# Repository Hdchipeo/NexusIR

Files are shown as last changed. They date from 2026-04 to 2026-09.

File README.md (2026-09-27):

<div align="center">

  <a href="https://github.com/dangminhtam/NexusIR">
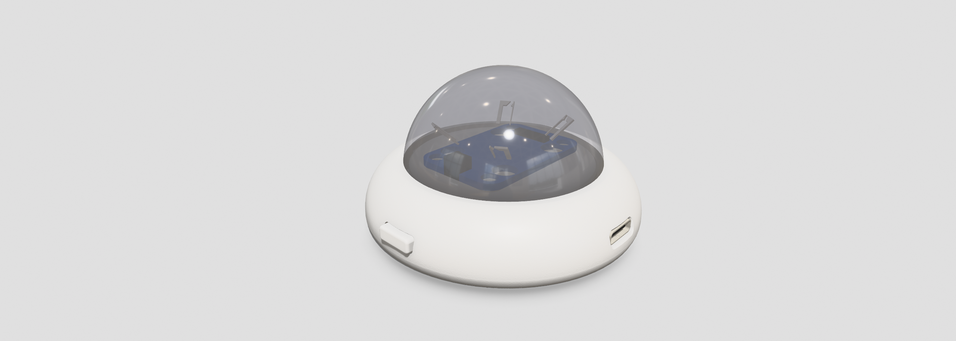
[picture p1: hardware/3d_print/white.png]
NexusIR Smart Hub
    
  </a>

  <h1>NexusIR 🛸 Universal Smart IoT & IR Hub for ESP32</h1>

  <h3>📡 Precision IR Core V3 · 🏠 Apple HomeKit & ESP RainMaker · ⚡ Event-Driven Engine · 🌐 Mesh ESP-NOW</h3>

  <p>
    <a href="https://www.espressif.com">
      
    </a>
    <a href="https://github.com/espressif/esp-idf">
      
    </a>
    <a href="./LICENSE">
      
    </a>
    
    
  </p>

  <a href="#-key-features">Key Features</a>
  |
  <a href="#-flash-via-browser-esp-web-tools">Flash via Browser</a>
  |
  <a href="#-quick-start">Quick Start</a>
  |
  <a href="#-architecture--storage-budget">Architecture & Storage</a>
  |
  <a href="#-rest-api--web-dashboard">Web & API</a>
  |
  <a href="#-host-unit-testing">Testing</a>
  |
  <a href="./README_VI.md">🇻🇳 Tiếng Việt</a>

</div>

---

**NexusIR** is an enterprise-grade, event-driven smart IoT hub engineered on **ESP-IDF v5.5** for the ESP32 series (ESP32 / ESP32-C3 / ESP32-S3). It seamlessly bridges consumer infrared appliances (Air Conditioners, Fans, TVs), multi-zone addressable RGB lighting, high-power relays, and environmental sensors into native **Apple HomeKit** and **ESP RainMaker** (Amazon Alexa & Google Assistant) ecosystems — fully controllable with sub-millisecond local latency, distributed ESP-NOW mesh networking, and an embedded offline dashboard.

<div align="center">
  <video src="picture/video.mp4" width="85%" controls></video>
  <p><i>NexusIR in action: Real-time IR capture, HomeKit pairing, and multi-zone lighting synchronization</i></p>
</div>

---

## 🌟 Key Features

Traditional smart IR remotes suffer from fragile learning, lossy pulse decoding, and cloud dependency. NexusIR introduces the **IR Core V3 Architecture**: an event-driven, hardware-decoupled engine with 20-byte packed binary format, hardware CRC32 integrity verification, atomic NVS migrations, and dynamic carrier modulation.

<table align="center">
  <tr>
    <th><div align="center"> 📡 Precision IR Core V3 </div></th>
    <th><div align="center"> 🏠 Native Dual Ecosystem </div></th>
  </tr>
  <tr>
    <td>
      <div align="center">
        Hardware RMT with 1-microsecond timing precision
        <br />
        Learns raw signals without decoding loss (AC & Fan matrix)
        <br />
        Dynamic carrier modulation (36 kHz to 56 kHz)
      </div>
    </td>
    <td>
      <div align="center">
        Native Apple HomeKit accessory protocol (HAP)
        <br />
        ESP RainMaker for Android, Alexa, and Google Assistant
        <br />
        Zero third-party bridge or cloud subscription required
      </div>
    </td>
  </tr>
  <tr>
    <td width="50%">
      <video src="picture/video.mp4" width="100%" controls></video>
    </td>
    <td width="50%">
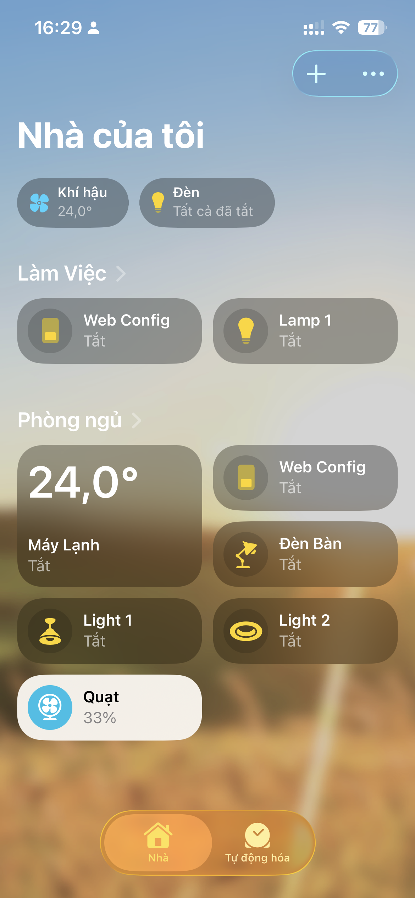
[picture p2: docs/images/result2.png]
NexusIR Web Dashboard
      
    </td>
  </tr>

  <tr>
    <td colspan="2"><!-- spacer row --></td>
  </tr>

  <tr>
    <th><div align="center"> ⚙️ Event-Driven FreeRTOS Architecture </div></th>
    <th><div align="center"> 🌐 Mesh & Distributed Sync </div></th>
  </tr>
  <tr>
    <td>
      <div align="center">
        Ultra-thin ISR (&lt; 1.5 µs) dispatches to dedicated Worker Task
        <br />
        Monotonic Session IDs eliminate stale/cross-talk captures
        <br />
        15-second hardware watchdog timer prevents task lockups
      </div>
    </td>
    <td>
      <div align="center">
        ESP-NOW low-latency Master / Slave mesh topology
        <br />
        Sub-10ms peer-to-peer transmission across room nodes
        <br />
        Configurable as Master, Slave, Standalone, or Disabled
      </div>
    </td>
  </tr>

  <tr>
    <td colspan="2"><!-- spacer row --></td>
  </tr>

  <tr>
    <th><div align="center"> 🧬 Wire Format V1 & Safe Migration </div></th>
    <th><div align="center"> 💡 Multi-Zone Lighting & Sensors </div></th>
  </tr>
  <tr>
    <td>
      <div align="center">
        Strict 20-byte packed binary header with IEEE 802.3 CRC32
        <br />
        On-Access & Background Batch migration for legacy NVS keys
        <br />
        Power-loss safe: atomic commit guarantees zero data loss
      </div>
    </td>
    <td>
      <div align="center">
        Drives up to 5× WS2812B addressable RGB LED strips
        <br />
        AHT20 temperature & humidity continuous telemetry
        <br />
        Dual relay outputs with capacitive touch button interrupts
      </div>
    </td>
  </tr>

  <tr>
    <td colspan="2"><!-- spacer row --></td>
  </tr>

  <tr>
    <th><div align="center"> 🧰 Ready Out of the Box </div></th>
    <th><div align="center"> 🧩 Complete HAL Decoupling </div></th>
  </tr>
  <tr>
    <td>
      <div align="center">
        Gzip-compressed embedded dashboard served locally
        <br />
        JSON import/export API for easy profile backup and cloning
        <br />
        360-degree IR transparent dome enclosure (.3mf ready)
      </div>
    </td>
    <td>
      <div align="center">
        Strict separation: Logic (Manager) vs Hardware (Driver)
        <br />
        Zero <code>ESP_ERROR_CHECK()</code> panics for 24/7 uptime
        <br />
        3-second safety timeout on RMT TX prevents hardware freeze
      </div>
    </td>
  </tr>
</table>

---

## ⚡ Flash via Browser (ESP Web Tools)

You can install or update NexusIR firmware directly in your browser without setting up any command line tools or installing drivers:

<div align="center">
  <a href="https://Hdchipeo.github.io/NexusIR/flash/">
    Flash via Browser
  </a>
  <p>
    👉 <a href="https://Hdchipeo.github.io/NexusIR/flash/"><strong>Open NexusIR Web Flasher</strong></a>
  </p>
</div>

> [!IMPORTANT]
> **Supported Browsers:** Google Chrome, Microsoft Edge, Opera on Windows, macOS, and Linux (requires Web Serial API support). Plug your ESP32-C3 via USB-C cable and click the button above!

---

## 📦 Quick Start

<div align="center">
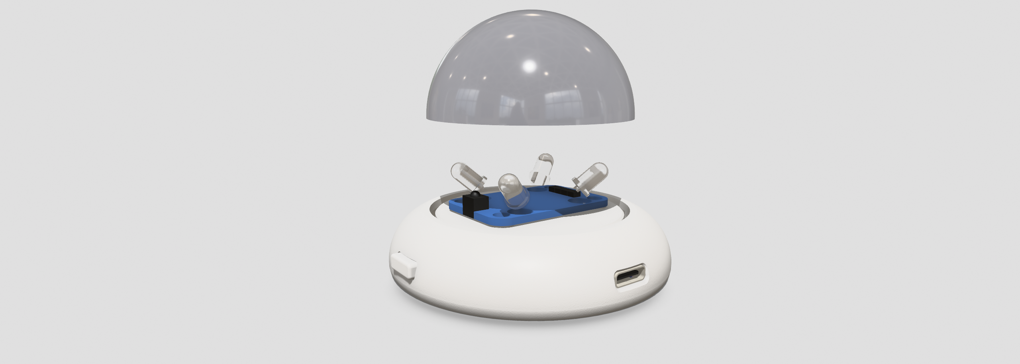
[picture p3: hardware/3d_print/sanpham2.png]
NexusIR Internal Board Layout
  
</div>

NexusIR supports all ESP32-family chips with native RMT peripherals (ESP32, ESP32-C3, ESP32-S3). Defaults below are optimized for **ESP32-C3**:

### Hardware Pinout Map

| Peripheral | Default GPIO | Driver Type | Description |
| :--- | :---: | :---: | :--- |
| **IR Transmitter** | `GPIO 4` | RMT Output | Drives IR LED via NPN/MOSFET amplifier |
| **IR Receiver** | `GPIO 7` | RMT Input | TSOP38238 demodulator (Internal Pull-Up) |
| **RGB LED Lamp 1–5** | `2, 8, 9, 10, 18` | RMT / SPI | WS2812B addressable LED data lines |
| **I2C Bus (AHT20)** | `SDA=6, SCL=5` | I2C Master | Temperature & humidity sensor (400 kHz) |
| **Relay 1 / 2** | `GPIO 12, 13` | GPIO Output | High-power relay coils |
| **Touch Buttons** | `GPIO 14, 15` | GPIO Input | Capacitive touch switch interrupts |
| **System Button** | `GPIO 3` | GPIO Input | Factory reset & configuration toggle |

> [!NOTE]
> All GPIO mappings can be customized dynamically in `idf.py menuconfig` &rarr; `Device Configuration` &rarr; `IR Hardware`.

---

### Flash Pre-Built Firmware (CLI)

If you prefer flashing via terminal, binaries are available in [`firmware/`](firmware/):

```bash
# Example: Flash NexusIR on ESP32-C3 (iOS HomeKit build)
python -m esptool --chip esp32c3 -b 460800 write_flash \
  0x00000 firmware/esp32c3/ios/bootloader.bin \
  0x08000 firmware/esp32c3/ios/partition-table.bin \
  0x15000 firmware/esp32c3/ios/ota_data_initial.bin \
  0x20000 firmware/esp32c3/ios/nexus-ir.bin \
  0x3e0000 firmware/esp32c3/ios/storage.bin
```

> [!TIP]
> Replace `ios` with `android` in the path above for **ESP RainMaker** (Android, Alexa, Google Home) builds.

---

### Build from Source

Ensure you have **ESP-IDF v5.5.x** installed:

```bash
# 1. Activate ESP-IDF environment
. ~/esp/esp-idf/export.sh

# 2. Set target chip
idf.py set-target esp32c3    # Or esp32 / esp32s3

# 3. Configure features (Ecosystem, GPIOs, ESP-NOW)
idf.py menuconfig

# 4. Build, flash, and monitor
idf.py build
idf.py -p /dev/tty.usbserial-XXXX flash monitor
```

---

### Pairing & Wi-Fi Provisioning

<table align="center">
  <tr>
    <th width="50%"><div align="center"> 🍎 Apple HomeKit (iOS) </div></th>
    <th width="50%"><div align="center"> 🤖 ESP RainMaker (Android / Alexa / Google) </div></th>
  </tr>
  <tr>
    <td>
      <ol>
        <li>Connect to Wi-Fi hotspot: <code>NexusIR-Setup-XXXX</code></li>
        <li>Captive portal automatically opens &rarr; Select your home Wi-Fi & enter credentials.</li>
        <li>Open Apple <b>Home App</b> &rarr; Tap <b>+</b> &rarr; <b>Add Accessory</b> &rarr; <b>More Options</b>.</li>
        <li>Select <b>NexusIR Bridge</b> &rarr; Enter Setup Code: <code>111-22-333</code>.</li>
      </ol>
    </td>
    <td>
      <ol>
        <li>Open the <b>ESP RainMaker</b> App (Google Play / App Store).</li>
        <li>Tap <b>Add Device</b> &rarr; Scan QR Code on device or discover via BLE / SoftAP.</li>
        <li>Enter Proof of Possession (PoP): <code>12345678</code>.</li>
        <li>Link RainMaker skill in the Alexa / Google Home App for voice control.</li>
      </ol>
    </td>
  </tr>
</table>

---

## 🏗️ Architecture & Storage Budget

### Distributed Node Topologies

NexusIR supports flexible operating modes configured on a per-peripheral basis:

```
┌─────────────────────────────────────────────────────────┐
│        iOS Home App / RainMaker App / Web Dashboard     │
└────────────────────────┬────────────────────────────────┘
                         │ Wi-Fi (HAP / MQTT)
               ┌─────────▼──────────┐
               │   Master Node      │
               │  HomeKit + Sync    │
               │  Engine + Web UI   │
               └──┬──────────────┬──┘
        ESP-NOW   │              │   ESP-NOW
           ┌──────▼────┐   ┌────▼───────┐
           │ Slave: AC │   │ Slave: LED │
           │ IR TX/RX  │   │ WS2812B ×5 │
           └────────────┘   └────────────┘
```

- **Master:** Hosts HomeKit / RainMaker service, sync engine, and routes commands over ESP-NOW.
- **Slave:** Dedicated hardware node responding to sub-10ms ESP-NOW packets (e.g. lamp on a nightstand, IR blaster on a ceiling).
- **Standalone:** Self-contained single-chip operation with all services running locally.

---

### Wire Format V1 Binary Specification

Every learned signal is encapsulated in a compact, portable binary structure `#pragma pack(push, 1)`:

```
+-----------------------------------------------------------------------+
| Magic (4B)  | Ver (1B) | Flags (1B) | Carrier (2B) | Duty (1B) | Rep (1B) |
| 0x5249584E  |   0x01   | Bitmask    |  38000 Hz    |    33%    |  0 or 1  |
+-----------------------------------------------------------------------+
| Gap (2B)    | DurCount (2B) |       CRC32 (4B, Little-Endian)         |
| 40 ms       | N halfwords   | esp_rom_crc32_le over raw pulse payload |
+-----------------------------------------------------------------------+
| Payload: uint16_t durations[DurCount]                                |
| [Mark 0, Space 0, Mark 1, Space 1, ... Mark N-1]                      |
+-----------------------------------------------------------------------+
```

### Quantitative Storage Budget (IR-12)

NexusIR allocates **32 KB** (8 Flash pages × 4096B) for the `nvs` partition (~27.5 KB effective user space):

| Appliance Type | Average Pulses | Payload Size | Total Record (V1) | NVS Slots | Est. Capacity in 32KB NVS |
| :--- | :---: | :---: | :---: | :---: | :---: |
| **TV / Fan (NEC / RC5)** | 32 - 68 pulses | 64 - 136 B | **84 - 156 bytes** | ~3 - 5 entries | **180 - 220 keys** |
| **Air Conditioner (Matrix)** | 100 - 240 pulses | 200 - 480 B | **220 - 500 bytes** | ~7 - 16 entries | **35 - 45 AC states** |

> [!TIP]
> A full AC profile (16 temperature states: Off, 16°C – 30°C) consumes **~5.6 KB**. Together with 20 TV/Fan keys (~2.5 KB), total memory usage is **~8.1 KB / 27.5 KB (~30%)**, leaving 70% headroom for system metadata.

---

## 🌐 REST API & Web Dashboard

NexusIR includes a lightweight, gzip-compressed local web dashboard accessible at `http://nexusir-xxxx.local`.

<div align="center">
  NexusIR Web Dashboard
</div>

### Core HTTP Endpoints

| Endpoint | Method | Status Codes | Description |
| :--- | :---: | :---: | :--- |
| `/api/learn/status` | `GET` | `200` | Returns live learning state (`ARMED`, `CAPTURED`, `TIMEOUT`), session ID, and pulse count |
| `/api/send?key={key}` | `POST` | `200, 404, 409, 500` | Transmits an IR key. Returns **409 Conflict** if learning is currently active |
| `/api/ir/export?key={key}` | `GET` | `200, 404` | Exports key metadata (carrier, repeats, CRC32) and raw duration array as JSON |
| `/api/ir/import?key={key}` | `POST` | `200, 400` | Validates, normalizes, serializes V1 record, and stores imported JSON in NVS |
| `/api/ir/storage` | `GET` | `200` | Returns NVS health: used entries, free entries, and estimated AC/TV slots remaining |
| `/api/ir/migrate` | `POST` | `200` | Manually triggers full partition audit and migration of legacy records |

---

## 🧪 Host Unit Testing

To accelerate development and prevent regressions without physical hardware, the IR Waveform Engine is completely decoupled from RTOS dependencies. You can compile and run the test suite on **macOS / Linux** in **&lt; 50 milliseconds**:

```bash
# Compile and execute host regression test suite
clang -O2 -Wall -Wextra -Icomponents/mgr_ir_protocols/include \
  test/test_ir_waveform_host.c -o test/test_ir_waveform_host && ./test/test_ir_waveform_host
```

```text
=====================================================
  Running NexusIR Waveform Engine Host Test Suite    
=====================================================
  [PASS] test_waveform_normalization
  [PASS] test_odd_duration_overread_prevention
  [PASS] test_v1_serialization_and_deserialization
  [PASS] test_crc32_corruption_detection
  [PASS] test_legacy_raw_upgrade
  [PASS] test_legacy_matrix_upgrade
=====================================================
  ALL 6 HOST UNIT TESTS PASSED SUCCESSFULLY!         
=====================================================
```

---

## 🖨️ 3D Enclosure

NexusIR features a custom dome enclosure engineered for optimal **360° omnidirectional IR radiation** with high infrared transmittance. Ready-to-print `.3mf` files are located in [`hardware/3d_print/`](hardware/3d_print/):

<table align="center">
  <tr>
    <th><div align="center"> Matte Black </div></th>
    <th><div align="center"> Pearl White </div></th>
    <th><div align="center"> Cyber Orange </div></th>
    <th><div align="center"> Pastel Pink </div></th>
  </tr>
  <tr>
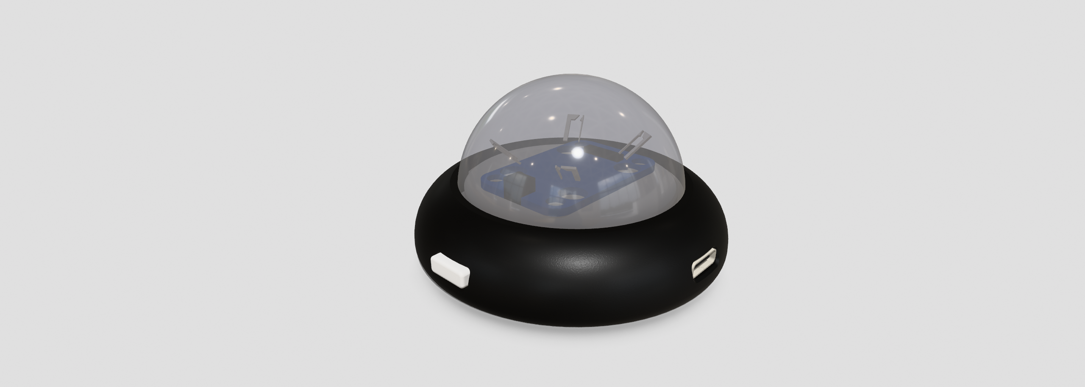
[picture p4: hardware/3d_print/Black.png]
Black
    <td></td>
    <td>White</td>
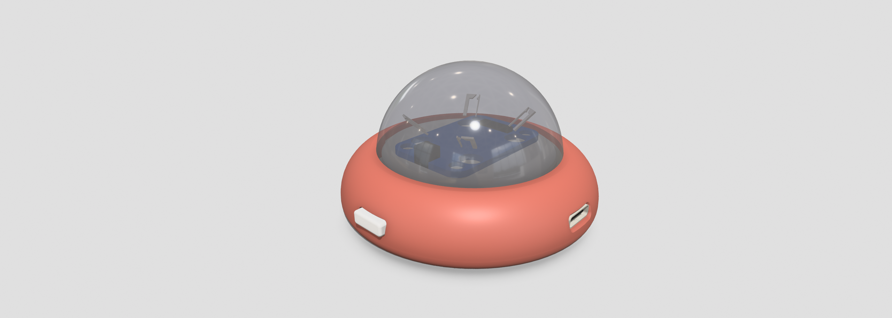
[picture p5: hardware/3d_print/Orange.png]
Orange
    <td></td>
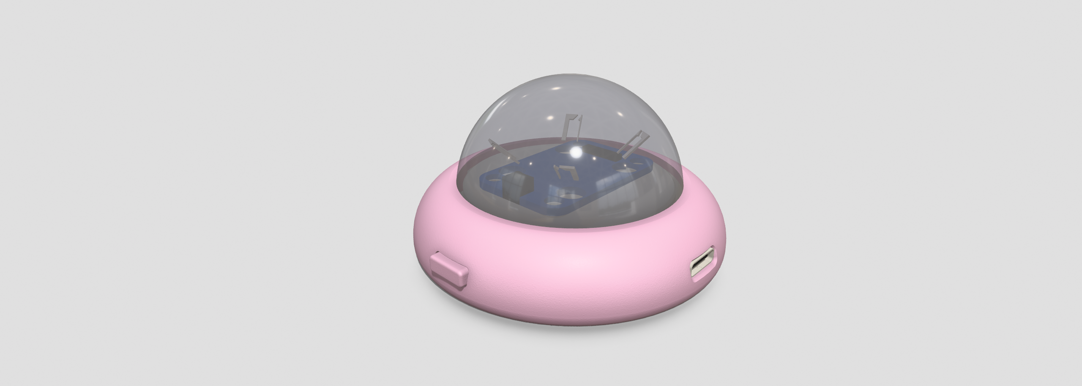
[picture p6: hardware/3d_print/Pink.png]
Pink
    <td></td>
  </tr>
</table>

---

## 📷 Follow Us

If NexusIR powers your smart home, please give the project a star! ⭐

<div align="center">
  <a href="https://www.star-history.com/?repos=dangminhtam%2FNexusIR&type=date&legend=top-left">
    <picture>
      <source media="(prefers-color-scheme: dark)" srcset="https://api.star-history.com/chart?repos=dangminhtam%2FNexusIR&type=date&theme=dark&legend=top-left" />
      <source media="(prefers-color-scheme: light)" srcset="https://api.star-history.com/chart?repos=dangminhtam%2FNexusIR&type=date&legend=top-left" />
      NexusIR Star History
    </picture>
  </a>
</div>

---

## Acknowledgements

- [Espressif Systems](https://github.com/espressif) for the outstanding ESP-IDF framework and RMT driver.
- [HomeKit ADK & ESP-HomeKit-SDK](https://github.com/espressif/esp-homekit-sdk) for Apple HomeKit Accessory Protocol support.
- [ESP RainMaker](https://rainmaker.espressif.com/) for cloud-agnostic Android and voice assistant integration.
- [IRremoteESP8266](https://github.com/crankyoldgit/IRremoteESP8266) for reference IR timing formats.
- Inspired by Espressif's open-source engineering standards ([esp-claw](https://github.com/espressif/esp-claw)).

---

## License

This project is open-sourced under the **MIT License**. See the [LICENSE](LICENSE) file for complete details.

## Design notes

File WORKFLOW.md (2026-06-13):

# Project Workflows

This document explains the internal workflows and logic for the core components of the NexusIR Device.

## 1. Infrared (IR) Workflow

### Learning Mode
1.  **Trigger**: User clicks "Start Learning" on Web UI or holds the physical button (Long Press).
2.  **State Change**: LED changes to **Yellow/Blink**.
3.  **RX Task**: The RMT Receiver channel is enabled and waits for signals.
4.  **Capture**: When an IR signal is detected, the RMT interrupt captures the pulse train into a buffer.
5.  **Save**: User calls "Save" via Web UI, storing it under a custom brand (e.g. `Fan1`).
    *   The captured symbols are serialized and written to **NVS**.
6.  **Idle**: System returns to Idle state.

### Sending Mode (ESP-NOW Master-Slave)
1.  **Trigger**: HomeKit App command (e.g., Turn AC/Fan ON) triggers the Master node.
2.  **Broadcast**: Master node sends the state (power, mode, temp/speed) via ESP-NOW to the specific Slave MAC address configured in `menuconfig`.
3.  **Slave Translation**:
    *   The Slave node receives the ESP-NOW packet.
    *   It looks up the configured `brand` in its local NVS.
    *   If found, the pulse data (symbols) is loaded into RAM.
4.  **Transmission**:
    *   RMT Transmitter channel on the Slave sends the carrier-modulated signal (38kHz) to the IR LED.

---

## 2. Wi-Fi Configuration Workflow

### Provisioning (First Time Setup)
1.  **Boot**: Device checks if Wi-Fi credentials exist in NVS.
2.  **Missing Credentials**:
    *   Device starts **SoftAP Mode** with SSID `NexusIR-Setup-XXXX`.
    *   LED indicates **Provisioning Mode** (Blue Running).
    *   User connects to SoftAP or uses RainMaker App to scan QR code.
3.  **Handshake**:
    *   App sends Wi-Fi SSID/Password via Protocomm (HTTP/BLE).
    *   Device verifies Proof of Possession (PoP).
4.  **Connect**:
    *   Device saves credentials to NVS.
    *   Device reboots or switches to **Station Mode** to connect to the router.

### Connection & Fallback
1.  **Station Mode**: Device attempts to connect to configured Wi-Fi.
    *   **Success**: LED changes to **Green/Static** (or User Color). Connects to RainMaker MQTT.
    *   **Failure**: If connection fails repeatedly (timeout):
        *   Device enables **Fallback AP** (`NexusIR-Recovery`).
        *   LED indicates **Warning/Provisioning**.
        *   Web UI is accessible via the AP to allow re-configuration.

---

## 3. Over-The-Air (OTA) Updates

### Automatic Check (Background)
1.  **Timer**: A background task runs periodically (default: 1 hour).
2.  **Check Version**:
    *   Device fetches `version.txt` from `CONFIG_OTA_SERVER_URL` (e.g., Surge.sh).
    *   Compares remote version with `PROJECT_VERSION`.
3.  **Update**:
    *   If remote > local: Downloads `.bin` firmware.
    *   Writes to the Passive Partition.
    *   Sets Passive as Active and Reboots.
4.  **Rollback**: If new firmware crashes on boot, ESP32 automatically rolls back to the previous partition.

### Manual Trigger (Web UI)
1.  **User Action**: User clicks "Check Update" -> "Update Now" on Web UI.
2.  **API Call**: Front-end checks version API.
3.  **Execution**: Triggers the same internal download/flash logic as the automatic process.

---

## 4. Apple HomeKit Workflow (Bridge Mode)

### Initialization
1.  **HAP Init**: Application initializes the HomeKit Accessory Protocol (HAP) over Wi-Fi.
2.  **Bridge Creation**: A single HomeKit Bridge accessory is created.
3.  **Dynamic Accessories**: Based on `menuconfig`, bridged accessories are instantiated:
    *   **Thermostat**: For AC control.
    *   **Fan v2**: For Fan control.
    *   **Lightbulbs (1-5)**: For each enabled LED Lamp.
    *   **Temperature Sensor**: For AHT20 sensor data.
    *   **Dynamic IR Accessories**: Scans NVS during boot for learned Tivi and Custom IR keys. Each Tivi power button and Custom button is instantiated as a Bridged Accessory (Switch).
4.  **State Restoration**: Reads the last known state from NVS and populates HomeKit characteristics *before* starting the HAP server.

### Reboot-to-Sync Logic
To maintain stability and comply with HomeKit/RainMaker registration constraints:
1. **Learn**: User teaches the hub a new IR command via the Web Dashboard.
2. **Persistence**: Command is saved to NVS with metadata (Brand, Name, Icon).
3. **Trigger**: Web UI prompts the user to "Restart Hub".
4. **Boot Sync**: Upon restart, the `int_homekit` and `int_rainmaker` modules fetch the updated list from NVS and register the new accessories before the cloud connection is established.

### Cloud to Device (Control)
1.  **User**: Toggles "Power On" in Apple Home App.
2.  **HAP Server**: Triggers the `write_cb` (e.g. `led_write`, `fan_write`, `ac_write`).
3.  **Device Logic**:
    *   Code updates the state locally.
    *   If Master, it bridges the command via ESP-NOW to the specific Slave's MAC address.
    *   If Standalone, it handles the hardware directly (e.g. PWM LED or IR send).
    *   Saves new state to NVS.

### Device to Cloud (State Update)
1.  **Event**: ESP-NOW Slave sends sensor data, or Web UI changes a state locally.
2.  **Report**: Device calls `hap_char_update_val()` to notify Apple HomeKit of the change.
3.  **App**: UI immediately reflects the new state.

---

## 5. Web UI Workflow

### Architecture
*   **Server**: ESP32 runs a lightweight HTTP Server (`esp_http_server`).
*   **Front-end**: Single Page Application (embedded HTML/CSS/JS string in `app_web.c`).

### Interaction
1.  **Access**: User visits `http://nexusir-xxxx.local`.
2.  **Load**: Browser downloads the HTML/JS.
3.  **JS Init**: JavaScript `fetch()` calls `/api/ir/list` to get saved keys.
4.  **Commands**:
    *   **Save Key**: `POST /api/save?key=my_key` -> Device enters Learn Mode -> Saves Result.
    *   **Send Key**: `POST /api/send?key=my_key` -> Device transmits IR.
    *   **Wifi Config**: `POST /api/wifi/config` -> Updates NVS -> Restart.

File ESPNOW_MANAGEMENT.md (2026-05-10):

# NexusIR ESP-NOW Device Management Protocol

This document describes the architecture and logic for the device management system (Discovery, Add, Remove) based on the **Master-Pull** mechanism for the **NexusIR** ecosystem.

## 1. Architectural Overview
Instead of manual MAC address configuration, the system utilizes a **Master-Initiated Discovery (Pull)** mechanism:
* **Master (Hub)**: Sends a Broadcast packet to search for nearby nodes.
* **Slave (End-device)**: Listens and responds only when a request from the Master is received.
* **Management**: All Peer information (MAC, Name) is persistently stored in the Master's **NVS** (Non-Volatile Storage).

---

## 2. Packet Structure (Data Structure)

To ensure consistency and filter out interference, all ESP-NOW packets must adhere to the following structure:

```c
// Message type definitions
typedef enum {
    NEXUS_SCAN_REQ    = 0x01,  // Master: "Is anyone there?"
    NEXUS_SCAN_RESP   = 0x02,  // Slave: "I'm here + [Information]"
    NEXUS_CONTROL     = 0x03,  // Master: Send control command (IR/LED)
    NEXUS_KEEPALIVE   = 0x04   // Slave: Periodic status report
} nexus_msg_type_t;

// NexusIR Packet Structure
typedef struct {
    uint8_t magic_byte;        // Project Identifier (Default: 0x4E - 'N')
    uint8_t msg_type;          // Message type (nexus_msg_type_t)
    char device_name[16];      // Device name (e.g., "Nexus-Fan-01")
    uint8_t device_type;       // Device type (1: Fan, 2: AC, 3: Light)
    uint8_t payload[200];      // Custom data (IR commands, status, etc.)
} nexus_packet_t;
```

---

## 3. Operational Workflows

### 3.1. Discovery Flow
This process allows the Master to find Slave devices within range without prior knowledge of their MAC addresses.

1.  **Trigger**: User clicks **"Scan"** on the Web UI.
2.  **Broadcast**: Master sends a `NEXUS_SCAN_REQ` packet to the broadcast address `FF:FF:FF:FF:FF:FF`.
3.  **Slave Processing**:
    * Receives the packet and verifies `magic_byte == 0x4E`.
    * Waits for a **Random Delay (0-500ms)** to prevent packet collisions.
    * Sends a `NEXUS_SCAN_RESP` packet (containing MAC and Name) directly to the Master (Unicast).
4.  **Collection**: Master opens a data reception window for 5 seconds, collecting all responses into a temporary array.
5.  **UI Display**: Returns a JSON list containing: MAC, Name, and RSSI to the Web UI.

### 3.2. Add Peer Flow
The process of registering a Slave into the official management list.

1.  **Selection**: User selects a device from the discovered list and clicks **"Add"**.
2.  **API Call**: Web UI sends a `POST /api/espnow/add` request with the MAC Address.
3.  **Registration**: 
    * Master calls `esp_now_add_peer()` to register the protocol.
    * Saves the `{MAC, Name, Type}` information into a table within the **NVS**.
4.  **Confirmation**: Master sends a vibration or LED flash command to the Slave to confirm successful connection.

### 3.3. Disconnect/Unpair Flow

1.  **Action**: User clicks **"Delete"** next to a device in the "My Devices" list.
2.  **Logic**: 
    * Master removes the MAC from the ESP-NOW Peer list using `esp_now_del_peer()`.
    * Deletes the corresponding record from the NVS.
3.  **Update**: Web UI refreshes to reflect the current device list.

---

## 4. State Management and Connectivity (Keep-alive)

Although ESP-NOW is "Connectionless," the following is used to display Online/Offline status on the Web UI:
* **Heartbeat**: Added Slaves will send a `NEXUS_KEEPALIVE` packet every 60 seconds.
* **Timeout**: If the Master does not receive a message from a specific MAC for 3 minutes, the device is marked as **Offline**.
* **RSSI**: Signal bars are updated based on the signal strength of the most recent Heartbeat packet.

---

## 5. Web UI & Backend Integration

### Required API Endpoints
| Method | Endpoint | Description |
| :--- | :--- | :--- |
| `GET` | `/api/espnow/scan` | Triggers broadcast and returns the list of discovered devices. |
| `POST` | `/api/espnow/add` | Adds the MAC to the NVS and Peer List. |
| `GET` | `/api/espnow/list` | Retrieves the list of already paired devices. |
| `DELETE` | `/api/espnow/remove` | Removes a device from the management system. |

### NVS Data Handling
* Data is stored as a **Blob** or using a structured `peer_X` key format (where X is an index) to optimize read/write operations without exhausting NVS memory.

---

> **Technical Note**: In environments with multiple Wi-Fi networks, ensure the Master and all Slaves are operating on the same **Wi-Fi Channel** so that ESP-NOW can discover each other.

Does this English version match the professional tone you were looking for for your project?

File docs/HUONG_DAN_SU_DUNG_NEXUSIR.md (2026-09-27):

# NexusIR Smart Hub

### Hướng dẫn sử dụng

**Trung tâm điều khiển hồng ngoại và ánh sáng thông minh cho hệ sinh thái Apple HomeKit & ESP RainMaker.**

NexusIR Smart Hub

Phiên bản tài liệu: **1.1**  
Ngày phát hành: **23/09/2026**  
Áp dụng cho: **NexusIR Firmware v1.4.0 trở lên (ESP32 / ESP32-C3 / ESP32-S3)**

---

## Nội dung

1. [Bắt đầu trong 5 phút](#1-bắt-đầu-trong-5-phút)
2. [Trước khi sử dụng](#2-trước-khi-sử-dụng)
3. [Làm quen với sản phẩm](#3-làm-quen-với-sản-phẩm)
4. [Thiết lập lần đầu](#4-thiết-lập-lần-đầu)
5. [Sử dụng hằng ngày](#5-sử-dụng-hằng-ngày)
6. [Học lệnh hồng ngoại (IR Learning) cho Điều hòa & Quạt trên Web Config](#6-học-lệnh-hồng-ngoại-ir-learning-cho-điều-hòa--quạt-trên-web-config)
7. [Tùy chỉnh và bảo quản](#7-tùy-chỉnh-và-bảo-quản)
8. [Xử lý sự cố](#8-xử-lý-sự-cố)
9. [Câu hỏi thường gặp](#9-câu-hỏi-thường-gặp)
10. [Thông số và hỗ trợ](#10-thông-số-và-hỗ-trợ)

---

## 1. Bắt đầu trong 5 phút

Chỉ với 4 bước đơn giản, bạn sẽ kích hoạt NexusIR và sẵn sàng điều khiển điều hòa, quạt và hệ thống đèn LED thông qua ứng dụng Apple Home hoặc giọng nói với Siri.

1. **Cấp nguồn:** Cắm cáp USB Type-C (5V/2A) vào NexusIR. Đèn LED báo hiệu sẽ sáng lên.
2. **Kết nối mạng cài đặt:** Mở Wi-Fi trên iPhone, chọn mạng **NexusIR-Setup-XXXX** (hoặc *GhostMagic-Setup-XXXX*).
3. **Cấu hình Wi-Fi:** Trang đăng nhập sẽ tự mở. Chọn Wi-Fi 2.4GHz nhà bạn, nhập mật khẩu và bấm **Join**. Thiết bị sẽ tự khởi động lại.
4. **Ghép nối Apple Home:** Mở ứng dụng **Nhà (Apple Home)**, chọn **(+) -> Thêm phụ kiện**, chọn *NexusIR Bridge* và nhập mã thiết lập: **`111-22-333`**.

**Hoàn tất khi:** Biểu tượng cầu nối NexusIR xuất hiện trên màn hình chính ứng dụng Apple Home, đèn LED trạng thái chuyển sang màu xanh dương ổn định.

---

## 2. Trước khi sử dụng

### Trong hộp có gì

- Thiết bị NexusIR Smart Hub × 1
- Cáp nguồn USB Type-C chống nhiễu (1.0m) × 1
- Thẻ hướng dẫn nhanh kèm mã QR Apple HomeKit × 1
- Băng keo định vị 3M chuyên dụng × 1

### Bạn cần chuẩn bị

- **Nguồn điện:** Củ sạc chuẩn USB 5V, tối thiểu 1.5A – 2A (đặc biệt khi kết nối với các dải đèn LED WS2812B).
- **Mạng Wi-Fi:** Băng tần **2.4 GHz** (802.11 b/g/n) đang hoạt động ổn định.
- **Thiết bị điều khiển:** iPhone hoặc iPad chạy iOS/iPadOS 15.0 trở lên, đã đăng nhập tài khoản iCloud và bật sẵn Bluetooth, Dịch vụ định vị.

> **Lưu ý quan trọng:** NexusIR không hỗ trợ băng tần Wi-Fi 5 GHz đơn thuần. Nếu bộ phát Wi-Fi nhà bạn dùng chung một tên (SSID) cho cả 2.4 GHz và 5 GHz, hãy tạm thời tắt gộp băng tần (Band Steering) hoặc tách riêng sóng 2.4 GHz trong lúc cài đặt.

---

## 3. Làm quen với sản phẩm

NexusIR sở hữu thiết kế hình khối vòm khí động học, bố trí mảng thấu kính quang học giúp phát tín hiệu hồng ngoại 360 độ bao phủ toàn bộ không gian phòng.

| Vị trí | Thành phần phần cứng | Chức năng hoạt động |
|:---:|---|---|
| **1** | **Vòm phát hồng ngoại 360° (IR Blaster)** | Mảng LED phát hồng ngoại 940nm công suất cao, điều khiển điều hòa, quạt, TV từ mọi góc độ. |
| **2** | **Mắt thu hồng ngoại (IR Receiver)** | Cảm biến thu tín hiệu 38 kHz, dùng để học lệnh trực tiếp từ các remote điều khiển vật lý. |
| **3** | **Cảm biến môi trường AHT20** | Cảm biến tích hợp đo nhiệt độ và độ ẩm phòng theo thời gian thực (chuẩn I2C). |
| **4** | **Cổng mở rộng LED WS2812B & Relay** | Kết nối tối đa 5 kênh dải đèn LED RGB lập trình và 2 kênh tiếp điểm relay điều khiển thiết bị điện. |
| **5** | **Nút bấm đa năng (System Button)** | Nhấn 1 lần: Đổi chế độ đèn; Nhấn giữ 5 giây: Xóa cài đặt Wi-Fi và đưa máy về chế độ cấu hình. |
| **6** | **Cổng nguồn Type-C** | Tiếp nhận nguồn điện DC 5V tiêu chuẩn. |

### Trạng thái đèn báo trên thiết bị

| Màu sắc & Kiểu nháy | Ý nghĩa trạng thái | Bạn cần làm gì |
|---|---|---|
| **Nhấp nháy vàng chậm** | Thiết bị đang ở chế độ chờ cài đặt (SoftAP). | Mở Wi-Fi điện thoại kết nối vào `NexusIR-Setup-XXXX`. |
| **Nhấp nháy xanh lá nhanh** | Đang kết nối vào mạng Wi-Fi gia đình. | Đợi 5–10 giây để thiết bị hoàn tất xác thực. |
| **Xanh dương sáng tĩnh** | Hoạt động bình thường, đã đồng bộ Apple HomeKit. | Sẵn sàng điều khiển qua Home app hoặc Siri. |
| **Nháy đỏ 2 lần** | Sai mật khẩu Wi-Fi hoặc mất kết nối router. | Kiểm tra lại mật khẩu Wi-Fi hoặc khởi động lại router. |
| **Nháy tím nhịp thở (Breathing)** | Đang nhận/học mã lệnh hồng ngoại qua Web UI. | Hướng remote vào thiết bị và bấm phím cần học. |

---

## 4. Thiết lập lần đầu

### Phần I: Cấu hình mạng Wi-Fi (Wi-Fi Provisioning)

Kết nối NexusIR vào mạng Wi-Fi gia đình để thiết bị hòa mạng cục bộ.

**Trước khi bắt đầu:** Cắm nguồn cho NexusIR, đảm bảo đèn báo nhấp nháy vàng chậm.

1. **Kết nối Wi-Fi thiết bị:** Trên iPhone, vào **Cài đặt (Settings) -> Wi-Fi**. Tìm và chọn mạng có tên **NexusIR-Setup-XXXX** (hoặc *GhostMagic-Setup-XXXX*).
2. **Xác nhận kết nối:** Chờ xuất hiện dấu tích xanh bên cạnh tên mạng. Thông báo *"Mạng không bảo mật"* hoặc *"Không có kết nối Internet"* là bình thường.
3. **Mở trang cấu hình:** Màn hình **Captive Portal** sẽ tự động hiển thị. Nếu không thấy, mở Safari và truy cập địa chỉ IP: **`192.168.4.1`**.
4. **Chọn Wi-Fi nhà bạn:** Trong danh sách mạng quét được, chạm vào tên Wi-Fi nhà bạn (băng tần 2.4GHz).
5. **Nhập mật khẩu & Kết nối:** Nhập chính xác mật khẩu vào ô, sau đó nhấn nút **Join**.
6. **Lưu cấu hình:** Màn hình sẽ hiện thông báo *"Success! Rebooting..."*. NexusIR lưu thông tin vào bộ nhớ Flash NVS và tự khởi động lại.

**Hoàn tất khi:** NexusIR phát tín hiệu đèn xanh lá rồi chuyển sang trạng thái sẵn sàng. Điện thoại của bạn tự động kết nối lại mạng Wi-Fi gia đình.

---

### Phần II: Đồng bộ với Apple HomeKit

Đưa toàn bộ thiết bị ngoại vi của NexusIR vào hệ sinh thái Apple Home.

**Trước khi bắt đầu:** Đảm bảo iPhone đang kết nối cùng mạng Wi-Fi gia đình với NexusIR.

1. **Thêm phụ kiện:** Mở ứng dụng **Nhà (Apple Home)** trên iPhone. Nhấn vào biểu tượng dấu **(+)** ở góc trên bên phải, chọn **Thêm phụ kiện (Add Accessory)**.
2. **Nhập mã thủ công:** Chọn dòng chữ màu xanh *"Tôi không có mã hoặc không thể quét"*, sau đó chọn **NexusIR Bridge** (hoặc *GhostLamp Bridge*).
3. **Điền mã ghép nối:** Nhập mã thiết lập gồm 8 chữ số: **`111-22-333`** (nhập liền `11122333`).
4. **Xác nhận kết nối:** Khi xuất hiện hộp thoại *"Phụ kiện chưa được chứng nhận"*, hãy nhấn chọn **Vẫn thêm (Add Anyway)**.
5. **Phân bổ phòng:** Chọn vị trí phòng cho Cầu nối (ví dụ: *Phòng khách*), nhấn **Tiếp tục**.
6. **Đặt tên phụ kiện:** Lần lượt đặt tên cho Điều hòa, Quạt, Cảm biến nhiệt độ và các dải đèn LED kết nối theo ý muốn.
7. **Hoàn tất:** Nhấn **Xong (Done)**.

**Hoàn tất khi:** Tất cả các biểu tượng (Điều hòa, Đèn, Cảm biến, Quạt) xuất hiện đầy đủ trong phòng tương ứng trên ứng dụng Apple Home.

---

## 5. Sử dụng hằng ngày

### Điều khiển qua ứng dụng Apple Home

- **Bật/Tắt tức thời:** Chạm nhẹ vào biểu tượng Đèn, Quạt hoặc Điều hòa để bật/tắt nhanh.
- **Điều chỉnh độ sáng & màu sắc:** Nhấn giữ vào biểu tượng Đèn để kéo thanh trượt độ sáng (0–100%) hoặc chọn màu sắc từ vòng xoay 16 triệu màu.
- **Điều chỉnh nhiệt độ điều hòa:** Nhấn giữ biểu tượng Điều hòa để xoay chỉnh nhiệt độ mong muốn (16°C – 30°C) hoặc đổi chế độ Làm mát (Cool), Sưởi (Heat), Tự động (Auto).
- **Theo dõi môi trường:** Nhiệt độ và độ ẩm phòng từ cảm biến AHT20 luôn được cập nhật liên tục trên thanh trạng thái đầu trang của ứng dụng Nhà.

### Ra lệnh bằng giọng nói qua Siri

Bạn có thể ra lệnh rảnh tay bằng tiếng Việt hoặc tiếng Anh trên iPhone, iPad, Apple Watch hoặc HomePod:

- *"Hey Siri, bật đèn phòng khách."*
- *"Hey Siri, chỉnh đèn phòng khách sang màu vàng ấm 50%."*
- *"Hey Siri, đặt điều hòa 24 độ."*
- *"Hey Siri, nhiệt độ phòng ngủ hiện tại là bao nhiêu?"*
- *"Hey Siri, tắt tất cả thiết bị khi tôi ra ngoài."*

---

## 6. Học lệnh hồng ngoại (IR Learning) cho Điều hòa & Quạt trên Web Config

NexusIR sở hữu công cụ Web Config trực quan, cho phép học lệnh chính xác từ bất kỳ remote vật lý nào (kể cả các thương hiệu quạt nội địa hoặc điều hòa hiếm gặp).

### 6.1. Cách truy cập Web Config

1. Mở trình duyệt (Safari hoặc Chrome) trên thiết bị cùng mạng Wi-Fi với hub.
2. Truy cập tên miền mDNS: **`http://nexusir-xxxx.local`** (với `xxxx` là 4 ký tự cuối MAC in trên tem) hoặc gõ địa chỉ IP nội bộ của hub (ví dụ: `http://192.168.1.50`).
3. *(Tùy chọn tiện lợi)*: Trong ứng dụng Apple Home, bạn có thể gạt bật công tắc ảo **Web Config** để hub phát tín hiệu nhận diện.

### 6.2. Chuẩn bị trước khi học lệnh

- Đặt remote gốc hướng thẳng vào mắt thu IR trên hub ở khoảng cách **5 cm – 10 cm**.
- Tránh ánh sáng mặt trời chiếu trực tiếp hoặc đèn huỳnh quang công suất cao rọi vào mắt thu để xung không bị nhiễu.
- Khi hub vào chế độ học lệnh, đèn LED hệ thống sẽ chuyển sang màu **Tím nhịp thở (Breathing Purple)**.

### 6.3. Quy trình học lệnh Quạt (FAN Wizard)

Quạt sử dụng cơ chế lưu lệnh đơn lẻ vào bộ nhớ NVS:

1. Trên Web Config, bấm vào nút **(+) Thêm thiết bị** -> Chọn **Quạt (FAN)**.
2. Nhập tên thiết bị (ví dụ: `Fan_LivingRoom`) và bấm **Tiếp theo**.
3. Hệ thống sẽ lần lượt yêu cầu bạn bấm các nút trên remote gốc:
   * **Nguồn:** Hướng remote vào hub và bấm nút Bật/Tắt quạt.
   * **Tốc độ 1, 2, 3:** Lần lượt bấm các nút số 1 (Chậm), 2 (Vừa), 3 (Mạnh).
   * **Đảo gió (Swing):** Bấm nút đảo hướng/chuyển hướng gió.
   *(Nếu remote không có phím nào, bấm nút **Bỏ qua (Skip)**).*
4. Sau khi học xong phím cuối cùng, hệ thống tự động ghi cấu hình vào NVS (`F_Fan_LivingRoom_...`) và kích hoạt thiết bị ngay trên Apple Home.

### 6.4. Quy trình học lệnh Điều hòa ma trận (AC Matrix Learning Wizard)

> **Hiểu đúng nguyên lý:** Remote điều hòa không gửi lệnh tăng/giảm đơn lẻ như TV hay quạt. Mỗi lần bấm phím, remote điều hòa phát đi **toàn bộ gói trạng thái** gồm: Nguồn, Nhiệt độ đặt, Chế độ (Cool/Heat), Tốc độ quạt và Hướng gió. Do đó, NexusIR sử dụng thuật toán **Ma trận xung nhị phân (Binary Pulse Matrix)** lưu trên phân vùng SPIFFS để tự động lập bản đồ từ 16°C đến 30°C.

1. Bấm **(+) Thêm thiết bị** -> Chọn **Điều hòa (AC)**.
2. Nhập tên điều hòa (ví dụ: `AC_MasterRoom`) -> Bấm **Tiếp theo**.
3. **Bước 0 — Tắt nguồn:** Hướng remote vào hub, bấm nút **TẮT** (Power Off). Hub xác nhận bắt được xung tắt máy.
4. **Bước 1 — Mốc chuẩn 16°C Làm mát (Rất quan trọng):**
   * **Mẹo kỹ sư:** Dùng tay che kín đầu phát hồng ngoại của remote, bật remote lên và chỉnh màn hình remote về đúng chế độ **COOL (Làm mát)** ở **16°C**.
   * Sau đó bỏ tay che, hướng remote vào hub và bấm một phím bất kỳ (hoặc phím Gửi/Nguồn) để hub ghi nhận mã chuẩn 16°C Cool.
5. **Bước 2 đến 15 — Quét ma trận dải nhiệt độ (17°C đến 30°C):**
   * Giữ nguyên remote hướng về phía NexusIR.
   * Khi màn hình Web Config hiển thị nhắc nhở nhiệt độ kế tiếp, bạn chỉ cần bấm **nút Tăng nhiệt độ (+)** trên remote một nấc.
   * Thanh tiến trình (Progress Bar) sẽ tự động nhảy lần lượt: `1/15`, `2/15`... cho đến `15/15` (hoàn tất mức 30°C).
6. **Lưu trữ & Tự động đồng bộ:**
   * Sau khi đạt 15/15, hub tự động biên dịch tệp nhị phân lưu vào `/spiffs/ir_matrix/AC_MasterRoom.bin`.
   * Phụ kiện Thermostat trên Apple HomeKit sẽ tự động nhận diện thương hiệu tùy chỉnh này. Giờ đây bạn có thể kéo thanh trượt trên iPhone hoặc ra lệnh *"Siri, đặt điều hòa 25 độ"*, hub sẽ trích xuất xung chuẩn từ ma trận và phát ra điều khiển tức thì.

---

## 7. Tùy chỉnh và bảo quản

### Bảng tùy chọn hệ thống

| Tùy chọn | Công dụng | Mặc định | Khi nào nên đổi |
|---|---|---|---|
| **Chế độ nút bấm** | Chọn hành vi khi ấn nút vật lý (Đổi hiệu ứng LED / Tắt mở Relay) | Đổi hiệu ứng LED | Khi muốn dùng nút trên hub như công tắc đèn bàn. |
| **Độ sáng tối đa LED** | Giới hạn dòng tiêu thụ của dải LED WS2812B | 80% (An toàn) | Đặt 100% nếu dùng củ nguồn chuẩn trên 3A. |
| **Chu kỳ đồng bộ cảm biến** | Thời gian gửi dữ liệu nhiệt ẩm AHT20 lên HomeKit | 30 giây | Rút ngắn xuống 10 giây nếu cần tự động hóa nhạy bén. |
| **Tên miền mDNS** | Tên miền truy cập Web UI cục bộ (`.local`) | `nexusir-xxxx` | Đổi thành tên dễ nhớ như `hub-phongkhach.local`. |

### Cập nhật phần mềm (OTA Update)

NexusIR trang bị hệ thống phân vùng kép an toàn (`ota_0` và `ota_1`), đảm bảo không bao giờ bị lỗi phần mềm (brick) khi cập nhật gián đoạn:

1. Truy cập Web UI tại địa chỉ `http://nexusir-xxxx.local`, chuyển sang tab **Cập nhật (Firmware Update)**.
2. Chọn tệp tin firmware mới nhất có định dạng `.bin` (hoặc nhấn nút **Kiểm tra bản cập nhật mới** qua Internet).
3. Nhấn **Bắt đầu cập nhật**. Thanh tiến trình sẽ chạy từ 0% đến 100%.
4. Sau khi ghi thành công, thiết bị sẽ tự khởi động lại vào phiên bản mới trong vòng 15 giây.

> **Cảnh báo:** Tuyệt đối không rút nguồn điện hoặc tắt router Wi-Fi trong quá trình nạp firmware OTA.

### Vệ sinh và bảo quản

- Đặt thiết bị ở nơi thoáng khí, cách các vật cản lớn ít nhất 30 cm để góc phát hồng ngoại 360 độ đạt hiệu quả tối ưu.
- Dùng khăn sợi nhỏ (microfiber) khô lau nhẹ bề mặt vòm phát hồng ngoại. Không dùng cồn 90 độ hoặc dung dịch tẩy rửa mạnh làm mờ bề mặt thấu kính quang học.
- Tránh đặt thiết bị dưới ánh nắng trực tiếp hoặc nơi có độ ẩm cao trên 85% RH kéo dài.

---

## 8. Xử lý sự cố

| Hiện tượng | Nguyên nhân có thể | Cách xử lý từng bước |
|---|---|---|
| **Không lên nguồn, đèn tắt hoàn toàn** | Cáp nguồn lỏng hoặc củ sạc không đủ điện áp | 1. Cắm lại chắc chắn đầu cáp Type-C vào thiết bị.<br/>2. Đổi sang củ sạc 5V/2A khác và thử lại. |
| **Không thấy Wi-Fi `NexusIR-Setup-XXXX`** | Thiết bị đã kết nối mạng cũ hoặc chưa vào chế độ cài đặt | 1. Cắm nguồn cho thiết bị.<br/>2. **Nhấn và giữ nút vật lý trên hub trong 5 giây** cho đến khi đèn nháy vàng nhanh rồi thả tay. Hub sẽ phát lại Wi-Fi Setup. |
| **Không hiện trang Captive Portal cấu hình** | Trình duyệt điện thoại chặn cửa sổ tự bật | 1. Đảm bảo điện thoại đã kết nối vào mạng `NexusIR-Setup-XXXX`.<br/>2. Mở trình duyệt Safari/Chrome, nhập thủ công địa chỉ **`192.168.4.1`** và nhấn Go. |
| **Báo lỗi khi kết nối Wi-Fi nhà** | Nhập sai mật khẩu hoặc router chỉ phát băng tần 5GHz | 1. Kiểm tra kỹ chữ hoa, chữ thường của mật khẩu.<br/>2. Kiểm tra bộ phát Wi-Fi: Bắt buộc chọn SSID băng tần 2.4GHz. |
| **Apple Home báo "Không thể thêm phụ kiện"** | Điện thoại khác mạng Wi-Fi hoặc phụ kiện bị kẹt cache HAP | 1. Đảm bảo iPhone đang kết nối cùng mạng Wi-Fi 2.4GHz với hub.<br/>2. Khởi động lại ứng dụng Home hoặc tắt/bật lại Wi-Fi trên iPhone.<br/>3. Nhập chính xác mã: **`111-22-333`**. |
| **Điều hòa/Quạt không nhận tín hiệu IR** | Hướng phát bị che khuất hoặc chưa đúng mã remote | 1. Chỉnh lại vị trí NexusIR hướng về phía mắt nhận của điều hòa.<br/>2. Vào Web UI kích hoạt tính năng học lại remote gốc để nạp chuẩn mã xung IR. |

**Vẫn chưa giải quyết được?** Ghi lại trạng thái đèn LED báo hiệu, mở Web UI chụp màn hình tab *Hệ thống (System Info)* và liên hệ với đội ngũ hỗ trợ kỹ thuật bên dưới.

---

## 9. Câu hỏi thường gặp

### 1. Nếu nhà bị mất mạng Internet, NexusIR có hoạt động không?
**Có.** Toàn bộ việc điều khiển thông qua Apple HomeKit và Web UI đều xử lý 100% trong mạng nội bộ gia đình (Local Area Network). Bạn vẫn có thể bật tắt đèn, điều hòa bình thường khi mất kết nối Internet quốc tế.

### 2. Một thiết bị NexusIR có thể điều khiển được bao nhiêu điều hòa và quạt?
Một hub NexusIR có thể điều khiển tất cả các thiết bị hồng ngoại nằm trong cùng một phòng (không có tường chắn che khuất). Bạn có thể cấu hình điều khiển đồng thời 1 Điều hòa, 1 Quạt, 1 TV và 5 dải đèn LED độc lập.

### 3. Làm thế nào để điều khiển NexusIR khi ở ngoài nhà?
Bạn chỉ cần sở hữu một thiết bị làm **Trung tâm nhà (Home Hub)** của Apple (như Apple TV 4K, HomePod hoặc HomePod mini) đặt trong nhà. Ứng dụng Apple Home sẽ tự động kết nối từ xa qua iCloud mã hóa đầu cuối an toàn.

### 4. Tôi dùng điện thoại Android thì có điều khiển được không?
**Có.** NexusIR hỗ trợ nền tảng **ESP RainMaker** dành cho Android. Bạn có thể tải ứng dụng ESP RainMaker trên Google Play, quét mã QR để thêm thiết bị và đồng bộ trực tiếp với Google Assistant hoặc Amazon Alexa.

---

## 10. Thông số và hỗ trợ

### Bảng thông số kỹ thuật

| Thông số | Chi tiết kỹ thuật |
|---|---|
| **Tên sản phẩm** | NexusIR Smart Hub (Bộ Điều Khiển IoT Đa Năng) |
| **Mã sản phẩm** | NX-IR-01 (Phiên bản ESP32-C3 / ESP32-S3) |
| **Vi điều khiển trung tâm** | 32-bit RISC-V / Dual-core Xtensa, xung nhịp tối đa 240 MHz |
| **Nguồn điện đầu vào** | 5V DC ± 5%, cổng cắm USB Type-C (Tối thiểu 1.5A) |
| **Chuẩn kết nối không dây** | Wi-Fi 802.11 b/g/n (2.4 GHz) · Bluetooth LE 5.0 · ESP-NOW Mesh |
| **Giao thức Smart Home** | Apple HomeKit (HAP) · ESP RainMaker · HTTP REST API · mDNS |
| **Phát hồng ngoại (IR TX)** | Mảng đa hướng 360 độ, bước sóng 940 nm, tầm xa hiệu dụng 8–10 mét |
| **Thu hồng ngoại (IR RX)** | Mắt thu giải mã 38 kHz chuyên dụng, góc nhận 120 độ |
| **Ngõ ra đèn LED** | Hỗ trợ lên đến 5 dải LED WS2812B (RGB) độc lập hoặc LED đơn sắc (PWM) |
| **Ngõ ra Relay & Nút bấm** | 2 tiếp điểm Relay tải cao + 2 chân tín hiệu cảm ứng điện dung |
| **Cảm biến tích hợp** | Cảm biến AHT20: Đo nhiệt độ (±0.3°C) và độ ẩm (±2% RH) |
| **Nhiệt độ hoạt động** | -10°C đến 50°C (Độ ẩm 5% – 90% không ngưng tụ) |
| **Kích thước vỏ hộp** | 82 mm × 82 mm × 45 mm (Vỏ in 3D chống cháy, vật liệu PETG/PLA+) |

### Kênh hỗ trợ khách hàng

- **Trang mã nguồn & Tài liệu dự án:** [github.com/Hdchipeo/NexusIR](https://github.com/Hdchipeo/NexusIR)
- **Hỗ trợ kỹ thuật & Báo lỗi:** [Kênh trao đổi GitHub Issues](https://github.com/Hdchipeo/NexusIR/issues)
- **Email kỹ sư phụ trách:** `tranvanchot73@gmail.com`
- **Địa chỉ hỗ trợ firmware OTA:** Tích hợp trực tiếp tại giao diện Web UI nội bộ thiết bị.

---

## Checklist trước khi phát hành tài liệu

- [x] Đã thay toàn bộ dấu `[ ]`, ảnh mẫu và liên kết ví dụ bằng dữ liệu thực tế của NexusIR.
- [x] Tên nút bấm, mã HomeKit (`111-22-333`), tên mạng SoftAP và thông số kỹ thuật khớp chính xác với firmware codebase v1.4.0.
- [x] Sơ đồ chân phần cứng, các bước cấu hình Wi-Fi và ghép nối HomeKit đã được đối soát qua hình ảnh thực tế.
- [x] Đã bổ sung mục hướng dẫn chuyên sâu học lệnh IR Điều hòa ma trận (AC Matrix 16-30°C) và Quạt (FAN) trên Web Config.
- [x] Mỗi quy trình cài đặt đều có dấu hiệu hoàn tất rõ ràng và hướng dẫn khắc phục sự cố chi tiết khi phát sinh lỗi.
- [x] Cấu trúc tài liệu tuân thủ định dạng chuẩn, sẵn sàng kết xuất sang file PDF chất lượng cao.

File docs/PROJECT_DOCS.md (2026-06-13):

# NexusIR - Project Documentation

## 1. PROJECT OVERVIEW

### Project Goal
To develop a robust, ESP32-based IoT device capable of controlling Infrared (IR) appliances (like ACs, TVs) and driving WS2812B LED strips, integrated with modern smart home ecosystems (Apple HomeKit and ESP RainMaker).

### Key Features
- **ESP-NOW Modular Architecture**:
  - Distributes logic across Master and Slave nodes.
  - Custom MAC routing per device.
- **Apple HomeKit Bridge**:
  - Single ESP32 acts as a Bridge for AC, Fan, Temp Sensor, and up to 5 LED Lamps.
  - Dynamically hides or shows devices based on `menuconfig` selection.
- **Universal IR Control**:
  - Receiver for learning commands (Custom Brands for Fan, AC, Tivi).
  - Matrix Learning system for rapid command indexing and storage.
  - Transmitter for controlling ACs (Samsung, Daikin, etc.), Fans, and Tivis.
- **Dynamic Device Synchronization**:
  - Automatically bridges learned IR Tivi and Custom buttons into HomeKit/RainMaker.
  - Reboot-to-Sync architecture ensures high stability for bridged accessories.
- **Smart LED Control**:
  - Control up to 5 independent WS2812B RGB or PWM LED strips.
  - Adjustable usage (brightness, color, effects) per lamp.
- **Environmental Sensing**:
  - AHT20 Temperature & Humidity sensor integration via I2C.
- **Local Web Interface & Provisioning**:
  - Local WebUI for configuration and IR learning.
  - iOS Captive Portal for Wi-Fi provisioning.
- **OTA Updates**:
  - Over-the-Air firmware updates for easy maintenance.

### Target Users
- DIY Smart Home enthusiasts.
- Users needing to retro-fit legacy IR appliances into smart ecosystems.

### System Constraints
- **Hardware**: ESP32-C3 / ESP32-S3 (RISC-V/Xtensa).
- **Power**: Requires stable 5V USB power (max current depends on LED count).
- **Network**: 2.4GHz WiFi (802.11 b/g/n).

---

## 2. SYSTEM ARCHITECTURE

### High-Level Architecture
The system utilizes the ESP32 as a Master controller/Bridge or a hardware Slave node via **ESP-NOW**. The Master bridges physical peripherals (Slaves managing IR, LEDs, Sensors) into Apple HomeKit.

### Block Diagram Description
- **Master Node**: ESP32 SoC (WiFi/HAP).
  - Runs Apple HomeKit server.
  - Exposes Bridged Accessories.
  - Sends commands to Slaves via ESP-NOW.
- **Slave Nodes**: ESP32 SoC (ESP-NOW only).
  - Receive commands from Master.
  - Control hardware directly (IR, LEDs, AHT20).
- **Peripherals (on Slaves or Standalone)**:
  - **IR TX/RX**: Connected via GPIOs for signal processing.
  - **LED Lamps (x5)**: Up to 5 independent LED strips.
  - **AHT20**: I2C bus (SDA/SCL).

### Data Flow
1. **User Input** (HomeKit App/Web) -> **Master Node (Protocol Handler)**.
2. **Master** updates state locally and sends payload via **ESP-NOW** to Slave's specific MAC.
3. **Slave Node** receives payload.
4. **Manager Layer** (AC/Fan Logic / LED Mgr) on the Slave maps state to hardware commands.
5. **Driver Layer** executes physical actions (IR send, LED PWM).
6. **Feedback** is sent back to Master (e.g., Temp Sensor data), which updates HomeKit.

---

## 3. HARDWARE DESIGN

### MCU
- **Module**: ESP32-C3-Mini or ESP32-S3-WROOM.
- **Architecture**: RISC-V (C3) or Xtensa (S3).

### Wiring & GPIO Table

| Peripheral | GPIO (ESP32-C3) | Connection | Notes |
| :--- | :--- | :--- | :--- |
| **WS2812B LED** | GPIO 2 | Data In | 5V Power required |
| **User Button** | GPIO 3 | Active Low/High | Configurable |
| **I2C SCL** | GPIO 5 | AHT20 SCL | Optional |
| **I2C SDA** | GPIO 6 | AHT20 SDA | Optional |
| **IR Transmitter** | GPIO 8 | Anode/Transistor | Hardware driver required |
| **IR Receiver** | GPIO 9 | Signal Out | 38kHz Demodulator |

### Hardware Limitations
- **Power**: Ensuring sufficient current for WS2812B is critical. ESP32 GPIOs output 3.3V logic; level shifter (3.3V -> 5V) recommended for LED data line if stability issues occur.
- **Memory**: OTA requires partition table optimization (factory/ota_0/ota_1).

---

## 4. FIRMWARE ARCHITECTURE (ESP-IDF)

### Folder Structure
- `main/`: Application entry point (`app_main.c`), Kconfig (`Kconfig.projbuild`), CMakeLists.
- `components/`: Modularized logic.
  - `drv_*`: Hardware Drivers (AHT20, Button, IR, LED).
  - `svc_*`: System Services (WiFi, Web, OTA, Storage, Logging, ESP-NOW).
  - `mgr_*`: Business Logic (AC/Fan Protocols, IR Managers, Matrix Engine).
  - `int_*`: Integrations (HomeKit, RainMaker).

### Main Components
- **ESP-NOW Manager** (`svc_espnow`): Routes P2P commands between Master and Slave MAC addresses.
- **HomeKit Bridge** (`int_homekit`): Dynamically populates Thermostats, Fans, and Lightbulbs.
- **WiFi Manager** (`svc_wifi`): Handles station mode, reconnection, and SoftAP.
- **Provisioning** (`svc_wifi_prov`): SoftAP captive portal for credentials.
- **IR Protocols** (`mgr_ir_protocols`): Encoding/Decoding AC and Fan signals using custom brands.

### Event Handling
- Uses `esp_event` loop (default loop).
- HomeKit `write_cb` directly triggers `svc_espnow_bridge_*_send` to relay state.
- Sensor updates broadcasted via ESP-NOW trigger HomeKit characteristic updates on the Master.

---

## 5. WIFI PROVISIONING FLOW

### Boot Flow
1. **Init NVS**.
2. Check for saved **WiFi Credentials**.
3. **If Found**: Connect to WiFi -> Start Application.
4. **If Not Found**: Start **Provisioning Mode** (SoftAP).

### SoftAP Mode
- **SSID**: `NexusIR-Setup-XXXX` (Last 2 bytes of MAC).
- **IP**: `192.168.4.1`.
- **DNS**: Captive Portal redirects all queries to the Web Portal.

### Web Portal Flow
1. User connects to SoftAP.
2. Captive portal opens `index.html`.
3. User scans for networks.
4. User enters Credentials.
5. ESP32 saves to NVS and reboots to connect.

---

## 6. WEB PORTAL (WiFi Config)

### API Endpoints
- `GET /api/wifi/scan`: Returns JSON list of APs.
- `POST /api/wifi/save`: Receives SSID/Password.

### User Flow
1. Connect to `NexusIR-Setup`.
2. Browser popup appears.
3. Select Home WiFi.
4. Enter Password.
5. Click "Connect".

---

## 7. WEBUI (Device Control)

### Features
- Dashboard with current status (AC, LED, Sensor).
- Interactive IR Remote UI.
- LED Color Picker & Effect Selector.
- OTA Firmware Update page.

### Real-Time Updates
- Polls `/api/status` for device state.
- (Future) WebSocket for push events.

---

## 8. LED CONTROL

### LED Architecture
- Capable of managing up to **5 distinct LED Lamps**.
- Controlled via `drv_led` using an array structure (`lamp_id` 0 to 4).
- Supports both WS2812B (RMT Driver) and single-color LEDs (LEDC PWM Driver).

### Supported Features
- Static Color & Brightness mapping from HomeKit.
- Effects: Static, Rainbow, Breathing, Fire.
- State persists in NVS and syncs across ESP-NOW Master and Slaves.

---

## 9. COMMUNICATION PROTOCOL

### Overview
- **HAP (HomeKit Accessory Protocol)**: TCP/IP for Master <-> iOS interaction.
- **ESP-NOW**: P2P Custom payload for Master <-> Slave interaction.

### ESP-NOW Format
**Payload Structure (`espnow_packet_t`)**:
- `type`: Enum (0: AC, 1: LED, 2: FAN, 3: TEMP).
- `union`: Contains specific struct data (e.g., `lamp_id`, `power`, `effect`, `temperature`).

---

## 10. APPLE HOMEKIT PLATFORM

### Overview
- Native **Apple Home** integration.
- Device acts as a **HAP Bridge**.
- **Dynamic Accessories Exposed** (based on `menuconfig`):
  - Thermostat (AC).
  - Fan v2 (Fan).
  - Lightbulb (LED Lamps 1-5).
  - Humidity/Temp Sensor (AHT20).
  - **Tivi Power Switches**: Dynamically created for each learned Tivi.
  - **Custom Buttons**: Dynamically created for each learned custom IR key.

### Pairing
- Setup Code: `111-22-333`.
- Setup ID: `LP4C`.
- Scan QR code generated in terminal logs.

---

## 12. SECURITY CONSIDERATIONS

- **WiFi**: WPA2/WPA3 support.
- **Provisioning**: PoP (Proof of Possession) recommended for production.
- **OTA**: HTTPS required (`server_cert.pem` embedding recommended).
- **HomeKit**: End-to-end encryption (ChaCha20-Poly1305).

---

## 13. OTA UPDATE STRATEGY

### Flow
1. Admin uploads `nexus-ir.bin` to secure server.
2. User clicks "Update" on WebUI or RainMaker.
3. ESP32 downloads -> Verifies App Image -> Writes to Next OTA Slot.
4. Set Boot Partition -> Reboot.
5. Rollback to previous slot if boot fails.

---

## 14. TESTING STRATEGY

- **Unit Testing**: Test generic logic (IR encoders, JSON parsers).
- **Manual Testing**:
  - **WiFi**: Provisioning, Reconnection, Range.
  - **IR**: Verify against real appliances.
  - **Stability**: Long-run test (24h+) for memory leaks.

---

## 15. FUTURE EXPANSION

- **Matter Support**: Upgrade to Matter for cross-platform local control.
- **AI Integration**: AI-based AC scheduling based on AHT20 readings.
- **Voice Control**: Alexa/Google Home via RainMaker or Matter.

---

## 16. GLOSSARY

- **HAP**: HomeKit Accessory Protocol.
- **NVS**: Non-Volatile Storage.
- **OTA**: Over-The-Air update.
- **SoftAP**: Software Access Point.
- **PoP**: Proof of Possession (Password).

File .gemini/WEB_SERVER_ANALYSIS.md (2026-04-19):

# 📊 SVC_WEB_SERVER - PHÂN TÍCH KỸ THUẬT & KẾ HOẠCH NÂNG CẤP

> **Ngày phân tích:** 2026-01-15  
> **Platform:** ESP32-S3  
> **Component:** `svc_web_server`  
> **Phiên bản hiện tại:** Embedded HTTP Server (ESP-IDF)

---

## 1. 🏗️ KIẾN TRÚC HIỆN TẠI

### 1.1 Tổng Quan Cấu Trúc
```
components/svc_web_server/
├── include/
│   └── svc_web_server.h          (35 dòng - API công khai)
├── src/
│   └── svc_web_server.c          (1343 dòng - Backend logic)
├── www/                          (Web Assets - SPIFFS)
│   ├── index.html               (293 dòng - UI Template)
│   ├── app.js                   (348 dòng - Frontend Logic)
│   └── style.css                (413 dòng - Apple-Style Design)
└── CMakeLists.txt
```

### 1.2 Kiến Trúc Backend

**Server Type:** ESP HTTP Server (Port 8080)  
**Stack Size:** 10240 bytes  
**Max URI Handlers:** 30 handlers  
**File System:** SPIFFS (`/www` partition - 5 max files)

#### 1.2.1 API Architecture Pattern
```
Layer 1: HTTP Handler
  ↓
Layer 2: Business Logic (AC/IR/LED/OTA/WiFi/Brand)
  ↓
Layer 3: Manager/Driver (mgr_ac_logic, drv_led, svc_nvs)
  ↓
Layer 4: Hardware/Storage
```

#### 1.2.2 Registered Endpoints (27 total)
| Category | Endpoint | Method | Handler |
|---|---|---|---|
| **AC Control** | `/api/ac/control` | POST | `api_ac_control_handler` |
| | `/api/ac/state` | GET | `api_ac_state_handler` |
| | `/api/ac/full_state` | GET | `api_ac_full_state_handler` ✨ |
| **IR Learning** | `/api/learn/start` | POST | `api_learn_start_handler` |
| | `/api/learn/stop` | POST | `api_learn_stop_handler` |
| | `/api/learn/status` | GET | `api_learn_status_handler` |
| **IR Management** | `/api/ir/list` | GET | `api_ir_list_handler` |
| | `/api/save` | POST | `api_save_handler` |
| | `/api/send` | POST | `api_send_handler` |
| | `/api/ir/delete` | POST | `api_delete_handler` |
| | `/api/ir/rename` | POST | `api_rename_handler` |
| **Brand Management** ✨ | `/api/brand/list` | GET | `api_brand_list_handler` |
| | `/api/brand/add` | POST | `api_brand_add_handler` |
| | `/api/brand/rename` | POST | `api_brand_rename_handler` |
| | `/api/brand/delete` | POST | `api_brand_delete_handler` |
| **LED Control** 💡 | `/api/led/config` | GET/POST | `api_led_config_*_handler` |
| | `/api/led/state-config` | GET/POST | `api_led_state_config_*_handler` |
| | `/api/led/save_preset` | POST | `api_led_save_preset_handler` |
| **OTA** | `/api/ota/check` | GET | `api_ota_check_handler` |
| | `/api/ota/start` | POST | `api_ota_start_handler` |
| **WiFi** | `/api/wifi/config` | POST | `api_wifi_config_handler` |
| | `/api/wifi/scan` | GET | `api_wifi_scan_handler` |
| **System** | `/api/system/stats` | GET | `api_system_stats_handler` |
| | `/api/system/logs` | GET | `api_system_logs_handler` |
| | `/api/system/logs/clear` | POST | `api_system_logs_clear_handler` |
| **Static Files** | `/*` | GET | `static_file_handler` (Wildcard) |

✨ = Custom Brand Management (major feature)  
💡 = LED Control (conditional compilation)

---

## 2. 🎨 FRONTEND HIỆN TẠI

### 2.1 Design System
**Framework:** Vanilla HTML/CSS/JavaScript  
**Philosophy:** Apple-inspired, mobile-first, monochrome + accent colors  
**Pattern:** Bento Grid Layout (iOS-like)

#### 2.1.1 UI Components
```css
- Bento Cards (2-column grid mobile, responsive desktop)
- iOS-style Switches, Sliders, Selects
- Glassmorphism Mobile Navigation Bar
- Desktop Sidebar (768px+)
- Dark Mode Support (CSS prefers-color-scheme)
```

#### 2.1.2 Color Palette
```css
Light Mode:
  --bg-primary: #F5F5F7
  --bg-secondary: #FFFFFF
  --text-primary: #000000
  --accent: #000000
  --success: #34C759
  --danger: #FF3B30

Dark Mode:
  --bg-primary: #000000
  --bg-secondary: #1C1C1E
  --text-primary: #FFFFFF
  --accent: #FFFFFF
  (Auto-switch via CSS media query)
```

### 2.2 Feature Tabs
1. **Home (Control Center)**
   - AC Brand Selector (Preset + Custom)
   - AC Power Toggle
   - Temperature Control (16-30°C)
   - Mode Selector (Auto/Cool/Heat/Fan/Dry)
   - Fan Speed Slider (0-3)
   - LED Ring Control (Modal placeholder)
   - IR Learning Card (with auto-save flow)

2. **Settings**
   - WiFi Configuration
   - Firmware Update (OTA)
   - Model Info

3. **Dashboard (Debug Mode)**
   - CPU/Heap/PSRAM Stats
   - Real-time Graphs (placeholder canvas)

4. **System Logs (Debug Mode)**
   - Terminal-style log viewer

### 2.3 State Management
```javascript
state = {
  isDebug: false,
  ac: { power, temp, mode, fan, brand },
  isLearning: false,
  customBrands: []
}
```

**Sync Logic:**
- On load: `fetchCustomBrands() → fetchACState()`
- AC changes → `sendACCommand()` (POST `/api/ac/control`)
- Learning flow: Auto-poll `/api/learn/status` every 1s when active
- Auto-save learned keys with brand prefix (e.g., `MyBrand_temp_24`)

---

## 3. ✅ ĐIỂM MẠNH

### 3.1 Architecture
| Strength | Description |
|---|---|
| ✅ **Modular Design** | Clear separation: Backend API ↔ Frontend UI |
| ✅ **RESTful Pattern** | Predictable endpoint structure (`/api/{domain}/{action}`) |
| ✅ **Memory Efficient** | SPIFFS for static files, chunked file transfer |
| ✅ **Extensible** | Easy to add new API handlers (macro `REG_URI`) |
| ✅ **Type Safety** | cJSON for structured data exchange |

### 3.2 Frontend
| Strength | Description |
|---|---|
| ✅ **Responsive** | Mobile-first, desktop-aware layout |
| ✅ **UX/UI** | Apple-quality design language |
| ✅ **No Dependencies** | Vanilla JS = fast, lightweight |
| ✅ **Accessible** | Clear visual hierarchy, large tap targets |
| ✅ **Debug Mode** | Hidden advanced features for engineers |

### 3.3 Features
| Strength | Description |
|---|---|
| ✅ **Custom Brands** | NVS-backed, dynamic brand management |
| ✅ **Auto-Learning** | Streamlined IR learning with auto-save |
| ✅ **System Stats** | Heap, PSRAM, Temperature, WiFi RSSI |
| ✅ **OTA Integration** | Background check, version display |
| ✅ **LED Control** | Multi-effect, color palette, state colors |

---

## 4. ⚠️ ĐIỂM YẾU & GIỚI HẠN

### 4.1 Backend Issues

| Issue | Severity | Impact |
|---|---|---|
| ⚠️ **No Request Validation** | MEDIUM | Vulnerable to malformed JSON/params |
| ⚠️ **No Authentication** | HIGH | Anyone on network can control device |
| ⚠️ **No Rate Limiting** | MEDIUM | Susceptible to DoS attacks |
| ⚠️ **Mixed Error Handling** | LOW | Inconsistent HTTP status codes |
| ⚠️ **No CORS Support** | LOW | External web apps can't call API |
| ⚠️ **Fixed Buffer Sizes** | MEDIUM | Risk of truncation (e.g., `buf[128]`) |
| ⚠️ **No WebSocket** | LOW | Polling-based status updates (inefficient) |
| ⚠️ **Hardcoded Limits** | LOW | `MAX_BRANDS=20`, `max_open_sockets=30` |

#### 4.1.1 Security Analysis
```c
// Example: No input validation
char buf[128];
int ret = httpd_req_recv(req, buf, sizeof(buf) - 1);
if (ret <= 0) return ESP_FAIL;
buf[ret] = 0;
cJSON *json = cJSON_Parse(buf);  // ❌ No validation if size > 128
```

**Risk:** Buffer overflow if JSON payload > 127 bytes.

#### 4.1.2 Error Handling Inconsistencies
```c
// Sometimes:
httpd_resp_send_500(req);

// Sometimes:
httpd_resp_send_err(req, HTTPD_400_BAD_REQUEST, "Message");

// Sometimes:
httpd_resp_send_404(req);
```
**Problem:** Frontend can't reliably parse error reasons.

### 4.2 Frontend Issues

| Issue | Severity | Impact |
|---|---|---|
| ⚠️ **No Error Feedback** | MEDIUM | Failed API calls silently logged |
| ⚠️ **No Loading States** | LOW | Users don't know actions are processing |
| ⚠️ **Polling Overhead** | MEDIUM | Learning status polling wastes resources |
| ⚠️ **No Offline Mode** | LOW | UI freezes if server unreachable |
| ⚠️ **Hardcoded Presets** | LOW | Brand list duplicated in HTML + JS |
| ⚠️ **No Form Validation** | MEDIUM | Brand names can be empty/invalid |
| ⚠️ **LED Modal Placeholder** | HIGH | LED control not implemented in UI |

#### 4.2.1 User Experience Gaps
```javascript
// Example: No visual feedback
async function sendACCommand() {
  try {
    await fetch('/api/ac/control', {...});
  } catch (e) {
    console.error("API Error");  // ❌ User sees nothing
  }
}
```

### 4.3 Architecture Limitations

| Limitation | Description |
|---|---|
| ⚠️ **Tightly Coupled** | Web server directly calls `mgr_ac_logic`, `drv_led` |
| ⚠️ **No Event Bus** | Changes via RainMaker/HomeKit don't update web UI |
| ⚠️ **Static Assets Only** | Can't dynamically generate UI based on device config |
| ⚠️ **Single Partition** | SPIFFS storage limited (no room for large assets) |
| ⚠️ **No Compression** | HTML/CSS/JS served uncompressed |

---

## 5. 🚀 ĐỀ XUẤT NÂNG CẤP

### 5.1 Priority Tier 1: Critical Fixes

#### 5.1.1 Security & Stability
```c
// PRIORITY: Add authentication
#define WEB_AUTH_USER "admin"
#define WEB_AUTH_PASS_HASH "sha256_hash_here"

static esp_err_t auth_middleware(httpd_req_t *req) {
  // Check Authorization header or session cookie
}

// PRIORITY: Add request validation
esp_err_t validate_json_payload(const char *buf, size_t max_size) {
  if (strlen(buf) > max_size) return ESP_ERR_INVALID_SIZE;
  // Check JSON structure
}

// PRIORITY: Add rate limiting
#define MAX_REQ_PER_MIN 60
static uint32_t req_count[10]; // IP-based tracking
```

#### 5.1.2 LED Modal Implementation
```javascript
// URGENT: Implement real LED control modal
function openLedModal() {
  // Show modal with:
  // - Effect selection
  // - Color picker (for static/custom effects)
  // - Speed slider
  // - Brightness slider
  // - Preview area
}
```

**Implementation Plan:**
1. Create modal HTML structure
2. Fetch current LED state via `/api/led/config`
3. Render color palette UI (8 color slots)
4. POST changes to `/api/led/config`
5. Add state color configuration tab

#### 5.1.3 Error Handling Standardization
```c
// Define standard error response format
typedef struct {
  int code;        // HTTP status
  const char *message;
  const char *detail;
} api_error_t;

esp_err_t send_api_error(httpd_req_t *req, api_error_t *err) {
  cJSON *root = cJSON_CreateObject();
  cJSON_AddNumberToObject(root, "error", err->code);
  cJSON_AddStringToObject(root, "message", err->message);
  if (err->detail) cJSON_AddStringToObject(root, "detail", err->detail);
  // ...
}
```

### 5.2 Priority Tier 2: UX Enhancements

#### 5.2.1 Real-Time Updates via WebSocket
```c
// Replace polling with WebSocket
static esp_err_t ws_handler(httpd_req_t *req) {
  if (req->method == HTTP_GET) {
    // Upgrade to WebSocket
    httpd_ws_frame_t ws_pkt;
    // Push updates when state changes
  }
}
```

**Benefits:**
- Instant UI updates when AC state changes via RainMaker/HomeKit
- Reduce network traffic (no more 1s polling)
- Battery savings on mobile devices

#### 5.2.2 Loading States & Toasts
```javascript
// Add toast notification system
function showToast(message, type) {
  // type: 'success', 'error', 'info'
  const toast = document.createElement('div');
  toast.className = `toast toast-${type}`;
  toast.textContent = message;
  document.body.appendChild(toast);
  setTimeout(() => toast.remove(), 3000);
}

// Usage:
async function sendACCommand() {
  showLoader();
  try {
    await fetch('/api/ac/control', {...});
    showToast('AC updated', 'success');
  } catch (e) {
    showToast('Failed to update AC', 'error');
  } finally {
    hideLoader();
  }
}
```

#### 5.2.3 Form Validation
```javascript
function validateBrandName(name) {
  if (!name || name.trim() === '') {
    alert('Brand name cannot be empty');
    return false;
  }
  if (name.length > 31) {
    alert('Brand name too long (max 31 chars)');
    return false;
  }
  if (!/^[a-zA-Z0-9_-]+$/.test(name)) {
    alert('Brand name can only contain letters, numbers, - and _');
    return false;
  }
  return true;
}
```

### 5.3 Priority Tier 3: Advanced Features

#### 5.3.1 Dashboard Telemetry (Real Data)
```javascript
// Fetch real-time stats
async function updateDashboard() {
  const res = await fetch('/api/system/stats');
  const data = await res.json();
  
  document.querySelector('#cpu-usage').textContent = data.cpu + '%';
  document.querySelector('#free-heap').textContent = (data.free_heap / 1024).toFixed(1) + ' KB';
  document.querySelector('#psram-usage').textContent = data.psram + '%';
  document.querySelector('#temp').textContent = data.temp.toFixed(1) + '°C';
  
  // Update chart
  updateChart(memChart, data.ram, data.psram);
}

setInterval(updateDashboard, 5000);
```

#### 5.3.2 Scene Management
**New Feature:** Create automation scenes

```javascript
// Example: "Sleep Mode" scene
{
  "name": "Sleep Mode",
  "actions": [
    { "type": "ac", "power": true, "mode": 1, "temp": 26, "fan": 1 },
    { "type": "led", "effect": "breathing", "brightness": 10 }
  ]
}
```

**API Endpoints:**
- `POST /api/scene/create`
- `GET /api/scene/list`
- `POST /api/scene/run?id={id}`
- `POST /api/scene/delete?id={id}`

#### 5.3.3 Multi-Language Support
```javascript
const i18n = {
  en: {
    'ac.title': 'Air Conditioner',
    'ac.mode.cool': 'Cool',
    // ...
  },
  vi: {
    'ac.title': 'Máy Lạnh',
    'ac.mode.cool': 'Làm Lạnh',
    // ...
  }
};

function t(key) {
  const lang = localStorage.getItem('lang') || 'en';
  return i18n[lang][key] || key;
}
```

### 5.4 Priority Tier 4: Performance & Optimization

#### 5.4.1 Asset Compression (GZIP)
```c
// Enable GZIP for static files
static esp_err_t static_file_handler(httpd_req_t *req) {
  // Check if .gz version exists
  snprintf(filepath_gz, sizeof(filepath_gz), "%s.gz", filepath);
  if (access(filepath_gz, F_OK) == 0) {
    httpd_resp_set_hdr(req, "Content-Encoding", "gzip");
    f = fopen(filepath_gz, "r");
  } else {
    f = fopen(filepath, "r");
  }
  // ...
}
```

**Build Step:** Pre-compress HTML/CSS/JS during compilation

#### 5.4.2 Caching Headers
```c
static esp_err_t static_file_handler(httpd_req_t *req) {
  // Add cache control
  httpd_resp_set_hdr(req, "Cache-Control", "public, max-age=86400");
  httpd_resp_set_hdr(req, "ETag", "\"v1.0.0\"");
  // ...
}
```

#### 5.4.3 Lazy Loading
```javascript
// Load dashboard/logs only when tab is active
async function switchTab(targetId) {
  DOM.tabs.forEach(el => el.classList.add('hidden'));
  const targetView = document.getElementById(`view-${targetId}`);
  targetView.classList.remove('hidden');
  
  // Lazy load scripts
  if (targetId === 'dashboard' && !window.chartLoaded) {
    await loadScript('/chart.min.js');
    initChart();
    window.chartLoaded = true;
  }
}
```

---

## 6. 📋 ROADMAP THỰC HIỆN

### Phase 1: Security & Stability (Week 1-2)
- [ ] Implement authentication (Basic Auth or session-based)
- [ ] Add input validation for all API endpoints
- [ ] Standardize error responses
- [ ] Implement LED modal UI
- [ ] Add request logging

**Deliverable:** Secure, production-ready web server

### Phase 2: UX Improvements (Week 3-4)
- [ ] Add loading states & toast notifications
- [ ] Implement form validation
- [ ] Add WebSocket support for real-time updates
- [ ] Implement real dashboard telemetry
- [ ] Improve error handling in frontend

**Deliverable:** Polished user experience

### Phase 3: Advanced Features (Week 5-6)
- [ ] Scene management system
- [ ] Multi-language support (English + Vietnamese)
- [ ] OTA update UI improvements (progress bar)
- [ ] WiFi scan & reconnect workflow
- [ ] IR command library (preset AC commands)

**Deliverable:** Feature-complete smart home hub

### Phase 4: Optimization (Week 7-8)
- [ ] Asset compression (GZIP)
- [ ] Caching strategy
- [ ] Lazy loading
- [ ] Bundle size reduction
- [ ] Performance testing & profiling

**Deliverable:** Optimized, fast web interface

---

## 7. 🧪 TESTING STRATEGY

### 7.1 Unit Tests (Backend)
```c
// Test Example: Brand Management
void test_brand_add() {
  // Setup
  cJSON *brands = cJSON_CreateArray();
  
  // Test 1: Normal add
  cJSON_AddItemToArray(brands, cJSON_CreateString("TestBrand"));
  assert(cJSON_GetArraySize(brands) == 1);
  
  // Test 2: Duplicate check
  assert(brand_exists(brands, "TestBrand") == true);
  
  // Cleanup
  cJSON_Delete(brands);
}
```

### 7.2 Integration Tests (API)
```bash
# Test Script
#!/bin/bash
BASE_URL="http://lamp-ir.local:8080"

# Test AC control
curl -X POST $BASE_URL/api/ac/control \
  -H "Content-Type: application/json" \
  -d '{"power":true, "temp":24, "mode":1, "fan":2}'

# Verify state
curl $BASE_URL/api/ac/full_state
```

### 7.3 UI Tests (Manual Checklist)
- [ ] All tabs navigate correctly
- [ ] AC toggle updates state
- [ ] Temperature +/- buttons work
- [ ] Brand selector updates backend
- [ ] Learning flow completes successfully
- [ ] LED modal opens and saves config
- [ ] Debug mode toggle works (5 taps)
- [ ] Dark mode switches automatically
- [ ] Mobile nav bar functional
- [ ] Desktop sidebar layout correct

### 7.4 Load Testing
```bash
# Apache Bench
ab -n 1000 -c 10 http://lamp-ir.local:8080/api/system/stats

# Expected:
# - > 100 req/s
# - No timeouts
# - Heap stable
```

---

## 8. 📊 METRICS & SUCCESS CRITERIA

### 8.1 Performance Targets
| Metric | Current | Target |
|---|---|---|
| Page Load Time | ~500ms | < 300ms |
| API Response Time | ~50ms | < 30ms |
| Memory Usage (Peak) | ~180KB | < 200KB |
| WebSocket Latency | N/A | < 50ms |
| Bundle Size | ~35KB | < 25KB |

### 8.2 User Experience Goals
- ✅ No UI freezing during API calls
- ✅ Instant feedback on all actions
- ✅ Graceful error handling
- ✅ Consistent cross-device experience
- ✅ Accessible to non-technical users

---

## 9. 💡 INNOVATION IDEAS

### 9.1 Voice Control Integration
```javascript
// Web Speech API
const recognition = new webkitSpeechRecognition();
recognition.onresult = (event) => {
  const command = event.results[0][0].transcript;
  if (command.includes('turn on')) toggleAC();
  if (command.includes('temperature')) {
    // Parse temperature from speech
  }
};
```

### 9.2 PWA (Progressive Web App)
```json
// manifest.json
{
  "name": "Goku Smart Home",
  "short_name": "Goku",
  "start_url": "/",
  "display": "standalone",
  "theme_color": "#000000",
  "icons": [...]
}
```

**Benefits:**
- Install as app on mobile
- Offline mode support
- Push notifications

### 9.3 IR Database Sync
- Integrate with online IR database (e.g., IRDB)
- Auto-detect AC brand via learning
- Cloud backup of learned codes

### 9.4 Energy Monitoring
- Track AC usage time
- Estimate power consumption
- Generate usage reports

---

## 10. 🎯 FINAL RECOMMENDATIONS

### Top 3 Immediate Actions
1. **Implement LED Modal** - Critical missing feature
2. **Add Authentication** - Security vulnerability
3. **WebSocket for Real-Time** - Better UX than polling

### Architecture Evolution
```
Current:           Future:
Polling REST  →    WebSocket + REST
SPIFFS       →    LittleFS (better performance)
Vanilla JS   →    Optional: Vue/React for complex UI
No Auth      →    JWT-based sessions
```

### Tech Debt to Address
- Replace fixed buffers with dynamic allocation
- Migrate from cJSON to jsmn (lighter weight)
- Separate API routing logic from handlers
- Use event bus for cross-component communication

---

## 📌 CONCLUSION

**Overall Assessment:** ⭐⭐⭐⭐ (4/5)

**Strengths:**
- Solid architecture foundation
- Beautiful, responsive UI
- Rich feature set
- Good code organization

**Critical Gaps:**
- Security (no auth)
- LED modal placeholder
- No real-time updates

**Recommendation:** Proceed with phased upgrade plan. Focus on Tier 1 (security + LED) first, then iterate on UX and features.

---

**Prepared by:** Senior Embedded System Architect  
**Review Status:** Ready for Implementation  
**Next Steps:** Create implementation tickets for Phase 1

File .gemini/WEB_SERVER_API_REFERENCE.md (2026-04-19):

# 📚 WEB SERVER API REFERENCE

> **Quick reference guide cho lập trình viên**  
> **Component:** svc_web_server  
> **Endpoint Base:** `http://lamp-ir.local:8080`

---

## 🔌 API ENDPOINTS

### 🌡️ AC Control APIs

#### POST /api/ac/control
Điều khiển máy lạnh

**Request Body:**
```json
{
  "power": 1,           // 0 = off, 1 = on
  "mode": 1,            // 0=Auto, 1=Cool, 2=Heat, 3=Fan, 4=Dry
  "temp": 24,           // 16-30
  "fan": 2,             // 0=Auto, 1=Low, 2=Med, 3=High
  "brand": "Samsung"    // String = custom brand, Number = preset
}
```

**Response:** `200 OK`

---

#### GET /api/ac/state
Lấy trạng thái AC cơ bản

**Response:**
```json
{
  "power": true,
  "mode": 1,
  "temp": 24,
  "fan": 2,
  "brand": 1
}
```

---

#### GET /api/ac/full_state
Lấy trạng thái AC đầy đủ (bao gồm custom brand info)

**Response:**
```json
{
  "brand": 1,
  "is_custom": true,
  "custom_brand_name": "Samsung",
  "state": {
    "power": true,
    "mode": 1,
    "temp": 24,
    "fan": 2,
    "swing_v": 0,
    "swing_h": 0
  }
}
```

---

### 📡 IR Learning APIs

#### POST /api/learn/start
Bắt đầu học tín hiệu IR

**Response:** `200 "Started"`

---

#### POST /api/learn/stop
Dừng học tín hiệu IR

**Response:** `200 "Stopped"`

---

#### GET /api/learn/status
Kiểm tra trạng thái học tín hiệu

**Response:**
```json
{
  "learning": true,
  "captured": 1234
}
```

---

#### POST /api/save?key={key}
Lưu tín hiệu đã học

**Parameters:**
- `key`: Tên tín hiệu (e.g., `Samsung_temp_24`)

**Response:** `200 "Saved"`

---

### 📤 IR Transmission APIs

#### POST /api/send?key={key}
Gửi tín hiệu IR đã lưu

**Parameters:**
- `key`: Tên tín hiệu

**Response:** `200 "Sent"`

---

#### GET /api/ir/list
Lấy danh sách tín hiệu IR đã lưu

**Response:**
```json
["Samsung_on", "Samsung_off", "Samsung_temp_24", ...]
```

---

#### POST /api/ir/delete?key={key}
Xóa tín hiệu IR

**Parameters:**
- `key`: Tên tín hiệu

**Response:** `200 "Deleted"`

---

#### POST /api/ir/rename?old={old}&new={new}
Đổi tên tín hiệu IR

**Parameters:**
- `old`: Tên cũ
- `new`: Tên mới

**Response:** `200 "Renamed"`

---

### 🏷️ Brand Management APIs

#### GET /api/brand/list
Lấy danh sách custom brands

**Response:**
```json
["Samsung", "LG Custom", "My AC"]
```

---

#### POST /api/brand/add?name={name}
Thêm custom brand

**Parameters:**
- `name`: Tên brand (max 31 chars, alphanumeric + - _)

**Response:** `200 "OK"`

**Errors:**
- `400` - Brand already exists
- `500` - Max brands reached (20)

---

#### POST /api/brand/rename?old={old}&new={new}
Đổi tên custom brand

**Parameters:**
- `old`: Tên cũ
- `new`: Tên mới

**Response:** `200 "OK"`

**Errors:**
- `404` - Brand not found

---

#### POST /api/brand/delete?name={name}
Xóa custom brand

**Parameters:**
- `name`: Tên brand

**Response:** `200 "OK"`

**Errors:**
- `404` - Brand not found

---

### 💡 LED Control APIs

#### GET /api/led/config
Lấy cấu hình LED hiện tại

**Optional Query:**
- `effect`: Lấy config của hiệu ứng cụ thể

**Response:**
```json
{
  "speed": 50,
  "brightness": 80,
  "effect": "rainbow",
  "colors": [
    [255, 0, 0],
    [0, 255, 0],
    [0, 0, 255],
    ...
  ]
}
```

---

#### POST /api/led/config
Cấu hình LED

**Query Parameters:**
- `effect`: `static|rainbow|running|breathing|blink|knight_rider|loading|color_wipe|theater_chase|fire|sparkle|random|auto_cycle`
- `brightness`: 0-100
- `speed`: 0-100
- `index`: Color slot index (0-7, or 255 for all)
- `r`, `g`, `b`: RGB values (0-255)

**Example:**
```
POST /api/led/config?effect=rainbow&brightness=80&speed=50
POST /api/led/config?effect=static&index=0&r=255&g=0&b=0
```

**Response:** `200 "Saved"`

---

#### POST /api/led/save_preset
Lưu cấu hình LED hiện tại vào NVS

**Response:** `200 "Saved"`

---

#### GET /api/led/state-config
Lấy màu sắc cho các trạng thái LED

**Response:**
```json
[
  {"id": 0, "name": "WiFi Prov", "r": 0, "g": 0, "b": 255},
  {"id": 1, "name": "WiFi Conn", "r": 0, "g": 255, "b": 0},
  {"id": 2, "name": "OTA", "r": 255, "g": 165, "b": 0},
  ...
]
```

---

#### POST /api/led/state-config
Cấu hình màu sắc trạng thái LED

**Query Parameters:**
- `id`: State ID (0-6)
- `r`, `g`, `b`: RGB values

**Example:**
```
POST /api/led/state-config?id=0&r=255&g=0&b=0
```

**Response:** `200 "Saved"`

---

### 🔄 OTA APIs

#### GET /api/ota/check
Kiểm tra firmware update

**Response:**
```json
{
  "current": "1.0.0",
  "latest": "1.1.0",
  "available": true,
  "time_synced": true
}
```

---

#### POST /api/ota/start
Bắt đầu OTA update

**Response:** `200 "Started"`

---

### 📶 WiFi APIs

#### GET /api/wifi/scan
Quét mạng WiFi

**Response:**
```json
[
  {"ssid": "MyNetwork", "rssi": -45},
  {"ssid": "NeighborWiFi", "rssi": -72},
  ...
]
```

---

#### POST /api/wifi/config?ssid={ssid}&password={password}
Cấu hình WiFi credentials

**Parameters:**
- `ssid`: Tên mạng (max 32 chars)
- `password`: Mật khẩu (max 64 chars)

**Response:** `200 "Saved"`

---

### 🖥️ System APIs

#### GET /api/system/stats
Lấy thống kê hệ thống

**Response:**
```json
{
  "led_enabled": true,
  "uptime": 3600,
  "free_heap": 142336,
  "min_free_heap": 120000,
  "ram": 35,
  "psram_free": 1900000,
  "psram_total": 2000000,
  "psram": 5,
  "cpu": 0,
  "temp": 45.6,
  "rssi": -54,
  "ssid": "MyNetwork",
  "version": "1.0.0"
}
```

---

#### GET /api/system/logs
Lấy system logs

**Response:** Plain text logs

---

#### POST /api/system/logs/clear
Xóa system logs

**Response:** `200 "Cleared"`

---

## 🛠️ CODE EXAMPLES

### JavaScript (Frontend)

#### Send AC Command
```javascript
async function setACTemp(temp) {
  const payload = {
    power: 1,
    mode: 1,  // Cool
    temp: temp,
    fan: 2,   // Medium
  };
  
  try {
    const res = await fetch('/api/ac/control', {
      method: 'POST',
      headers: { 'Content-Type': 'application/json' },
      body: JSON.stringify(payload)
    });
    
    if (res.ok) {
      console.log('AC updated');
    }
  } catch (err) {
    console.error('Failed:', err);
  }
}
```

---

#### Learning Flow
```javascript
// Start learning
async function startLearning() {
  await fetch('/api/learn/start', { method: 'POST' });
  
  // Poll status
  const interval = setInterval(async () => {
    const res = await fetch('/api/learn/status');
    const data = await res.json();
    
    if (data.captured > 0) {
      console.log('Captured:', data.captured);
      
      if (!data.learning) {
        clearInterval(interval);
        // Auto-save
        await fetch('/api/save?key=MyCommand', { method: 'POST' });
      }
    }
  }, 1000);
}
```

---

#### Set LED Color
```javascript
async function setLedColor(r, g, b) {
  await fetch(`/api/led/config?effect=static&index=255&r=${r}&g=${g}&b=${b}`, {
    method: 'POST'
  });
}

// Example: Set red
setLedColor(255, 0, 0);
```

---

### C (Backend)

#### Create New API Handler
```c
static esp_err_t api_my_handler(httpd_req_t *req) {
  // 1. Parse request (if needed)
  char buf[128];
  int ret = httpd_req_recv(req, buf, sizeof(buf) - 1);
  if (ret <= 0) {
    return ESP_FAIL;
  }
  buf[ret] = 0;
  
  // 2. Process (call manager/driver)
  // my_logic_function(buf);
  
  // 3. Return response
  cJSON *root = cJSON_CreateObject();
  cJSON_AddStringToObject(root, "status", "ok");
  
  char *json_str = cJSON_PrintUnformatted(root);
  httpd_resp_set_type(req, "application/json");
  httpd_resp_send(req, json_str, HTTPD_RESP_USE_STRLEN);
  
  cJSON_Delete(root);
  free(json_str);
  return ESP_OK;
}

// Register in svc_web_start()
static const httpd_uri_t my_endpoint = {
  .uri = "/api/my/endpoint",
  .method = HTTP_GET,
  .handler = api_my_handler
};
REG_URI(&my_endpoint);
```

---

#### Broadcast State Change (WebSocket)
```c
// When AC state changes
void on_ac_state_changed(ir_ac_state_t *state) {
  cJSON *root = cJSON_CreateObject();
  cJSON_AddStringToObject(root, "type", "ac_state");
  
  cJSON *state_obj = cJSON_CreateObject();
  cJSON_AddBoolToObject(state_obj, "power", state->power);
  cJSON_AddNumberToObject(state_obj, "temp", state->temp);
  // ... add other fields
  
  cJSON_AddItemToObject(root, "state", state_obj);
  
  char *json_str = cJSON_PrintUnformatted(root);
  ws_broadcast(json_str);  // Send to all connected clients
  
  free(json_str);
  cJSON_Delete(root);
}
```

---

## 🔒 SECURITY NOTES

### Current Status (v1.0)
- ⚠️ **No authentication** - Anyone on network can access
- ⚠️ **No HTTPS** - Traffic unencrypted
- ⚠️ **No rate limiting** - Vulnerable to DoS

### Planned (v2.0)
- ✅ Basic Auth or session-based login
- ✅ Input validation on all endpoints
- ✅ Rate limiting (max 60 req/min per IP)

### Best Practices (for now)
1. Only use on trusted networks (home WiFi)
2. Don't expose port 8080 to internet
3. Use strong WiFi password
4. Keep firmware updated

---

## ⚡ PERFORMANCE TIPS

### Frontend
```javascript
// ❌ Bad: Polling every 100ms
setInterval(fetchState, 100);

// ✅ Good: WebSocket + smart polling
ws.onmessage = (e) => updateUI(e.data);
```

### Backend
```c
// ❌ Bad: Dynamic allocation in hot path
char *buf = malloc(1024);

// ✅ Good: Stack allocation
char buf[1024];
```

### API Usage
```javascript
// ❌ Bad: Individual requests
await fetch('/api/ac/state');
await fetch('/api/led/config');
await fetch('/api/system/stats');

// ✅ Good: Use full_state endpoint
await fetch('/api/ac/full_state');  // Returns everything
```

---

## 🐛 DEBUGGING

### Enable Debug Logs
```c
// In sdkconfig
CONFIG_LOG_DEFAULT_LEVEL_DEBUG=y

// In code
ESP_LOGD(TAG, "Variable: %d", value);
```

### Check HTTP Server Status
```bash
# Monitor logs
idf.py monitor

# Look for:
# [svc_web_server] Starting HTTP Server...
# [svc_web_server] Registered /api/ac/control
```

### Test API from Command Line
```bash
# GET request
curl http://lamp-ir.local:8080/api/system/stats | jq

# POST request
curl -X POST http://lamp-ir.local:8080/api/ac/control \
  -H "Content-Type: application/json" \
  -d '{"power":1, "temp":24}'
```

---

## 📖 ERROR CODES

| HTTP Code | Meaning | Common Cause |
|---|---|---|
| 200 | OK | Success |
| 400 | Bad Request | Invalid JSON, missing params |
| 404 | Not Found | Invalid endpoint or key not found |
| 500 | Internal Error | Server crash, NVS error |

### Example Error Response (Future)
```json
{
  "error": {
    "code": 1002,
    "message": "Temperature out of range",
    "field": "temp",
    "detail": "Must be 16-30"
  }
}
```

---

## 🔗 RELATED COMPONENTS

- **mgr_ac_logic** - AC state management
- **mgr_ir_protocols** - IR encoding/decoding
- **drv_led_strip** - LED control
- **svc_nvs** - Persistent storage
- **svc_wifi** - WiFi management
- **svc_ota** - OTA updates

---

## 📝 CHANGELOG

### v1.0.0 (Current)
- ✅ AC control API
- ✅ IR learning API
- ✅ Custom brand management
- ✅ LED control API (conditional)
- ✅ System stats API
- ✅ OTA check/start

### v2.0.0 (Planned)
- 🔜 Authentication
- 🔜 WebSocket support
- 🔜 Scene management
- 🔜 Multi-language
- 🔜 GZIP compression

---

**Last Updated:** 2026-01-15  
**Maintainer:** Senior Embedded System Architect  
**Support:** Check logs via `/api/system/logs`

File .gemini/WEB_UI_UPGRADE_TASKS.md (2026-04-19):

# 🚀 WEB UI UPGRADE IMPLEMENTATION TASKS

> **Project:** Lamp-ir-device  
> **Component:** svc_web_server  
> **Timeline:** 8 weeks (4 phases)  
> **Status:** Planning Complete ✅

---

## ✅ PHASE 1: Security & Stability (Weeks 1-2)

### Task 1.1: Authentication System
**Priority:** CRITICAL 🔴  
**Estimated Effort:** 8 hours  

**Backend Changes:**
```c
// File: components/svc_web_server/src/svc_web_auth.c (NEW)
typedef struct {
  char username[32];
  char password_hash[65];  // SHA-256
  uint32_t session_token;
  int64_t expires_at;
} web_session_t;

esp_err_t web_auth_check_credentials(const char *user, const char *pass);
web_session_t* web_auth_create_session(const char *user);
bool web_auth_verify_session(httpd_req_t *req);
void web_auth_middleware(httpd_req_t *req);
```

**Frontend Changes:**
```html
<!-- File: www/login.html (NEW) -->
<form id="login-form">
  <input type="text" id="username" placeholder="Username">
  <input type="password" id="password" placeholder="Password">
  <button type="submit">Login</button>
</form>
```

**Checklist:**
- [ ] Create `svc_web_auth.c` and `svc_web_auth.h`
- [ ] Implement SHA-256 password hashing
- [ ] Add session token generation (crypto random)
- [ ] Create login page UI
- [ ] Add middleware to all protected endpoints
- [ ] Store session in NVS (survive reboot)
- [ ] Add logout functionality
- [ ] Test: Login with correct credentials
- [ ] Test: Reject invalid credentials
- [ ] Test: Session expiry after 1 hour

---

### Task 1.2: Input Validation
**Priority:** HIGH 🟠  
**Estimated Effort:** 6 hours  

**Implementation:**
```c
// File: components/svc_web_server/src/svc_web_validation.c (NEW)
typedef struct {
  const char *field;
  json_type_t type;
  int min_value;
  int max_value;
  size_t max_length;
} validation_rule_t;

esp_err_t validate_json_object(cJSON *obj, validation_rule_t *rules, int rule_count);
esp_err_t validate_string_param(const char *str, size_t max_len);
esp_err_t validate_numeric_range(int value, int min, int max);
```

**Validation Rules:**
```c
// AC Control
validation_rule_t ac_rules[] = {
  {"power", JSON_BOOL, 0, 1, 0},
  {"temp", JSON_NUMBER, 16, 30, 0},
  {"mode", JSON_NUMBER, 0, 4, 0},
  {"fan", JSON_NUMBER, 0, 3, 0}
};

// Brand Name
{"name", JSON_STRING, 0, 0, 31}
```

**Checklist:**
- [ ] Create validation framework
- [ ] Add rules for all API endpoints
- [ ] Return 400 with detailed error message
- [ ] Test: Send invalid JSON
- [ ] Test: Send out-of-range values
- [ ] Test: Send oversized strings
- [ ] Test: Send null/missing fields

---

### Task 1.3: Error Response Standardization
**Priority:** MEDIUM 🟡  
**Estimated Effort:** 4 hours  

**Standard Error Format:**
```json
{
  "error": {
    "code": 400,
    "message": "Invalid temperature value",
    "field": "temp",
    "detail": "Temperature must be between 16 and 30"
  }
}
```

**Implementation:**
```c
typedef enum {
  API_ERR_INVALID_JSON = 1000,
  API_ERR_INVALID_PARAM = 1001,
  API_ERR_OUT_OF_RANGE = 1002,
  API_ERR_NOT_FOUND = 1003,
  API_ERR_ALREADY_EXISTS = 1004,
  API_ERR_MAX_LIMIT = 1005
} api_error_code_t;

esp_err_t send_api_error(httpd_req_t *req, int http_code, api_error_code_t err_code, const char *msg);
```

**Checklist:**
- [ ] Define error code enum
- [ ] Create `send_api_error()` helper
- [ ] Replace all `httpd_resp_send_500()` calls
- [ ] Replace all `httpd_resp_send_404()` calls
- [ ] Update frontend to parse error format
- [ ] Test: Frontend displays error message

---

### Task 1.4: LED Modal Implementation
**Priority:** CRITICAL 🔴  
**Estimated Effort:** 10 hours  

**UI Structure:**
```html
<!-- File: www/index.html - Add modal -->
<div id="led-modal" class="modal hidden">
  <div class="modal-content">
    <h2>LED Ring Control</h2>
    
    <!-- Effect Selector -->
    <select id="led-effect"></select>
    
    <!-- Color Palette (8 slots) -->
    <div class="color-palette">
      <input type="color" class="color-slot" data-index="0">
      <!-- ... 7 more ... -->
    </div>
    
    <!-- Brightness Slider -->
    <input type="range" id="led-brightness" min="0" max="100">
    
    <!-- Speed Slider (for effects) -->
    <input type="range" id="led-speed" min="0" max="100">
    
    <!-- Save Button -->
    <button onclick="saveLedConfig()">Save</button>
  </div>
</div>
```

**JavaScript Logic:**
```javascript
async function openLedModal() {
  // Fetch current config
  const res = await fetch('/api/led/config');
  const config = await res.json();
  
  // Populate UI
  DOM.ledEffect.value = config.effect;
  DOM.ledBrightness.value = config.brightness;
  config.colors.forEach((rgb, idx) => {
    setColorSlot(idx, rgbToHex(rgb));
  });
  
  // Show modal
  DOM.ledModal.classList.remove('hidden');
}

async function saveLedConfig() {
  const payload = {
    effect: DOM.ledEffect.value,
    brightness: parseInt(DOM.ledBrightness.value),
    speed: parseInt(DOM.ledSpeed.value),
    colors: getColorPalette()  // Read all 8 slots
  };
  
  await fetch('/api/led/config', {
    method: 'POST',
    body: JSON.stringify(payload)
  });
  
  closeLedModal();
}
```

**Checklist:**
- [ ] Create modal HTML structure
- [ ] Add modal CSS (overlay, animation)
- [ ] Implement `openLedModal()` with API fetch
- [ ] Add color picker for 8 slots
- [ ] Implement effect dropdown (from backend)
- [ ] Add brightness/speed sliders with % display
- [ ] Implement `saveLedConfig()` POST handler
- [ ] Add "State Colors" configuration tab
- [ ] Test: Open modal, change color, save
- [ ] Test: Change effect, verify speed/color relevance
- [ ] Test: Close modal without saving

---

### Task 1.5: Request Logging
**Priority:** LOW 🟢  
**Estimated Effort:** 2 hours  

**Implementation:**
```c
static void log_request(httpd_req_t *req) {
  char client_ip[16];
  httpd_req_get_client_ip(req, client_ip, sizeof(client_ip));
  
  ESP_LOGI(TAG, "[%s] %s %s", client_ip, 
           http_method_str(req->method), req->uri);
}

// In each handler:
esp_err_t api_ac_control_handler(httpd_req_t *req) {
  log_request(req);
  // ...
}
```

**Checklist:**
- [ ] Create logging helper
- [ ] Add to all API handlers
- [ ] Include timestamp, IP, method, URI
- [ ] Test: View logs via `/api/system/logs`

---

## ✅ PHASE 2: UX Improvements (Weeks 3-4)

### Task 2.1: Loading States & Spinners
**Priority:** MEDIUM 🟡  
**Estimated Effort:** 4 hours  

**CSS Components:**
```css
.loader {
  border: 4px solid var(--bg-tertiary);
  border-top: 4px solid var(--accent);
  border-radius: 50%;
  width: 24px;
  height: 24px;
  animation: spin 1s linear infinite;
}

@keyframes spin {
  0% { transform: rotate(0deg); }
  100% { transform: rotate(360deg); }
}
```

**JavaScript Helpers:**
```javascript
function showLoader(elementId) {
  const el = document.getElementById(elementId);
  el.innerHTML = '';
  el.disabled = true;
}

function hideLoader(elementId, originalText) {
  const el = document.getElementById(elementId);
  el.innerHTML = originalText;
  el.disabled = false;
}
```

**Checklist:**
- [ ] Create loader CSS
- [ ] Add loading state to AC toggle button
- [ ] Add loading state to temperature buttons
- [ ] Add loading state to learning button
- [ ] Add loading state to brand add/delete
- [ ] Add global page loader for initial load
- [ ] Test: All buttons show spinner during API call

---

### Task 2.2: Toast Notification System
**Priority:** MEDIUM 🟡  
**Estimated Effort:** 5 hours  

**HTML Structure:**
```html

```

**CSS:**
```css
.toast {
  position: fixed;
  bottom: 100px;
  left: 50%;
  transform: translateX(-50%);
  background: var(--bg-secondary);
  padding: 16px 24px;
  border-radius: 12px;
  box-shadow: 0 10px 30px rgba(0,0,0,0.2);
  animation: slideUp 0.3s ease-out;
}

.toast-success { border-left: 4px solid var(--success); }
.toast-error { border-left: 4px solid var(--danger); }
.toast-info { border-left: 4px solid var(--accent); }

@keyframes slideUp {
  from { opacity: 0; transform: translate(-50%, 20px); }
  to { opacity: 1; transform: translate(-50%, 0); }
}
```

**JavaScript Implementation:**
```javascript
function showToast(message, type = 'info', duration = 3000) {
  const toast = document.createElement('div');
  toast.className = `toast toast-${type}`;
  toast.textContent = message;
  
  const container = document.getElementById('toast-container');
  container.appendChild(toast);
  
  setTimeout(() => {
    toast.style.animation = 'slideDown 0.3s ease-out';
    setTimeout(() => toast.remove(), 300);
  }, duration);
}

// Usage:
showToast('AC turned on', 'success');
showToast('Failed to connect', 'error');
```

**Checklist:**
- [ ] Create toast container
- [ ] Implement toast CSS
- [ ] Create `showToast()` function
- [ ] Add to all API success/error cases
- [ ] Test: Success toast on AC toggle
- [ ] Test: Error toast on network failure
- [ ] Test: Multiple toasts stack correctly

---

### Task 2.3: Form Validation (Frontend)
**Priority:** MEDIUM 🟡  
**Estimated Effort:** 3 hours  

**Validation Functions:**
```javascript
const validators = {
  brandName: (name) => {
    if (!name || name.trim() === '') throw 'Brand name cannot be empty';
    if (name.length > 31) throw 'Brand name too long (max 31 chars)';
    if (!/^[a-zA-Z0-9_-]+$/.test(name)) throw 'Only letters, numbers, - and _ allowed';
  },
  
  temperature: (temp) => {
    if (temp < 16 || temp > 30) throw 'Temperature must be 16-30°C';
  }
};

// Usage:
async function addBrand() {
  const name = prompt('Enter brand name:');
  try {
    validators.brandName(name);
    // Proceed with API call
  } catch (err) {
    showToast(err, 'error');
  }
}
```

**Checklist:**
- [ ] Create validation utilities
- [ ] Add to brand add/rename
- [ ] Add visual feedback (red border on invalid)
- [ ] Test: Empty brand name rejected
- [ ] Test: Special characters rejected
- [ ] Test: Long names truncated

---

### Task 2.4: WebSocket Real-Time Updates
**Priority:** HIGH 🟠  
**Estimated Effort:** 8 hours  

**Backend (ESP-IDF):**
```c
// File: components/svc_web_server/src/svc_web_ws.c (NEW)
static httpd_handle_t ws_server = NULL;
static int ws_client_fds[MAX_WS_CLIENTS] = {0};

static esp_err_t ws_handler(httpd_req_t *req) {
  if (req->method == HTTP_GET) {
    // Upgrade connection
    return ESP_OK;
  }
  
  // Handle incoming WS frame
  httpd_ws_frame_t ws_pkt;
  memset(&ws_pkt, 0, sizeof(httpd_ws_frame_t));
  ws_pkt.type = HTTPD_WS_TYPE_TEXT;
  
  esp_err_t ret = httpd_ws_recv_frame(req, &ws_pkt, 0);
  // Process message
  
  return ret;
}

void ws_broadcast_state_change(const char *json) {
  for (int i = 0; i < MAX_WS_CLIENTS; i++) {
    if (ws_client_fds[i] > 0) {
      httpd_ws_send_frame_async(ws_server, ws_client_fds[i], json);
    }
  }
}
```

**Frontend:**
```javascript
let ws = null;

function connectWebSocket() {
  ws = new WebSocket('ws://' + window.location.hostname + ':8080/ws');
  
  ws.onopen = () => {
    console.log('WebSocket connected');
    document.getElementById('connection-status').style.background = 'var(--success)';
  };
  
  ws.onmessage = (event) => {
    const data = JSON.parse(event.data);
    
    if (data.type === 'ac_state') {
      state.ac = data.state;
      renderAC();
    } else if (data.type === 'learn_status') {
      updateLearnStatus(data.status);
    }
  };
  
  ws.onclose = () => {
    document.getElementById('connection-status').style.background = 'var(--danger)';
    setTimeout(connectWebSocket, 5000);  // Reconnect
  };
}

// Initialize on load
window.onload = () => {
  connectWebSocket();
  // ...
};
```

**Checklist:**
- [ ] Implement WS handler in backend
- [ ] Register WS endpoint (`/ws`)
- [ ] Create broadcast function
- [ ] Trigger broadcast on AC state change
- [ ] Implement frontend WS client
- [ ] Update UI on WS message received
- [ ] Add reconnection logic
- [ ] Remove polling intervals
- [ ] Test: Change AC via RainMaker, Web UI updates
- [ ] Test: Multiple clients receive updates

---

### Task 2.5: Real Dashboard Telemetry
**Priority:** LOW 🟢  
**Estimated Effort:** 6 hours  

**Chart.js Integration:**
```html
<script src="https://cdn.jsdelivr.net/npm/chart.js"></script>
```

**JavaScript Implementation:**
```javascript
let memChart = null;
const chartData = {
  labels: [],
  datasets: [{
    label: 'RAM Usage (%)',
    data: [],
    borderColor: 'rgb(75, 192, 192)',
    tension: 0.1
  }, {
    label: 'PSRAM Usage (%)',
    data: [],
    borderColor: 'rgb(255, 99, 132)',
    tension: 0.1
  }]
};

function initChart() {
  const ctx = document.getElementById('memChart').getContext('2d');
  memChart = new Chart(ctx, {
    type: 'line',
    data: chartData,
    options: {
      responsive: true,
      scales: {
        y: { beginAtZero: true, max: 100 }
      }
    }
  });
}

async function updateDashboard() {
  const res = await fetch('/api/system/stats');
  const data = await res.json();
  
  // Update text values
  document.querySelector('.cpu-value').textContent = data.cpu + '%';
  document.querySelector('.heap-value').textContent = (data.free_heap / 1024).toFixed(1) + ' KB';
  document.querySelector('.temp-value').textContent = data.temp.toFixed(1) + '°C';
  
  // Update chart
  const now = new Date().toLocaleTimeString();
  chartData.labels.push(now);
  chartData.datasets[0].data.push(data.ram);
  chartData.datasets[1].data.push(data.psram);
  
  if (chartData.labels.length > 20) {
    chartData.labels.shift();
    chartData.datasets[0].data.shift();
    chartData.datasets[1].data.shift();
  }
  
  memChart.update();
}

// Update every 5 seconds when dashboard visible
setInterval(() => {
  if (!document.getElementById('view-dashboard').classList.contains('hidden')) {
    updateDashboard();
  }
}, 5000);
```

**Checklist:**
- [ ] Add Chart.js library (CDN or local)
- [ ] Create chart initialization
- [ ] Fetch real stats from `/api/system/stats`
- [ ] Update chart with rolling window (last 20 points)
- [ ] Add CPU, RAM, PSRAM, Temp gauges
- [ ] Test: Dashboard shows real-time data
- [ ] Test: Chart updates every 5s

---

## ✅ PHASE 3: Advanced Features (Weeks 5-6)

### Task 3.1: Scene Management System
**Priority:** MEDIUM 🟡  
**Estimated Effort:** 10 hours  

**Data Structure:**
```c
typedef enum {
  SCENE_ACTION_AC,
  SCENE_ACTION_LED,
  SCENE_ACTION_DELAY
} scene_action_type_t;

typedef struct {
  scene_action_type_t type;
  union {
    ir_ac_state_t ac_state;
    led_config_t led_config;
    uint32_t delay_ms;
  };
} scene_action_t;

typedef struct {
  char name[32];
  scene_action_t actions[MAX_SCENE_ACTIONS];
  int action_count;
} scene_t;

// NVS storage
esp_err_t scene_save(const char *name, scene_t *scene);
esp_err_t scene_load(const char *name, scene_t *scene);
esp_err_t scene_list(char **names, int *count);
esp_err_t scene_run(const char *name);
```

**API Endpoints:**
```c
POST /api/scene/create
{
  "name": "Sleep Mode",
  "actions": [
    {"type": "ac", "power": true, "temp": 26, "mode": 1},
    {"type": "led", "effect": "breathing", "brightness": 10}
  ]
}

GET /api/scene/list
["Sleep Mode", "Movie Mode", "Party Mode"]

POST /api/scene/run?name=Sleep%20Mode
```

**UI:**
```html
<!-- New Tab: Scenes -->
<section id="view-scenes" class="tab-view hidden">
  <h1>Scenes</h1>
  
  <button onclick="createScene()">+ Create Scene</button>
</section>
```

**Checklist:**
- [ ] Define scene data structures
- [ ] Implement scene storage in NVS
- [ ] Create API handlers (create, list, run, delete)
- [ ] Build scene creation UI
- [ ] Add scene execution logic
- [ ] Test: Create "Sleep Mode" scene
- [ ] Test: Run scene, verify AC + LED change
- [ ] Test: List saved scenes
- [ ] Test: Delete scene

---

### Task 3.2: Multi-Language Support (i18n)
**Priority:** LOW 🟢  
**Estimated Effort:** 8 hours  

**Translation Files:**
```javascript
// File: www/lang/en.js
const translations_en = {
  'app.title': 'Goku Smart Home',
  'ac.title': 'Air Conditioner',
  'ac.mode.cool': 'Cool',
  'ac.mode.heat': 'Heat',
  'ac.mode.fan': 'Fan',
  'ac.mode.dry': 'Dry',
  'settings.wifi': 'Wi-Fi Network',
  'settings.firmware': 'Firmware Update',
  // ...
};

// File: www/lang/vi.js
const translations_vi = {
  'app.title': 'Nhà Thông Minh Goku',
  'ac.title': 'Máy Lạnh',
  'ac.mode.cool': 'Làm Lạnh',
  'ac.mode.heat': 'Sưởi Ấm',
  // ...
};
```

**i18n Implementation:**
```javascript
let currentLang = localStorage.getItem('lang') || 'en';
let translations = translations_en;

function setLanguage(lang) {
  currentLang = lang;
  localStorage.setItem('lang', lang);
  translations = window['translations_' + lang];
  updateUI();
}

function t(key) {
  return translations[key] || key;
}

function updateUI() {
  // Update static text
  document.querySelectorAll('[data-i18n]').forEach(el => {
    el.textContent = t(el.dataset.i18n);
  });
  
  // Update placeholders
  document.querySelectorAll('[data-i18n-placeholder]').forEach(el => {
    el.placeholder = t(el.dataset.i18nPlaceholder);
  });
}
```

**HTML Usage:**
```html
<h1 data-i18n="ac.title">Air Conditioner</h1>
<button data-i18n="settings.save">Save</button>
```

**Checklist:**
- [ ] Create English translation file
- [ ] Create Vietnamese translation file
- [ ] Implement i18n framework
- [ ] Add language selector in Settings
- [ ] Mark all UI strings with `data-i18n`
- [ ] Test: Switch language, verify UI updates
- [ ] Test: Language persists on reload

---

### Task 3.3: OTA Progress UI
**Priority:** MEDIUM 🟡  
**Estimated Effort:** 6 hours  

**Backend Enhancement:**
```c
// Add progress tracking
static int ota_progress_percent = 0;

static esp_err_t api_ota_progress_handler(httpd_req_t *req) {
  char resp[64];
  snprintf(resp, sizeof(resp), "{\"progress\":%d, \"status\":\"%s\"}", 
           ota_progress_percent, ota_status_str);
  httpd_resp_set_type(req, "application/json");
  httpd_resp_send(req, resp, HTTPD_RESP_USE_STRLEN);
  return ESP_OK;
}

// In OTA callback (from svc_ota)
void ota_progress_callback(int percent) {
  ota_progress_percent = percent;
  // Broadcast via WebSocket
  ws_broadcast_ota_progress(percent);
}
```

**Frontend:**
```html
<!-- OTA Modal -->
<div id="ota-modal" class="modal hidden">
  <div class="modal-content">
    <h2>Firmware Update</h2>
    <p>Current: <span id="ota-current-ver"></span></p>
    <p>Latest: <span id="ota-latest-ver"></span></p>
    <div class="progress-bar">
      
    </div>
    <p id="ota-status">Ready to update</p>
    <button id="ota-start-btn" onclick="startOTA()">Start Update</button>
  </div>
</div>
```

```javascript
async function startOTA() {
  const btn = document.getElementById('ota-start-btn');
  btn.disabled = true;
  
  await fetch('/api/ota/start', { method: 'POST' });
  
  // Poll progress
  const interval = setInterval(async () => {
    const res = await fetch('/api/ota/progress');
    const data = await res.json();
    
    document.getElementById('ota-progress').style.width = data.progress + '%';
    document.getElementById('ota-status').textContent = data.status;
    
    if (data.progress === 100) {
      clearInterval(interval);
      showToast('Update complete! Rebooting...', 'success');
    }
  }, 1000);
}
```

**Checklist:**
- [ ] Add OTA progress tracking in backend
- [ ] Create progress endpoint
- [ ] Build OTA modal UI
- [ ] Add progress bar animation
- [ ] Implement progress polling
- [ ] Show status messages ("Downloading", "Installing", "Verifying")
- [ ] Test: Start OTA, see progress bar update
- [ ] Test: Handle OTA failure gracefully

---

### Task 3.4: WiFi Manager UI
**Priority:** MEDIUM 🟡  
**Estimated Effort:** 6 hours  

**Enhanced WiFi Scan:**
```javascript
async function scanWiFi() {
  showLoader('wifi-scan-btn');
  const res = await fetch('/api/wifi/scan');
  const networks = await res.json();
  
  const list = document.getElementById('wifi-list');
  list.innerHTML = '';
  
  networks.forEach(net => {
    const item = document.createElement('div');
    item.className = 'list-item';
    item.innerHTML = `
      <span>${net.ssid}</span>
      <div>
        <span class="signal-strength">${getSignalBars(net.rssi)}</span>
        <span class="list-arrow">›</span>
      </div>
    `;
    item.onclick = () => connectToNetwork(net.ssid);
    list.appendChild(item);
  });
  
  hideLoader('wifi-scan-btn');
}

function getSignalBars(rssi) {
  if (rssi > -50) return '▂▃▅▆▇';
  if (rssi > -60) return '▂▃▅▆';
  if (rssi > -70) return '▂▃▅';
  return '▂▃';
}

async function connectToNetwork(ssid) {
  const password = prompt(`Password for ${ssid}:`);
  if (!password) return;
  
  await fetch(`/api/wifi/config?ssid=${encodeURIComponent(ssid)}&password=${encodeURIComponent(password)}`, {
    method: 'POST'
  });
  
  showToast('Connecting to ' + ssid, 'info');
  // Wait for connection status update via WebSocket
}
```

**Checklist:**
- [ ] Add WiFi scan button in Settings
- [ ] Display scanned networks with RSSI bars
- [ ] Add "Connect" flow with password input
- [ ] Show connection status (connecting/connected/failed)
- [ ] Add "Forget Network" option
- [ ] Test: Scan networks, see results
- [ ] Test: Connect to network, verify success
- [ ] Test: Handle incorrect password

---

## ✅ PHASE 4: Optimization (Weeks 7-8)

### Task 4.1: GZIP Compression
**Priority:** MEDIUM 🟡  
**Estimated Effort:** 4 hours  

**Build Script:**
```bash
#!/bin/bash
# File: tools/compress_www.sh

cd components/svc_web_server/www

for file in *.html *.css *.js; do
  if [ -f "$file" ]; then
    gzip -9 -c "$file" > "$file.gz"
    echo "Compressed: $file -> $file.gz"
  fi
done
```

**Backend Support:**
```c
static esp_err_t static_file_handler(httpd_req_t *req) {
  char filepath[280];
  char filepath_gz[284];
  
  // Build paths
  snprintf(filepath, sizeof(filepath), "%s%s", MOUNT_POINT, req->uri);
  snprintf(filepath_gz, sizeof(filepath_gz), "%s.gz", filepath);
  
  FILE *f = fopen(filepath_gz, "r");
  if (f) {
    httpd_resp_set_hdr(req, "Content-Encoding", "gzip");
  } else {
    f = fopen(filepath, "r");
  }
  
  // ... rest of handler
}
```

**Checklist:**
- [ ] Create compression script
- [ ] Integrate into CMake build
- [ ] Update file handler to prefer .gz
- [ ] Add Content-Encoding header
- [ ] Test: Verify browser receives gzipped files
- [ ] Measure: File size reduction (~70% expected)

---

### Task 4.2: Caching Strategy
**Priority:** LOW 🟢  
**Estimated Effort:** 3 hours  

**Implementation:**
```c
static esp_err_t static_file_handler(httpd_req_t *req) {
  // Check If-None-Match header
  char etag_hdr[32];
  if (httpd_req_get_hdr_value_str(req, "If-None-Match", etag_hdr, sizeof(etag_hdr)) == ESP_OK) {
    if (strcmp(etag_hdr, PROJECT_VERSION) == 0) {
      httpd_resp_set_status(req, "304 Not Modified");
      httpd_resp_send(req, NULL, 0);
      return ESP_OK;
    }
  }
  
  // Set caching headers
  httpd_resp_set_hdr(req, "Cache-Control", "public, max-age=86400");
  httpd_resp_set_hdr(req, "ETag", PROJECT_VERSION);
  
  // ... serve file
}
```

**Checklist:**
- [ ] Add ETag header (version-based)
- [ ] Add Cache-Control header (24h)
- [ ] Implement 304 Not Modified response
- [ ] Test: Second page load uses cache
- [ ] Test: Version change invalidates cache

---

### Task 4.3: Bundle Size Optimization
**Priority:** LOW 🟢  
**Estimated Effort:** 4 hours  

**Minification:**
```bash
# Install terser (JS minifier)
npm install -g terser

# Minify app.js
terser www/app.js -c -m -o www/app.min.js

# Minify CSS (csso)
npm install -g csso-cli
csso www/style.css -o www/style.min.css
```

**HTML Minification:**
```bash
npm install -g html-minifier
html-minifier --collapse-whitespace --remove-comments \
  www/index.html -o www/index.min.html
```

**Update References:**
```html
<link rel="stylesheet" href="style.min.css">
<script src="app.min.js"></script>
```

**Checklist:**
- [ ] Set up minification pipeline
- [ ] Minify JS, CSS, HTML
- [ ] Update file references
- [ ] Test: Verify functionality unchanged
- [ ] Measure: Bundle size reduction target < 25KB

---

### Task 4.4: Lazy Loading
**Priority:** LOW 🟢  
**Estimated Effort:** 3 hours  

**Implementation:**
```javascript
const lazyModules = {
  dashboard: {
    loaded: false,
    load: async () => {
      if (!lazyModules.dashboard.loaded) {
        await loadScript('/chart.min.js');
        initChart();
        lazyModules.dashboard.loaded = true;
      }
    }
  },
  scenes: {
    loaded: false,
    load: async () => {
      await loadScript('/scene-manager.js');
      lazyModules.scenes.loaded = true;
    }
  }
};

async function switchTab(targetId) {
  // ... show tab ...
  
  // Lazy load module
  if (lazyModules[targetId]) {
    await lazyModules[targetId].load();
  }
}

function loadScript(src) {
  return new Promise((resolve, reject) => {
    const script = document.createElement('script');
    script.src = src;
    script.onload = resolve;
    script.onerror = reject;
    document.head.appendChild(script);
  });
}
```

**Checklist:**
- [ ] Split Chart.js to separate file
- [ ] Split scene manager to separate file
- [ ] Implement lazy loader
- [ ] Test: Initial load faster
- [ ] Test: Dashboard loads chart on first open

---

### Task 4.5: Performance Testing
**Priority:** MEDIUM 🟡  
**Estimated Effort:** 4 hours  

**Test Suite:**
```bash
#!/bin/bash
# File: tools/perf_test.sh

# Load test
ab -n 1000 -c 10 http://lamp-ir.local:8080/api/system/stats

# Expected:
# - > 100 req/s
# - 0 failed requests
# - Average response < 30ms

# Page load test
curl -w "@curl-format.txt" -o /dev/null -s http://lamp-ir.local:8080/

# Memory test
curl http://lamp-ir.local:8080/api/system/stats | jq '.free_heap'
# Run multiple times, verify no leak
```

**Metrics to Track:**
| Metric | Target | Current | Status |
|---|---|---|---|
| Page Load Time | < 300ms | TBD | ⏳ |
| API Response Time | < 30ms | TBD | ⏳ |
| Memory Peak | < 200KB | TBD | ⏳ |
| Bundle Size | < 25KB | ~35KB | ⏳ |

**Checklist:**
- [ ] Set up Apache Bench
- [ ] Run load tests (1000 req)
- [ ] Measure page load time
- [ ] Check for memory leaks
- [ ] Verify no heap fragmentation
- [ ] Document results

---

## 📊 PROGRESS TRACKING

### Overall Status
- [ ] Phase 1: Security & Stability (0/5 tasks)
- [ ] Phase 2: UX Improvements (0/5 tasks)
- [ ] Phase 3: Advanced Features (0/4 tasks)
- [ ] Phase 4: Optimization (0/5 tasks)

**Total: 0/19 tasks complete**

---

## 🎯 DEFINITION OF DONE

Each task is considered complete when:
- [x] Code implemented and tested locally
- [x] Unit tests written (where applicable)
- [x] Integration test passed
- [x] Code reviewed
- [x] Documentation updated
- [x] Committed to feature branch
- [x] Merged to main after testing

---

## 📝 NOTES

### Dependencies
- ESP-IDF v5.x
- Chart.js (for dashboard)
- No other external libraries

### Risks
- WebSocket implementation may use significant RAM
- SPIFFS partition size may need increase for compressed assets
- Authentication may break existing API clients (e.g., mobile app)

### Mitigation
- Monitor heap usage during WS testing
- Increase SPIFFS partition from current size if needed
- Add authentication toggle in Kconfig for backward compatibility

---

**Last Updated:** 2026-01-15  
**Next Review:** After Phase 1 completion

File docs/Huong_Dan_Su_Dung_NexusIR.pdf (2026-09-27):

HƯỚNG DẪN SỬ DỤNG

# NexusIR Smart Hub

### Trung tâm điều khiển hồng ngoại và ánh sáng thông minh cho Apple HomeKit


Phiên bản tài liệu: 1.1 | Cập nhật: 23/09/2026 | Áp dụng: Firmware v1.4.0+

## 1. Bắt Đầu Trong 5 Phút

Thiết lập nhanh để sẵn sàng điều khiển toàn bộ điều hòa, quạt và dải đèn LED chỉ với 4 thao tác:

1. Cấp nguồn: Cắm cáp Type-C (5V/2A) vào thiết bị. Đèn LED trên hub sẽ sáng nháy vàng chậm.
2. Kết nối Wi-Fi thiết bị: Trên iPhone, vào Cài đặt -> Wi-Fi, chọn mạng NexusIR-Setup-XXXX (hoặc GhostMagic-Setup-XXXX).
3. Cấu hình mạng: Trang xác thực tự hiện ra. Chọn Wi-Fi nhà bạn (băng tần 2.4GHz), nhập mật khẩu rồi bấm Join.
4. Thêm vào Apple Home: Mở ứng dụng Nhà (Home), bấm (+) -> Thêm phụ kiện, chọn NexusIR Bridge và nhập mã: 111-22-333.

Dấu hiệu hoàn tất: Đèn báo trên hub chuyển sang màu xanh dương ổn định. Biểu tượng cầu nối NexusIR xuất hiện trên màn hình chính của ứng dụng Nhà.

NexusIR · Tài liệu kỹ thuật và hướng dẫn vận hành | Trang 1 / 12

## 2. Trước Khi Sử Dụng

Trong hộp sản phẩm | Yêu cầu cần chuẩn bị
- 1× Thiết bị NexusIR Smart Hub • 1× Cáp nguồn USB Type-C (1.0m) • 1× Thẻ mã thiết lập HomeKit Setup Code • 1× Miếng dán định vị 3M chuyên dụng | • Củ sạc USB 5V (tối thiểu 1.5A – 2A) • Mạng Wi-Fi 2.4 GHz (802.11 b/g/n) • iPhone/iPad chạy iOS 15.0 trở lên • Bật sẵn Bluetooth và Định vị trên iPhone

Lưu ý quan trọng: Thiết bị chỉ hoạt động trên băng tần Wi-Fi 2.4 GHz. Nếu bộ định tuyến nhà bạn dùng tính năng gộp băng tần (Mesh/Smart Connect), hãy tạm thời tách riêng SSID 2.4 GHz hoặc đứng gần router trong quá trình thiết lập ban đầu.

## 3. Làm Quen Với Sản Phẩm

NexusIR sở hữu thiết kế hình khối vòm khí động học, phát tín hiệu hồng ngoại 360 độ góc rộng.

Số | Bộ phận phần cứng | Tác dụng & Ý nghĩa vận hành
1 | Vòm phát IR 360° | Mảng LED hồng ngoại 940nm điều khiển điều hòa, quạt, TV từ mọi góc.
2 | Mắt thu hồng ngoại | Cảm biến giải mã 38 kHz dùng để sao chép / học lệnh remote gốc.
3 | Cảm biến AHT20 | Đo nhiệt độ và độ ẩm phòng theo thời gian thực (chuẩn giao tiếp I2C).
4 | Ngõ ra LED & Relay | Hỗ trợ tối đa 5 dải đèn LED RGB WS2812B và 2 ngõ ra relay tải cao.
5 | Nút nhấn đa năng | Bấm 1 lần để đổi hiệu ứng đèn; Giữ 5 giây để xóa Wi-Fi và vào Setup Mode.
6 | Cổng nguồn Type-C | Cấp nguồn DC 5V tiêu chuẩn cho toàn bộ hệ thống.

Trạng thái đèn LED chỉ báo

Màu sắc & Nhịp điệu | Ý nghĩa trạng thái | Hành động yêu cầu
Nhấp nháy vàng chậm | Đang phát Wi-Fi cài đặt (SoftAP) | Mở Wi-Fi điện thoại kết nối vào trạm phát
Nhấp nháy xanh lá nhanh | Đang kết nối vào Wi-Fi nhà | Đợi 5–10 giây thiết bị tự xác thực
Xanh dương sáng tĩnh | Đã kết nối và đồng bộ HomeKit | Sẵn sàng sử dụng bình thường
Nháy đỏ 2 lần | Lỗi mật khẩu Wi-Fi hoặc mất mạng | Nhấn giữ nút 5s để cài đặt lại Wi-Fi

NexusIR Smart Hub · Hướng Dẫn Sử Dụng

NexusIR · Tài liệu kỹ thuật và hướng dẫn vận hành | Trang 2 / 12

## 4. Thiết Lập Lần Đầu

Phần I: Cấu Hình Mạng Wi-Fi Cho Thiết Bị (Wi-Fi Provisioning)

Thiết bị tự động phát mạng Wi-Fi cục bộ để nhận thông tin định tuyến mạng gia đình của bạn.

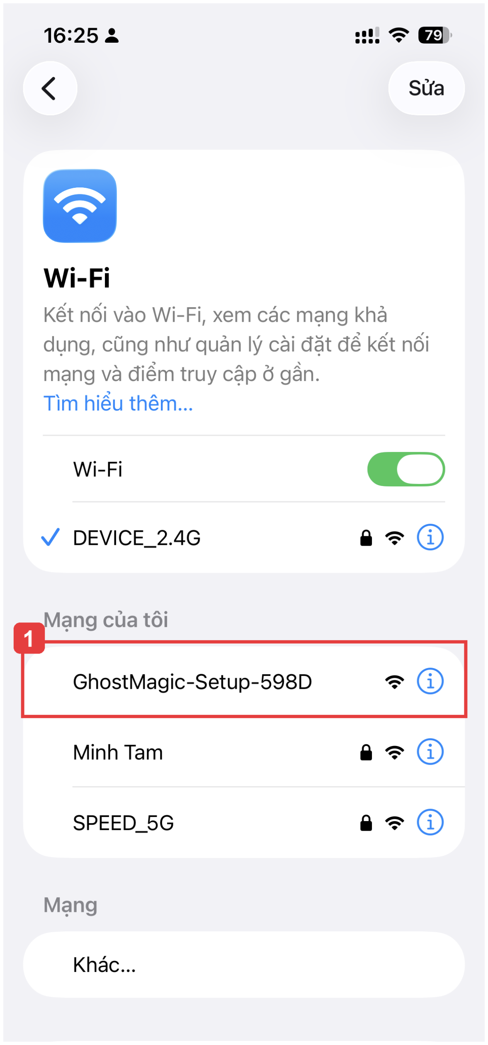
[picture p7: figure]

Bước 1: Tìm và chọn mạng Wi-Fi thiết bị

Cấp nguồn cho NexusIR bằng củ sạc USB. Trên iPhone, mở ứng dụng Cài đặt -> Wi-Fi.

Trong danh sách mạng tìm kiếm được, chọn mạng Wi-Fi do thiết bị phát ra có tên: NexusIR-Setup-XXXX (hoặc GhostMagic-Setup-598D như trong hình).

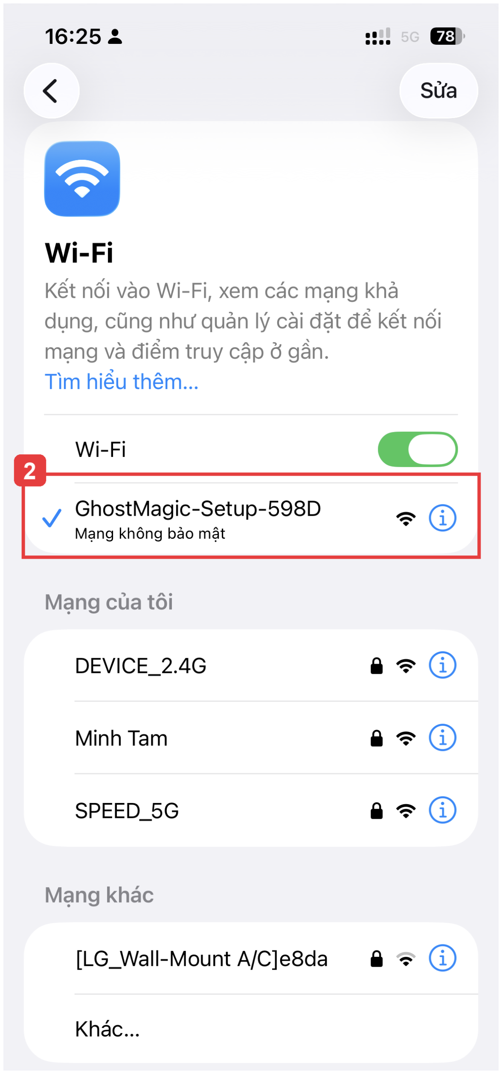
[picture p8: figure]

Bước 2: Xác nhận kết nối thành công

Chờ iPhone kết nối với mạng Wi-Fi của thiết bị cho đến khi xuất hiện dấu tích xanh.

Lưu ý: Dưới tên Wi-Fi hiển thị 'Mạng không bảo mật' hoặc không có internet là hoàn toàn bình thường vì đây chỉ là cổng kết nối cấu hình tạm thời.

NexusIR · Tài liệu kỹ thuật và hướng dẫn vận hành | Trang 3 / 12

## Cấu Hình Wi-Fi (Tiếp Theo)

Nhập thông tin xác thực để kết nối thiết bị vào bộ định tuyến nhà bạn.

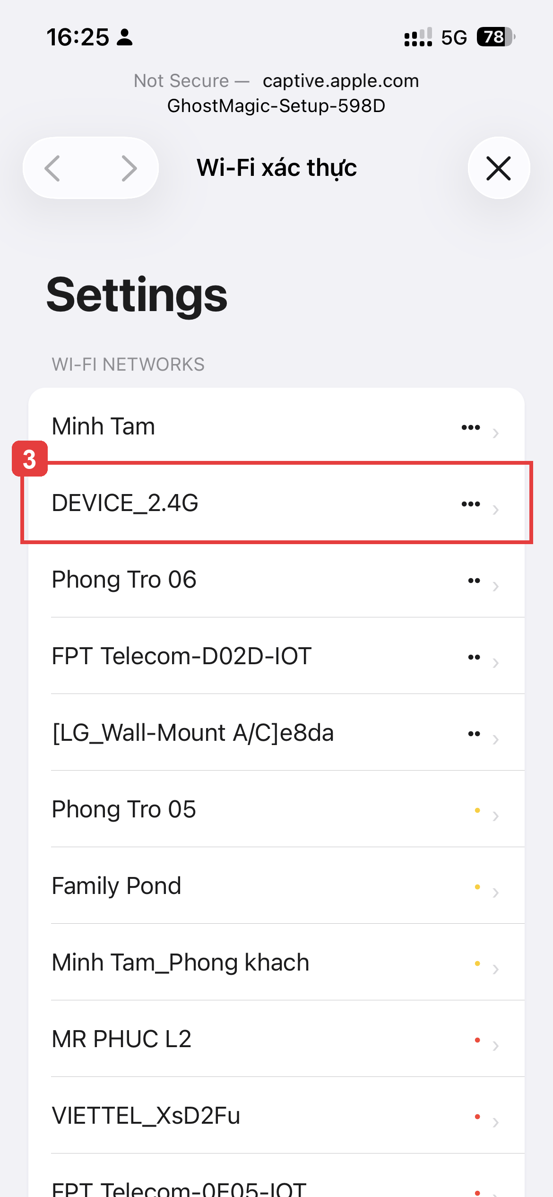
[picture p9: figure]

Bước 3: Chọn mạng Wi-Fi gia đình
Màn hình đăng nhập Captive Portal (Wi-Fi xác thực) sẽ tự động hiển thị trên điện thoại.

(Nếu không tự bật, mở trình duyệt Safari và gõ địa chỉ IP: 192.168.4.1).

Chạm chọn đúng tên Wi-Fi nhà bạn (băng tần 2.4GHz, ví dụ DEVICE_2.4G).

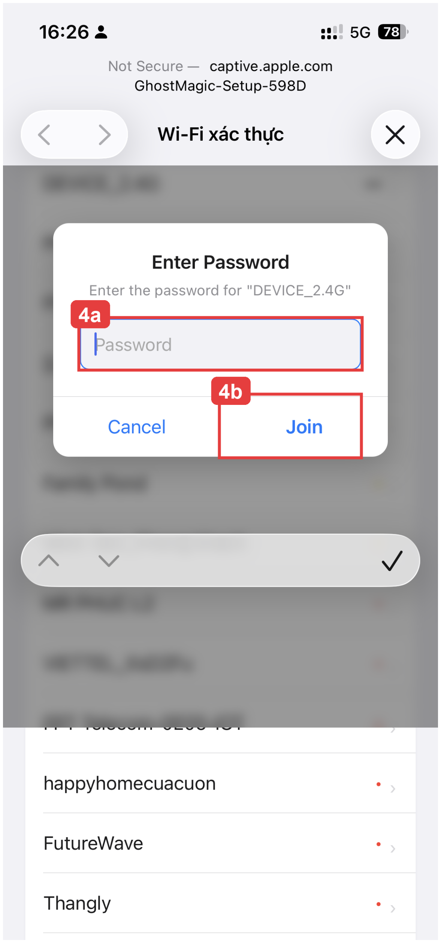
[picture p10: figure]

Bước 4: Nhập mật khẩu Wi-Fi và lưu cấu hình

Hộp thoại bảo mật hiện ra, hãy nhập chính xác mật khẩu Wi-Fi nhà bạn vào ô nhập (4a).

Sau đó chạm vào nút Join (4b) ở góc dưới bên phải để thiết bị ghi thông tin vào bộ nhớ Flash NVS.

NexusIR · Tài liệu kỹ thuật và hướng dẫn vận hành | Trang 4 / 12
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

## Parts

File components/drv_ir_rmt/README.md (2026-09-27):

# Component: IR RMT Driver (drv_ir_rmt)

## 1. Tổng quan (Overview)
Component `drv_ir_rmt` đóng vai trò là Lớp Trừu tượng Phần cứng (HAL) thuần túy cho ngoại vi RMT (Remote Control Peripheral) trên ESP-IDF 5.x. Driver chịu trách nhiệm sở hữu và quản lý toàn bộ vòng đời của kênh truyền TX và kênh nhận RX, đảm bảo hệ thống không bị crash hoặc panics khi phần cứng gặp sự cố trong môi trường vận hành 24/7.

## 2. Phần cứng (Hardware Setup)

| Chức năng | Chân GPIO mặc định | Đặc tả cấu hình |
| :--- | :--- | :--- |
| **IR TX Pin** | `GPIO 4` | Nối tầng lái Transistor / MOSFET phát LED IR. Resolution: 1 MHz. Mem block: 64 symbols. |
| **IR RX Pin** | `GPIO 7` | Nối mắt thu giải điều chế IR (e.g. TSOP38238). Cấu hình nội bộ PULLUP, Invert Level. |

## 3. Các tính năng cốt lõi (Core Features)

1. **Phân tách trách nhiệm hoàn toàn (Separation of Concerns):**
   - Tầng ứng dụng (`mgr_ir_protocols`) không bao giờ trực tiếp thao tác thanh ghi hoặc API cấp thấp của ESP-IDF RMT.
   - Toàn bộ kênh TX, RX, Encoder và ISR callback đều được đóng gói bên trong driver này.

2. **Cấu hình Sóng mang Động (Dynamic Carrier Frequency - IR-17):**
   - Hỗ trợ thay đổi tần số điều chế (10,000 Hz – 60,000 Hz, ví dụ 36kHz, 38kHz, 40kHz, 56kHz) và duty cycle runtime qua hàm `ir_engine_set_carrier()`.
   - Có cơ chế kiểm tra cache: Nếu tần số và duty cycle yêu cầu trùng với cấu hình hiện tại, driver bỏ qua việc re-apply để tránh overhead.

3. **An toàn khi Vận hành 24/7 (Fail-Safe Operation):**
   - **Loại bỏ hoàn toàn `ESP_ERROR_CHECK()`:** Mọi lỗi phần cứng đều được ghi log chi tiết và trả về mã `esp_err_t` thay vì làm reboot chip.
   - **Timeout an toàn 3 giây khi phát:** Thay thế chờ vô tận `-1` bằng `rmt_tx_wait_all_done(..., pdMS_TO_TICKS(3000))` để bảo vệ hệ thống không bị treo vĩnh viễn nếu ngoại vi RMT gặp sự cố.

## 4. API chính (Main HAL APIs)

### TX APIs
- `esp_err_t ir_engine_init(const ir_engine_config_t *config);`
  Khởi tạo RMT TX channel và gán copy encoder.
- `esp_err_t ir_engine_set_carrier(uint32_t freq_hz, float duty_cycle);`
  Cập nhật tần số sóng mang và duty cycle động.
- `esp_err_t ir_engine_send_raw(const void *symbols, size_t count);`
  Truyền chuỗi ký hiệu RMT ra LED phát (chờ truyền xong tối đa 3 giây).

### RX APIs
- `esp_err_t ir_engine_rx_init(const ir_rx_engine_config_t *config);`
  Khởi tạo RMT RX channel, thiết lập chân GPIO pullup và đăng ký ISR callback.
- `esp_err_t ir_engine_rx_start(void *buffer, size_t buffer_size_bytes);`
  Kích hoạt thu xung vào buffer được chỉ định (tự động bật enable channel nếu đang tắt).
- `esp_err_t ir_engine_rx_stop(void);`
  Tạm dừng / ngắt chế độ thu của kênh RX.

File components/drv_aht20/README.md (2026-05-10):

# Component: AHT20 Sensor Driver (drv_aht20)

## 1. Tổng quan (Overview)
Component này cung cấp API để giao tiếp với cảm biến nhiệt độ và độ ẩm AHT20 qua giao tiếp I2C. Nó xử lý việc khởi tạo bus I2C và đọc dữ liệu thô từ cảm biến, sau đó chuyển đổi sang độ C và % độ ẩm.

## 2. Phần cứng (Hardware Setup)
Cần kết nối cảm biến AHT20 vào bus I2C của ESP32:

| Chức năng | Chân GPIO mặc định | Ghi chú |
|---|---|---|
| I2C SDA | `GPIO 6` | Chân dữ liệu I2C |
| I2C SCL | `GPIO 5` | Chân xung clock I2C |

*Lưu ý: Chân GPIO có thể thay đổi trong `menuconfig` -> `Device Configuration` -> `Temperature & Humidity Sensor`.*

## 3. Phụ thuộc (Dependencies)
- `i2c_bus`: Component quản lý bus I2C (thường là managed component của Espressif).
- `esp_err`: Header định nghĩa các mã lỗi của ESP-IDF.

## 4. Cấu hình (Configuration)
Cấu hình qua `idf.py menuconfig`:
- `CONFIG_APP_I2C_SDA`: GPIO cho SDA.
- `CONFIG_APP_I2C_SCL`: GPIO cho SCL.

## 5. Hướng dẫn sử dụng (Usage Example)

```c
#include "drv_aht20.h"

void app_main(void) {
    // 1. Khởi tạo cảm biến
    if (drv_aht20_init() == ESP_OK) {
        float temperature, humidity;
        
        // 2. Đọc dữ liệu định kỳ
        if (aht20_sensor_read(&temperature, &humidity) == ESP_OK) {
            printf("Temp: %.2f C, Hum: %.2f %%\n", temperature, humidity);
        }
    }
}
```

## 6. API chính (Main API)

### `esp_err_t drv_aht20_init(void)`
Khởi tạo bus I2C và kiểm tra sự hiện diện của cảm biến AHT20.
- **Return:** `ESP_OK` nếu khởi tạo thành công và cảm biến phản hồi.

### `esp_err_t aht20_sensor_read(float *temp, float *hum)`
Kích hoạt đo lường và đọc giá trị nhiệt độ, độ ẩm.
- **Param:** `temp` - Con trỏ lưu giá trị nhiệt độ (Celsius).
- **Param:** `hum` - Con trỏ lưu giá trị độ ẩm (%).
- **Return:** `ESP_OK` nếu đọc dữ liệu hợp lệ.

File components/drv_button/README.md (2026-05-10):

# Component: Button Driver (drv_button)

## 1. Tổng quan (Overview)
Component này quản lý các nút nhấn vật lý trên thiết bị. Nó sử dụng thư viện `iot_button` để xử lý chống rung (debounce) và các sự kiện nhấn (click, long press). Trong hệ thống NexusIR, nút nhấn chủ yếu dùng để đánh thức màn hình và thực hiện khôi phục cài đặt gốc (Factory Reset).

## 2. Phần cứng (Hardware Setup)
Kết nối nút nhấn vật lý:

| Chức năng | Chân GPIO mặc định | Ghi chú |
|---|---|---|
| Button | `GPIO 3` | Thường là nút BOOT trên board ESP32 |

*Lưu ý: Mức tích cực (Active Level) mặc định là `0` (Low - nhấn nút nối xuống GND).*

## 3. Phụ thuộc (Dependencies)
- `espressif/button`: Thư viện `iot_button` từ ESP Component Registry.
- `mgr_display`: Để gọi hàm đánh thức màn hình khi nhấn nút.
- `drv_led`: Để hiển thị trạng thái khi Factory Reset.
- `nvs_flash`: Để xóa dữ liệu khi Factory Reset.

## 4. Cấu hình (Configuration)
Cấu hình qua `idf.py menuconfig` -> `Device Configuration`:
- `CONFIG_APP_BUTTON_GPIO`: Chọn chân GPIO cho nút nhấn.
- `CONFIG_APP_BUTTON_ACTIVE_LEVEL`: Mức logic khi nhấn nút (0 hoặc 1).

## 5. Hướng dẫn sử dụng (Usage Example)

```c
#include "drv_button.h"

void app_main(void) {
    // Chỉ cần gọi init, các callback đã được đăng ký bên trong
    drv_button_init();
}
```

## 6. Logic hoạt động (Behavior)
- **Nhấn bất kỳ (Down):** Gọi `mgr_display_activity_tick()` để bật sáng màn hình hoặc giữ màn hình không bị tắt.
- **Nhấn giữ (3 giây):** 
    1. Đổi màu LED sang chế độ `DRV_LED_IR_LEARN` (chỉ báo trực quan).
    2. Xóa toàn bộ phân vùng NVS (`nvs_flash_erase`).
    3. Khởi động lại chip (`esp_restart`).

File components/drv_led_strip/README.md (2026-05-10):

# Component: LED Strip Driver (drv_led_strip)

## 1. Tổng quan (Overview)
Component này quản lý dải LED RGB (thường là WS2812B) và các hiệu ứng ánh sáng. Nó hỗ trợ tối đa 5 bóng LED (hoặc 5 dải LED độc lập tùy cấu hình) và cung cấp một hệ thống trạng thái (System States) để hiển thị phản hồi trực quan cho người dùng (như đang cấu hình WiFi, đang gửi IR, lỗi...).

## 2. Phần cứng (Hardware Setup)
Hỗ trợ tối đa 5 đèn. Chân GPIO mặc định:

| Đèn | Chân GPIO mặc định | Số lượng LED (mặc định) |
|---|---|---|
| Lamp 1 | `GPIO 2` | 8 |
| Lamp 2 | `GPIO 8` | 8 |
| Lamp 3 | `GPIO 9` | 8 |
| Lamp 4 | `GPIO 10` | 8 |
| Lamp 5 | `GPIO 18` | 8 |

## 3. Phụ thuộc (Dependencies)
- `led_strip`: Thư viện driver LED Strip của ESP-IDF (dựa trên RMT hoặc SPI).
- `esp_timer`: Dùng để tạo các hiệu ứng chạy ngầm.

## 4. Cấu hình (Configuration)
Cấu hình chi tiết trong `menuconfig` -> `Device Configuration` -> `LED Lamp X`:
- `APP_LEDX_GPIO`: Chân dữ liệu.
- `APP_LEDX_COUNT`: Số lượng bóng trên dải.
- `APP_LEDX_TYPE`: Kiểu LED (Strip RGB hoặc Single LED PWM).

## 5. Hướng dẫn sử dụng (Usage Example)

```c
#include "drv_led.h"

void app_main(void) {
    // 1. Khởi tạo toàn bộ hệ thống LED
    drv_led_init();

    // 2. Đặt trạng thái hệ thống (ví dụ: đang truyền IR)
    drv_led_set_state(DRV_LED_IR_TX);

    // 3. Điều khiển thủ công từng đèn (Lamp ID 0-4)
    drv_led_set_color(0, 255, 0, 0); // Đèn 1 màu Đỏ
    drv_led_set_effect(0, DRV_LED_EFFECT_BREATHING); // Hiệu ứng nhịp thở
}
```

## 6. API chính (Main API)

### `esp_err_t drv_led_set_state(drv_led_state_t state)`
Cập nhật trạng thái hiển thị của toàn bộ hệ thống. Các trạng thái bao gồm: `STARTUP`, `WIFI_PROV`, `WIFI_CONN`, `IR_TX`, `IR_LEARN`, `IDLE`...

### `esp_err_t drv_led_set_effect(uint8_t lamp_id, drv_led_effect_t effect)`
Thiết lập hiệu ứng cho một đèn cụ thể. Các hiệu ứng: `STATIC`, `RAINBOW`, `BREATHING`, `BLINK`, `FIRE`, `SPARKLE`...

### `esp_err_t drv_led_set_color(uint8_t lamp_id, uint8_t r, uint8_t g, uint8_t b)`
Thiết lập màu sắc RGB cho đèn.

## 7. Trạng thái hệ thống (System States Flow)
Màu sắc mặc định theo trạng thái:
- **WIFI_PROV:** Nháy màu Xanh dương.
- **IR_TX:** Nháy nhanh màu Trắng/Xanh lá.
- **IR_FAIL:** Nháy Đỏ.
- **OTA:** Hiệu ứng Loading màu Vàng.

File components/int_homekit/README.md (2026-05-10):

# Component: HomeKit Integration (int_homekit)

## 1. Tổng quan (Overview)
Component này tích hợp bộ thư viện **Apple HomeKit (HAP)** vào hệ thống. Nó khai báo các Accessory (Thiết bị) và Service (Dịch vụ) tương ứng để người dùng có thể điều khiển NexusIR thông qua ứng dụng Nhà (Home) trên iPhone, iPad, Mac hoặc qua Siri.

## 2. Các thiết bị hỗ trợ (Supported Accessories)
- **Air Conditioner:** Điều khiển nguồn, nhiệt độ, chế độ (Heat/Cool/Auto).
- **Fan:** Điều khiển nguồn và tốc độ quạt.
- **Lightbulb:** Điều khiển tối đa 5 dải LED (Nguồn, Độ sáng, Màu sắc).
- **Switch:** Điều khiển 2 Relay vật lý.
- **Sensors:** Hiển thị nhiệt độ và độ ẩm từ AHT20 hoặc từ remote sensor qua ESP-NOW.

## 3. Phụ thuộc (Dependencies)
- `esp-homekit-sdk`: SDK chính thức từ Espressif cho HomeKit.
- `mgr_ac_logic`, `mgr_fan_logic`, `mgr_led_strip`, `mgr_relay`: Để đồng bộ trạng thái giữa HomeKit và logic thực tế.
- `svc_wifi_prov`: Để xử lý trạng thái WiFi và Provisioning.

## 4. Hướng dẫn sử dụng (Usage Example)

```c
#include "int_homekit.h"

void app_main(void) {
    // 1. Khởi tạo server HomeKit
    int_homekit_init();

    // 2. Khi trạng thái thiết bị thay đổi cục bộ (ví dụ Web UI), cập nhật lên HomeKit
    ir_ac_state_t ac_state;
    // ... get ac_state ...
    int_homekit_update_state(&ac_state);
}
```

## 5. API chính (Main API)

### `esp_err_t int_homekit_init(void)`
Khởi tạo cấu trúc dữ liệu Accessory, các Characteristic (đặc tính) và bắt đầu Accessory Server.

### `void int_homekit_update_state(const ir_ac_state_t *state)`
Đồng bộ trạng thái AC từ hệ thống lên HomeKit UI.

### `bool int_homekit_is_paired(void)`
Kiểm tra xem thiết bị đã được "Pair" (Ghép đôi) với một Home Hub nào chưa.

## 6. Thiết lập (Provisioning)
Khi mới sử dụng, thiết bị sẽ phát ra mã setup HomeKit (mặc định cấu hình trong `app_hap_setup_payload`). Người dùng quét mã QR hoặc nhập mã PIN trên ứng dụng Home để thêm thiết bị.

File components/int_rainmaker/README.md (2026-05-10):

# Component: RainMaker Integration (int_rainmaker)

## 1. Tổng quan (Overview)
Component này cung cấp khả năng kết nối Cloud thông qua giải pháp **ESP RainMaker**. Nó cho phép điều khiển toàn bộ các tính năng của NexusIR (AC, Fan, LED, Relay, Sensors) từ xa qua Internet bằng ứng dụng di động ESP RainMaker (có sẵn trên iOS và Android).

## 2. Tính năng (Features)
- Tự động tạo Device Node trên Cloud.
- Hỗ trợ cập nhật trạng thái thời gian thực (Push notification).
- Tích hợp sẵn cơ chế Provisioning (BLE/SoftAP) thông qua RainMaker app.
- Quản lý danh sách các thương hiệu AC/Fan tùy chỉnh.

## 3. Phụ thuộc (Dependencies)
- `esp_rainmaker`: SDK Cloud của Espressif.
- `mgr_*`: Các manager logic để điều khiển thiết bị cục bộ.
- `svc_wifi_prov`: Để xử lý việc cấu hình WiFi.

## 4. Hướng dẫn sử dụng (Usage Example)

```c
#include "int_rainmaker.h"

void app_main(void) {
    // 1. Khởi tạo kết nối RainMaker
    app_rainmaker_init();

    // 2. Cập nhật trạng thái AC lên Cloud khi có thay đổi
    ir_ac_state_t state;
    // ... update state ...
    app_rainmaker_update_ac(&state);
}
```

## 5. API chính (Main API)

### `esp_err_t app_rainmaker_init(void)`
Khởi tạo RainMaker node, khai báo các thiết bị (Devices) và tham số (Params). Bắt đầu tiến trình kết nối MQTT đến server Cloud.

### `void app_rainmaker_update_ac(const ir_ac_state_t *state)`
Gửi toàn bộ trạng thái hiện tại của điều hòa lên Cloud.

### `void app_rainmaker_update_custom_brands(char **brands, size_t count)`
Cập nhật danh sách các bộ mã lệnh IR đã học được để hiển thị trên menu chọn của ứng dụng di động.

## 6. Luồng dữ liệu (Data Flow)
1. **Cloud to Device:** Người dùng thao tác trên App -> RainMaker Cloud -> MQTT -> ESP32 Callback -> Gọi hàm `mgr_*_set_state` -> Phát lệnh IR.
2. **Device to Cloud:** Thay đổi cục bộ (nút bấm, Web UI) -> Gọi hàm `app_rainmaker_update_*` -> MQTT -> Cloud -> Cập nhật UI trên App.

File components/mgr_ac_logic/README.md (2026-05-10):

# Component: AC Logic Manager (mgr_ac_logic)

## 1. Tổng quan (Overview)
Component này quản lý logic trạng thái của Điều hòa (AC). Nó lưu giữ các thông tin như: nguồn (Power), nhiệt độ (Temperature), chế độ (Mode), tốc độ quạt (Fan speed) và hướng gió (Swing). Nó đóng vai trò trung gian giữa tầng dịch vụ (HomeKit/RainMaker) và tầng driver hồng ngoại (IR).

## 2. Phần cứng (Hardware Setup)
Component này không trực tiếp điều khiển phần cứng mà phụ thuộc vào `drv_ir_rmt` để phát tín hiệu. Tuy nhiên, logic của nó sẽ quyết định mã lệnh IR nào được phát ra.

## 3. Phụ thuộc (Dependencies)
- `drv_ir_rmt`: Để phát tín hiệu IR.
- `mgr_ir_protocols`: Để lấy dữ liệu mã lệnh từ Matrix/NVS.
- `ir_types.h`: Định nghĩa các kiểu dữ liệu `ir_ac_state_t`.

## 4. Cấu hình (Configuration)
Chủ yếu cấu hình qua `menuconfig` -> `Device Configuration` -> `AC (Air Conditioner)`:
- `APP_ESPNOW_AC_MODE`: Chế độ hoạt động (Master/Slave/Standalone).

## 5. Hướng dẫn sử dụng (Usage Example)

```c
#include "mgr_ac_logic.h"

void app_main(void) {
    // 1. Khởi tạo (load trạng thái cũ từ NVS)
    mgr_ac_init();

    // 2. Thay đổi trạng thái
    ir_ac_state_t state;
    mgr_ac_get_state(&state);
    state.power = true;
    state.temp = 24;
    state.mode = IR_AC_MODE_COOL;
    mgr_ac_set_state(&state);

    // 3. Phát lệnh IR thực tế
    mgr_ac_send();
}
```

## 6. API chính (Main API)

### `void mgr_ac_init(void)`
Khởi tạo module AC, khôi phục trạng thái cuối cùng và cấu hình thương hiệu (brand) từ bộ nhớ NVS.

### `void mgr_ac_set_state(const ir_ac_state_t *state)`
Cập nhật trạng thái AC trong bộ nhớ. Hàm này chưa phát lệnh IR.

### `esp_err_t mgr_ac_send(void)`
Thực hiện phát lệnh IR dựa trên trạng thái và thương hiệu hiện tại. Nó sẽ tự động tìm kiếm mã lệnh tương ứng trong hệ thống Matrix.

### `void mgr_ac_set_bridge_cb(mgr_ac_bridge_cb_t cb)`
Đăng ký hàm callback để đồng bộ trạng thái sang các service khác (như gửi gói tin ESP-NOW khi trạng thái thay đổi).

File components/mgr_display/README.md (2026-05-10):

# Component: Display Manager (mgr_display)

## 1. Tổng quan (Overview)
Component này quản lý màn hình hiển thị (LCD) và giao diện người dùng (UI) dựa trên thư viện **LVGL**. Nó chịu trách nhiệm hiển thị các thông số cảm biến, thời gian, thời tiết và các thông báo hệ thống. Nó cũng quản lý việc tiết kiệm điện bằng cách tự động làm mờ hoặc tắt màn hình sau một khoảng thời gian không hoạt động.

## 2. Phần cứng (Hardware Setup)
Phụ thuộc vào loại board sử dụng (ESP32-S3/C3 với màn hình ST7789 hoặc tương đương). Các chân giao tiếp (SPI/I2C/Parallel) thường được cấu hình trong `menuconfig` của driver màn hình.

## 3. Phụ thuộc (Dependencies)
- `lvgl`: Thư viện đồ họa.
- `esp_lcd`: Driver LCD của ESP-IDF.
- `drv_button`: Để đánh thức màn hình khi nhấn nút.
- `svc_weather`: Để lấy dữ liệu hiển thị thời tiết.

## 4. Cấu hình (Configuration)
Cấu hình trong `menuconfig`:
- `CONFIG_APP_LCD_ENABLE`: Bật/Tắt hỗ trợ màn hình.
- Các thông số Timeout cho việc Dim/Sleep màn hình.

## 5. Hướng dẫn sử dụng (Usage Example)

```c
#include "mgr_display.h"

void app_main(void) {
    // 1. Khởi tạo LCD và LVGL
    mgr_display_init();

    // 2. Cập nhật dữ liệu lên UI (An toàn để gọi từ bất kỳ task nào)
    mgr_display_update_ui_sensor_safe(28.5, 65.0);
    mgr_display_update_ui_time_safe();

    // 3. Thông báo cho display biết có hoạt động (Reset timeout tắt màn hình)
    mgr_display_activity_tick();
}
```

## 6. API chính (Main API)

### `esp_err_t mgr_display_init(void)`
Khởi tạo phần cứng hiển thị, đăng ký buffer cho LVGL và bắt đầu Task quản lý UI.

### `void mgr_display_update_ui_sensor_safe(float temp, float hum)`
Cập nhật nhiệt độ và độ ẩm lên màn hình chính một cách an toàn (sử dụng mutex nếu cần).

### `void mgr_display_activity_tick(void)`
Đánh dấu hệ thống vừa có hoạt động (như nhấn nút, nhận lệnh). Hàm này sẽ bật sáng màn hình nếu đang tối và reset bộ đếm thời gian chờ.

### `void mgr_display_show_ui_notification_safe(const char *device_name, const char *status)`
Hiển thị một thông báo popup ngắn gọn trên màn hình (ví dụ: "AC Turned ON").

## 7. Cơ chế tiết kiệm điện (Power Management)
- Sau 30s không hoạt động: Màn hình giảm độ sáng (Dim).
- Sau 60s không hoạt động: Màn hình tắt hẳn (Sleep/Off).
- Nhấn nút hoặc có sự kiện mới: Màn hình sáng trở lại (Wake).

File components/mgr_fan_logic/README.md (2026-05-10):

# Component: Fan Logic Manager (mgr_fan_logic)

## 1. Tổng quan (Overview)
Component này quản lý trạng thái và logic điều khiển Quạt (Fan). Nó xử lý các thuộc tính như: Nguồn (Power), Tốc độ (Speed - discrete 1, 2, 3) và Đảo gió (Swing). Tương tự AC Manager, nó là cầu nối giữa các service điều khiển từ xa và việc phát lệnh IR.

## 2. Phần cứng (Hardware Setup)
Phụ thuộc vào `drv_ir_rmt` để phát tín hiệu hồng ngoại điều khiển quạt vật lý.

## 3. Phụ thuộc (Dependencies)
- `drv_ir_rmt`: Driver phát IR.
- `mgr_ir_protocols`: Hệ thống quản lý mã lệnh (Matrix).
- `ir_types.h`: Định nghĩa struct `ir_fan_state_t`.

## 4. Hướng dẫn sử dụng (Usage Example)

```c
#include "mgr_fan_logic.h"

void app_main(void) {
    // 1. Khởi tạo
    mgr_fan_init();

    // 2. Thiết lập trạng thái
    ir_fan_state_t fan_state = {
        .power = true,
        .speed = 2, // Medium
        .swing = false
    };
    mgr_fan_set_state(&fan_state);

    // 3. Thực thi gửi lệnh IR
    mgr_fan_send();
}
```

## 5. API chính (Main API)

### `void mgr_fan_init(void)`
Khởi tạo và khôi phục trạng thái quạt từ NVS.

### `void mgr_fan_set_state(const ir_fan_state_t *state)`
Cập nhật trạng thái quạt vào bộ nhớ quản lý.

### `esp_err_t mgr_fan_send(void)`
Dựa trên trạng thái hiện tại, tìm mã IR tương ứng trong Matrix và phát ra LED hồng ngoại.

### `void mgr_fan_set_custom_brand(const char *name)`
Thiết lập tên bộ mã lệnh tùy chỉnh cho quạt (dùng khi quạt được "học" lệnh thủ công).

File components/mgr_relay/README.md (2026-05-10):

# Component: Relay Manager (mgr_relay)

## 1. Tổng quan (Overview)
Component này quản lý 2 rơ-le (Relay) và 2 nút nhấn cảm ứng (Touch Button) tương ứng. Nó cho phép điều khiển rơ-le qua phần mềm hoặc trực tiếp bằng nút nhấn vật lý trên thiết bị, đồng thời hỗ trợ cơ chế đồng bộ trạng thái (Bridge) ra bên ngoài.

## 2. Phần cứng (Hardware Setup)
Mặc định chân GPIO (có thể đổi trong `menuconfig`):

| Chức năng | Chân GPIO mặc định | Ghi chú |
|---|---|---|
| Relay 1 | `GPIO 12` | Đầu ra điều khiển Relay 1 |
| Relay 2 | `GPIO 13` | Đầu ra điều khiển Relay 2 |
| Touch 1 | `GPIO 14` | Đầu vào nút nhấn cảm ứng 1 |
| Touch 2 | `GPIO 15` | Đầu vào nút nhấn cảm ứng 2 |

## 3. Phụ thuộc (Dependencies)
- `driver/gpio.h`: Driver GPIO cơ bản của ESP-IDF.
- `esp_timer`: Để xử lý chống rung hoặc các tác vụ trễ.

## 4. Hướng dẫn sử dụng (Usage Example)

```c
#include "mgr_relay.h"

void app_main(void) {
    // 1. Khởi tạo GPIO cho relay và nút nhấn
    mgr_relay_init();

    // 2. Điều khiển Relay 1 Bật
    mgr_relay_set_state(0, true, true);

    // 3. Đọc trạng thái Relay 2
    bool is_on = mgr_relay_get_state(1);
}
```

## 5. API chính (Main API)

### `esp_err_t mgr_relay_init(void)`
Cấu hình các chân GPIO làm Output (cho Relay) và Input (cho Touch Buttons). Khởi tạo trạng thái mặc định (thường là OFF).

### `void mgr_relay_set_state(int relay_idx, bool state, bool report_to_homekit)`
- `relay_idx`: 0 hoặc 1.
- `state`: `true` (ON) hoặc `false` (OFF).
- `report_to_homekit`: Nếu true, sẽ kích hoạt callback để cập nhật lên ứng dụng Nhà (Apple Home) hoặc Cloud.

### `void mgr_relay_set_bridge_cb(mgr_relay_bridge_cb_t cb)`
Đăng ký callback. Khi người dùng nhấn nút vật lý làm thay đổi trạng thái rơ-le, callback này sẽ được gọi để báo về `main` hoặc các tích hợp khác.

## 6. Logic hoạt động (Flow)
- Khi nút `Touch 1` được nhấn: Relay 1 sẽ đảo trạng thái (Toggle).
- Khi nút `Touch 2` được nhấn: Relay 2 sẽ đảo trạng thái (Toggle).
- Trạng thái được lưu vào NVS (nếu có cấu hình) để khôi phục sau khi mất điện.

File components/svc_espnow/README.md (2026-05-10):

# Component: ESP-NOW Service (svc_espnow)

## 1. Tổng quan (Overview)
Component này quản lý việc truyền nhận dữ liệu không dây giữa các thiết bị NexusIR thông qua giao thức **ESP-NOW**. Đây là giải pháp kết nối năng lượng thấp, độ trễ cực thấp, không phụ thuộc vào bộ định tuyến WiFi (Router), cho phép các thiết bị "nói chuyện" trực tiếp với nhau.

## 2. Các loại dữ liệu hỗ trợ (Message Types)
- **AC State:** Đồng bộ trạng thái điều hòa giữa Master và Slave.
- **Fan State:** Đồng bộ trạng thái quạt.
- **LED Control:** Điều khiển dải LED từ xa.
- **Sensor Data:** Gửi dữ liệu nhiệt độ/độ ẩm từ cảm biến pin về hub trung tâm.
- **Relay Control:** Bật/Tắt relay từ xa.

## 3. Phụ thuộc (Dependencies)
- `esp_now`: Driver ESP-NOW chính thức của ESP-IDF.
- `ir_types.h`: Định nghĩa cấu trúc dữ liệu AC/Fan.

## 4. Hướng dẫn sử dụng (Usage Example)

### Gửi dữ liệu (Bridge Master)
```c
#include "svc_espnow.h"

void sync_ac() {
    ir_ac_state_t state = { ... };
    // Gửi trạng thái AC tới tất cả các Slave đã add peer
    svc_espnow_bridge_ac_send(&state, AC_BRAND_CUSTOM, "MyAC");
}
```

### Nhận dữ liệu (Slave Side)
```c
void on_ac_received(const ir_ac_state_t *state, ac_brand_t brand, const char *name) {
    // Thực hiện phát lệnh IR tương ứng
    mgr_ac_set_state(state);
    mgr_ac_send();
}

void app_main() {
    svc_espnow_init();
    svc_espnow_register_ac_handler(on_ac_received);
}
```

## 5. API chính (Main API)

### `esp_err_t svc_espnow_init(void)`
Khởi tạo ngăn xếp ESP-NOW, đăng ký callback nhận dữ liệu mặc định.

### `esp_err_t svc_espnow_add_peer(const uint8_t *mac)`
Thêm địa chỉ MAC của thiết bị đích vào danh sách liên kết.

### `esp_err_t svc_espnow_bridge_ac_send(...)`
Đóng gói trạng thái AC vào frame ESP-NOW và gửi đi. Tương tự cho các hàm `_led_send`, `_fan_send`, `_temp_send`, `_relay_send`.

## 6. Cơ chế hoạt động (Logic)
NexusIR sử dụng ESP-NOW để mở rộng hệ sinh thái. Một thiết bị có thể cấu hình là **Master** (nhận lệnh từ HomeKit/Web và phát đi) hoặc **Slave** (nhận lệnh từ ESP-NOW và thực thi phần cứng tại chỗ).

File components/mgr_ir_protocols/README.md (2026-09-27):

# Component: IR Protocol Manager & Core (mgr_ir_protocols)

## 1. Tổng quan Kiến trúc (Architecture Overview)

Component `mgr_ir_protocols` là lõi xử lý hồng ngoại toàn diện thế hệ mới (IR Core V3) của NexusIR trên nền tảng ESP32-C3 (ESP-IDF v5.5.4). Hệ thống được thiết kế theo kiến trúc hướng sự kiện (Event-Driven), phân lớp chặt chẽ và an toàn 24/7:

```
+-----------------------------------------------------------------------------------+
|               Tầng Ứng dụng & Dịch vụ (Web, HomeKit, RainMaker, ESP-NOW)          |
+-----------------------------------------------------------------------------------+
                                         |
                                         v
+-----------------------------------------------------------------------------------+
|     mgr_ir_protocols: Session State Machine, Worker Task, Normalization & CRC     |
+-----------------------------------------------------------------------------------+
       | (HAL APIs)                                       | (Storage APIs)
       v                                                  v
+-----------------------------+           +-----------------------------------------+
|  drv_ir_rmt (Hardware HAL)  |           |        svc_nvs (NVS Namespace: ir_data) |
|  - RMT TX Channel & Carrier |           |  - V1 Packed Header (20B) + CRC32       |
|  - RMT RX Channel & ISR CB  |           |  - Dual Migration Engine (Safe/Atomic)  |
+-----------------------------+           +-----------------------------------------+
```

---

## 2. Phần cứng & Chân kết nối (Hardware Pinout & HAL)

Hệ thống phân tách triệt để giữa tầng logic (`mgr_ir_protocols`) và tầng điều khiển phần cứng (`drv_ir_rmt`):
- **TX Pin:** GPIO 4 (Nối tầng lái Transistor / MOSFET phát hồng ngoại).
- **RX Pin:** GPIO 7 (Nối mắt thu giải điều chế IR Demodulator 38kHz tích hợp mạch lọc nhiễu quang).
- **RMT Clock Resolution:** 1,000,000 Hz (độ phân giải 1 microsecond/tick).
- **RMT Symbols Memory:** 64 symbols memory block trên mỗi kênh.
- **Tính tương thích chip:** Nhận biết cấu hình DMA trên ESP32-S3 và tối ưu không DMA trên ESP32-C3.

---

## 3. Định dạng Bản ghi V1 & Kiểm tra Toàn vẹn CRC32 (Wire Format V1)

Dữ liệu IR được lưu trữ bền vững trong NVS dưới định dạng nhị phân đóng gói chặt chẽ `#pragma pack(push, 1)`, header cố định đúng 20 bytes:

```
+-----------------------------------------------------------------------+
| Magic (4B)  | Ver (1B) | Flags (1B) | Carrier (2B) | Duty (1B) | Rep (1B) |
| 0x5249584E  |   0x01   | Bitmask    |  38000 Hz    |    33%    |  0 or 1  |
+-----------------------------------------------------------------------+
| Gap (2B)    | DurCount (2B) |       CRC32 (4B, Little-Endian)         |
| 40 ms       | N halfwords   | esp_rom_crc32_le over raw pulse payload |
+-----------------------------------------------------------------------+
| Payload: uint16_t durations[DurCount]                                |
| [Mark 0, Space 0, Mark 1, Space 1, ... Mark N-1]                      |
+-----------------------------------------------------------------------+
```

### Chi tiết các trường:
- **Magic:** `0x5249584E` (`"NXIR"` - NexusIR).
- **Version:** `1` (IR_RECORD_VERSION_V1).
- **Flags:**
  - `IR_FLAG_TRUNCATED` (0x01): Báo hiệu tín hiệu chạm ngưỡng đệm tối đa (buffer full).
  - `IR_FLAG_CARRIER_CUSTOM` (0x02): Tần số carrier khác mặc định.
  - `IR_FLAG_FAN_REPEAT` (0x04): Thiết bị yêu cầu phát lặp (ví dụ Quạt).
- **Carrier Freq:** Tần số sóng mang (10,000 - 60,000 Hz, mặc định 38000 Hz).
- **Duty Cycle:** Độ rộng xung sóng mang (mặc định 33%).
- **Repeat Count:** Số lần lặp lại sau lần phát đầu (0 = phát 1 lần, 1 = phát 2 lần).
- **Repeat Gap:** Thời gian nghỉ giữa các lần phát lặp (mặc định 40 ms).
- **Duration Count:** Số phần tử `uint16_t` trong payload.
- **CRC32:** Mã checksum IEEE 802.3 tính bằng `esp_rom_crc32_le()` phần cứng trên toàn bộ payload.

---

## 4. Ngân sách Lưu trữ NVS & Bảng Dung lượng (IR-12 Storage Budget)

Hệ thống phân vùng Flash của NexusIR dành riêng 32 KB cho `nvs`:
- **Tổng kích thước phân vùng NVS:** 0x8000 (32,768 bytes = 8 Flash Pages).
- **NVS Overhead:** Mỗi page tiêu tốn 32 bytes header + 128 bytes bitmap. 1 page dành cho Garbage Collection.
- **Dung lượng khả dụng thực tế:** ~27.5 KB.

| Loại lệnh IR | Số xung trung bình | Kích thước Payload | Tổng kích thước V1 (Header + Payload) | Số Entry NVS chiếm dụng | Dung lượng ước tính trong NVS |
| :--- | :--- | :--- | :--- | :--- | :--- |
| **TV / Quạt (NEC/RC5)** | 32 - 68 xung | 64 - 136 bytes | **84 - 156 bytes** | ~3 - 5 entries | **180 - 220 phím** |
| **Điều hòa (AC Matrix)** | 100 - 240 xung | 200 - 480 bytes | **220 - 500 bytes** | ~7 - 16 entries | **35 - 45 phím AC** |

### Đánh giá & Quyết định Kiến trúc:
- Một profile AC hoàn chỉnh gồm 16 trạng thái (Off, 16°C – 30°C) chiếm khoảng **5.6 KB**.
- Kết hợp với 20 phím TV/Quạt (~2.5 KB), tổng dung lượng chỉ chiếm **~8.1 KB / 27.5 KB (~30% NVS)**.
- **Kết luận:** NVS hoàn toàn đáp ứng xuất sắc nhu cầu lưu trữ tốc độ cao, truy xuất nguyên tử (atomic write) mà không cần phụ thuộc LittleFS/SPIFFS.
- **Cơ chế phòng vệ:** Khi NVS báo `ESP_ERR_NVS_NOT_ENOUGH_SPACE`, hệ thống từ chối lưu lệnh mới và trả về HTTP 507, đảm bảo toàn vẹn các lệnh cũ đã lưu.

---

## 5. Kiến trúc Hướng sự kiện & Quản lý Phiên (Event-Driven State Machine)

- **ISR Siêu tinh gọn (Ultra-thin ISR):** RMT RX ISR chỉ đóng gói `ir_event_t` và đẩy vào FreeRTOS Queue `s_ir_evt_queue` qua `xQueueSendFromISR` (< 1.5 µs).
- **Worker Task Riêng biệt (`mgr_ir_worker_task`):** Chạy ở Priority 5, Stack 4096 bytes. Thực hiện re-arming, lọc nhiễu (< 20 symbols), điều khiển LED phản hồi và ngắt thu khi có tín hiệu hợp lệ.
- **Session ID:** Mỗi lần kích hoạt học lệnh, `s_current_session_id` tự động tăng đơn điệu. Mọi sự kiện trễ (stale events) từ phiên cũ bị loại bỏ ngay lập tức.
- **Hardware Watchdog Timer:** Tự động hủy học sau 15 giây (`DEFAULT_LEARN_TIMEOUT_MS`) nếu không có remote bấm, chuyển trạng thái sang `IR_STATE_TIMEOUT` và giải phóng RMT RX.

---

## 6. Cơ chế Di trú An toàn Đa Tầng (Safe Migration Engine)

Tương thích ngược tuyệt đối với toàn bộ dữ liệu NVS cũ của người dùng:
1. **On-Access Migration:** Khi người dùng bấm phát bất kỳ phím nào qua Web/HomeKit/RainMaker, hàm `mgr_ir_send_key()` kiểm tra định dạng. Nếu phát hiện lệnh cũ (Legacy 0xAA RAW hoặc Legacy Matrix array), nó tự động nâng cấp sang V1 kèm CRC32 và lưu lại vào NVS.
2. **Background Batch Migration:** Lúc khởi động, `mgr_ir_worker_task` quét toàn bộ namespace `ir_data` bằng `nvs_entry_find()`, xác thực CRC32 các key V1 và tự động chuyển đổi các key legacy.
3. **An toàn khi mất điện (Power-loss safe):** Hệ thống chỉ ghi đè bản ghi mới khi chuỗi xung V1 đã serialize và validate thành công. Không bao giờ xóa key cũ trước khi key mới sẵn sàng.

---

## 7. Bộ API Dịch vụ & REST Endpoints (Unified APIs)

### C API:
- `mgr_ir_init()`: Khởi tạo IR Core, HAL và Worker Task.
- `mgr_ir_start_learn()` / `mgr_ir_start_learn_with_timeout(timeout_ms, out_session_id)`: Bắt đầu học lệnh.
- `mgr_ir_stop_learn()` / `mgr_ir_cancel_learn()`: Hủy phiên học.
- `mgr_ir_get_session_info(out_info)`: Lấy thông tin trạng thái, session ID, số xung và cờ truncated.
- `mgr_ir_send_key(key)`: Phát phím lưu trong NVS (tự động cấu hình carrier và repeat).
- `mgr_ir_send_from_matrix(dev_id, index)`: Phát lệnh AC matrix từ NVS.
- `mgr_ir_save_learned_result(key)`: Lưu xung vừa học dưới dạng V1 có CRC32.
- `mgr_ir_export_key_json(key, out_json)`: Xuất key ra chuỗi JSON.
- `mgr_ir_import_key_json(key, json_str)`: Nhập và validate chuỗi JSON rồi lưu vào NVS.
- `mgr_ir_migrate_all(migrated, skipped, errors)`: Quét và nâng cấp toàn bộ phân vùng NVS.

### HTTP REST APIs:
- `GET /api/learn/status`: Trả về trạng thái học lệnh (`status`, `session_id`, `captured`, `truncated`).
- `POST /api/send?key=KEY`: Phát lệnh IR. Trả về:
  - `200 OK`: Phát thành công.
  - `409 Conflict`: Thiết bị đang bận học lệnh (ARMED), từ chối phát để bảo vệ phần cứng.
  - `404 Not Found`: Không tìm thấy key trong NVS.
  - `500 Internal Error`: Lỗi giải mã hoặc phần cứng.
- `GET /api/ir/export?key=KEY`: Xuất key ra file JSON kèm metadata và mảng `durations`.
- `POST /api/ir/import?key=KEY`: Nhập key từ JSON (kiểm tra độ dài, giới hạn 10 - 1200 pulses).
- `POST /api/ir/migrate`: Chạy quét di trú NVS theo yêu cầu.
- `GET /api/ir/storage`: Lấy số liệu phân vùng NVS (`used_entries`, `free_entries`, dung lượng ước tính).

---

## 8. Hướng dẫn Kiểm thử Hồi quy trên Máy Host (Host Unit Testing)

Component cung cấp bộ test suite độc lập chạy trực tiếp trên macOS/Linux mà không cần nạp vào ESP32:

```bash
# Biên dịch và chạy bộ test host
clang -O2 -Wall -Wextra -Icomponents/mgr_ir_protocols/include test/test_ir_waveform_host.c -o test/test_ir_waveform_host
./test/test_ir_waveform_host
```

**Các ca kiểm thử tự động bao gồm:**
1. `test_waveform_normalization`: Kiểm tra loại bỏ leading space, lọc 0-duration, cắt trailing zero.
2. `test_odd_duration_overread_prevention`: Kiểm tra ngăn chặn lỗi đọc tràn bộ nhớ với mảng durations số lẻ.
3. `test_v1_serialization_and_deserialization`: Kiểm tra đóng gói Header V1, endianness và giải mã.
4. `test_crc32_corruption_detection`: Kiểm tra phát hiện hỏng dữ liệu khi payload bị thay đổi 1 bit.
5. `test_legacy_raw_upgrade`: Kiểm tra nâng cấp tự động bản ghi Legacy 0xAA RAW -> V1.
6. `test_legacy_matrix_upgrade`: Kiểm tra nâng cấp tự động mảng Legacy Matrix -> V1.

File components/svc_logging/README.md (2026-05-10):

# Component: Logging Service (svc_logging)

## 1. Tổng quan (Overview)
Component này cung cấp một hệ thống lưu trữ log hệ thống vào bộ nhớ tạm (In-memory buffer). Mục đích là để người dùng có thể xem lại các sự kiện, lỗi hệ thống thông qua giao diện Web UI mà không cần phải kết nối thiết bị với máy tính qua cổng Serial.

## 2. Tính năng (Features)
- Thu thập log từ `ESP_LOGX`.
- Lưu trữ log trong một Ring Buffer cố định để tránh tràn bộ nhớ.
- Cung cấp API để lấy toàn bộ nội dung log dưới dạng text.

## 3. Phụ thuộc (Dependencies)
- `esp_log`: Tích hợp trực tiếp với hệ thống logging của ESP-IDF.

## 4. Hướng dẫn sử dụng (Usage Example)

```c
#include "svc_log.h"

void app_main(void) {
    // Khởi tạo service
    svc_log_init();
    
    // Sử dụng ESP_LOG thông thường, dữ liệu sẽ tự động được copy vào buffer
    ESP_LOGI("APP", "System Started");
}

// Trong code Web Server:
void get_logs_handler() {
    char log_buf[2048];
    svc_log_get_buffer(log_buf, sizeof(log_buf));
    // Gửi log_buf về trình duyệt...
}
```

## 5. API chính (Main API)

### `void svc_log_init(void)`
Khởi tạo vùng nhớ đệm cho log và đăng ký hook vào hệ thống logging.

### `int svc_log_get_buffer(char *dest, size_t max_len)`
Copy nội dung log hiện có vào chuỗi `dest`.

### `void svc_log_clear(void)`
Xóa sạch bộ nhớ đệm log.

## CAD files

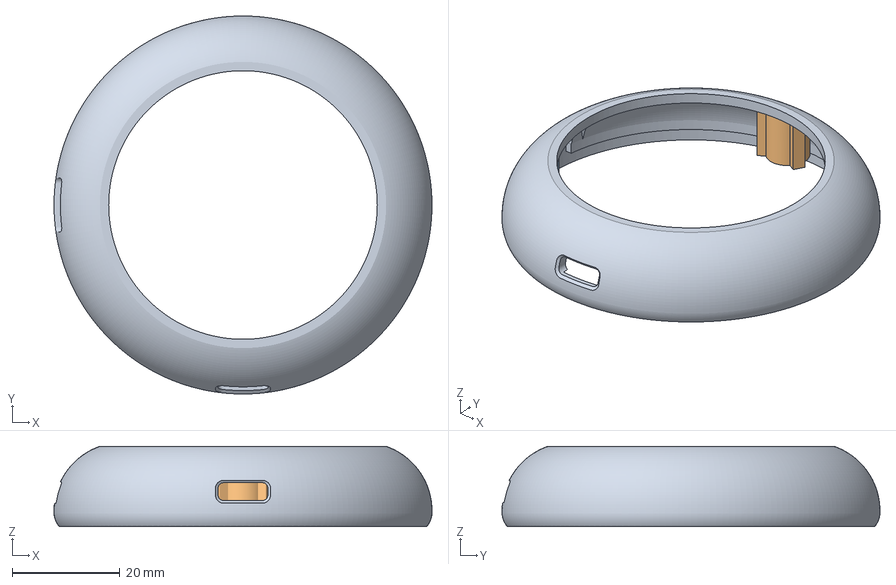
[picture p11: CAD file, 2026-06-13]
hardware/3d_print/Body.3mf
70.0 x 70.0 x 14.9 mm
Body_119*
Body_119*_(2)
Body_119*_(3)

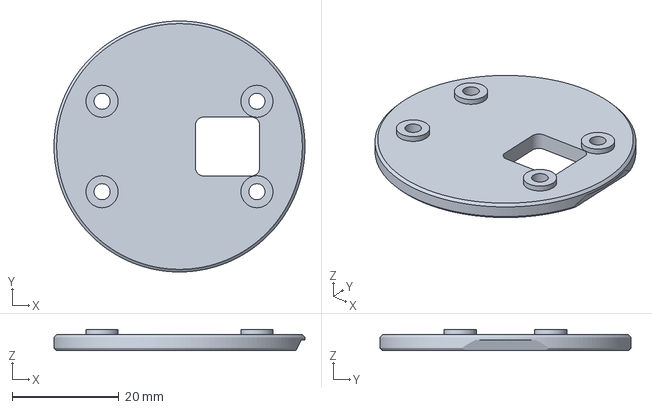
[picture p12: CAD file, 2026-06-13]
hardware/3d_print/Top.3mf
47.0 x 47.0 x 4.00 mm

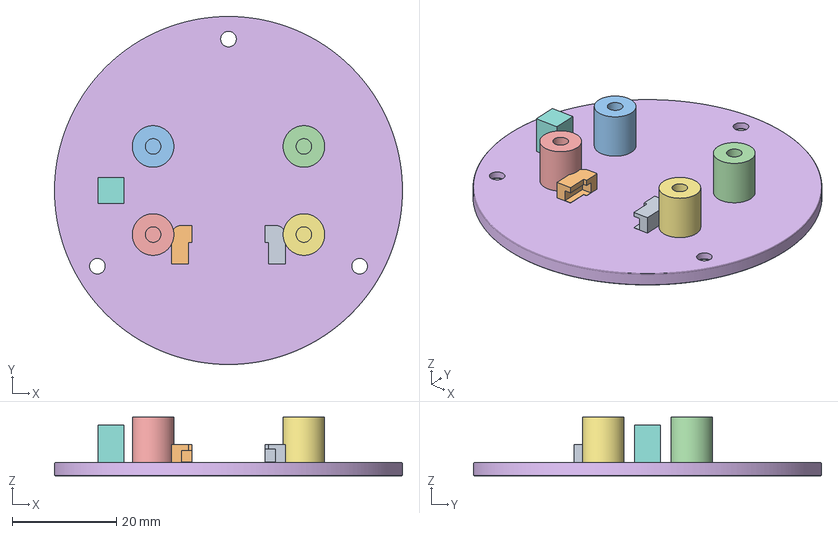
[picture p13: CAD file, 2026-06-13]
hardware/3d_print/Holder.3mf
66.9 x 66.9 x 11.3 mm
Cover
Cover_(2)
Cover_(3)
Cover_(4)
Cover_(5)
base
Cover_(6)
button_holder

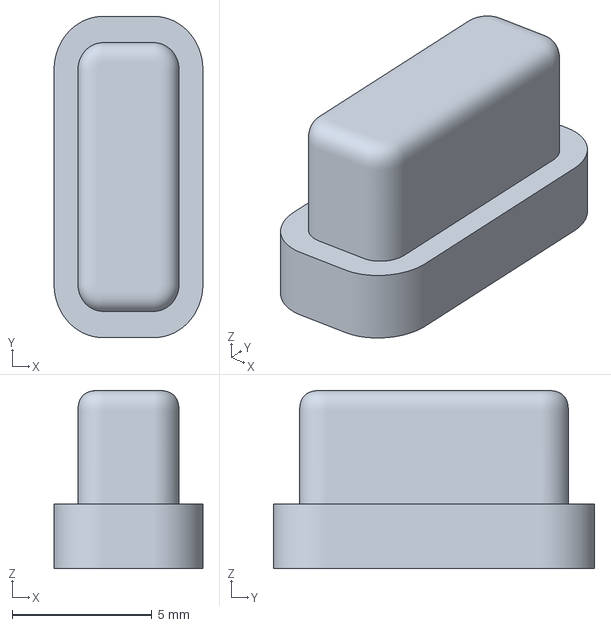
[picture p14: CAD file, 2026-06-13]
hardware/3d_print/Button.3mf
5.32 x 11.5 x 6.36 mm

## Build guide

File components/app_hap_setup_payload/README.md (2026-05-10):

# Component: HomeKit Setup Payload (app_hap_setup_payload)

## 1. Tổng quan (Overview)
Component này chịu trách nhiệm tạo ra các thông tin cần thiết để người dùng có thể thêm thiết bị vào ứng dụng Nhà (Home) của Apple. Nó xử lý việc tạo mã Setup Code, Setup ID và quản lý trạng thái ghép đôi (Pairing).

## 2. Tính năng (Features)
- Định nghĩa mã PIN HomeKit (mặc định hoặc từ cấu hình).
- Phân loại loại thiết bị (Category) cho HomeKit (e.g. Bridge, Air Conditioner, Fan).
- Cung cấp thông tin để tạo mã QR Code hoặc mã PIN 8 số.

## 3. Phụ thuộc (Dependencies)
- `esp-homekit-sdk`: SDK HomeKit của Espressif.

## 4. Hướng dẫn sử dụng (Usage Example)

```c
#include "app_hap_setup_payload.h"

void app_main(void) {
    char setup_code[10]; // e.g. "111-22-333"
    char setup_id[5];    // e.g. "NXIR"
    
    // Thường được gọi bởi int_homekit để chuẩn bị payload
    app_hap_setup_payload(setup_code, setup_id, false, 2); // Category 2 = Bridge
}
```

## 5. API chính (Main API)

### `void app_hap_setup_payload(char *setup_code, char *setup_id, bool paired, uint8_t category)`
Thiết lập các tham số định danh cho thiết bị trong mạng HomeKit.
- `setup_code`: Mã PIN 8 số dùng để nhập tay.
- `setup_id`: Mã ID dùng cho QR code.
- `paired`: Trạng thái đã ghép đôi hay chưa.
- `category`: Loại thiết bị theo định nghĩa của Apple.

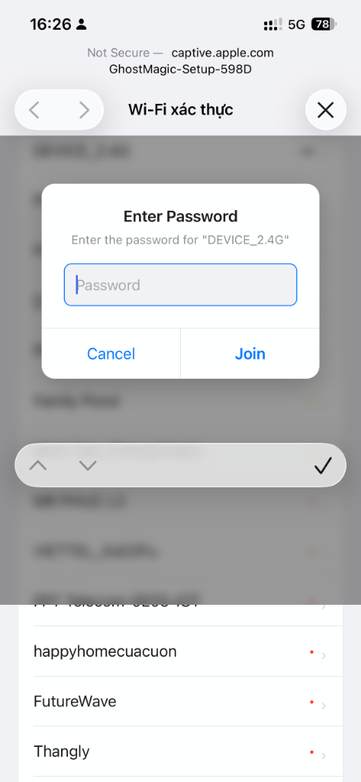
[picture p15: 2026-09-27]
docs/images/step4_raw.png

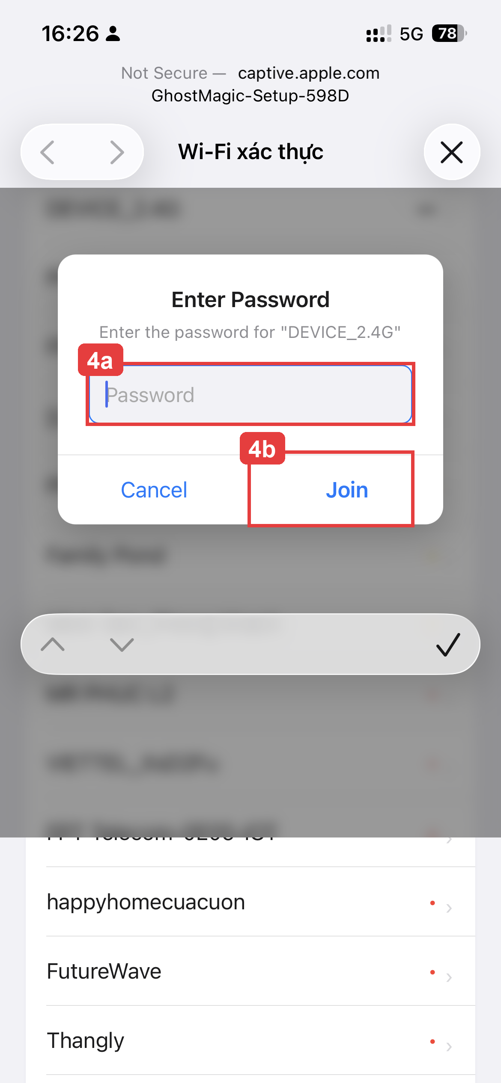
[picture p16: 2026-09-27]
docs/images/step4_annotated.png

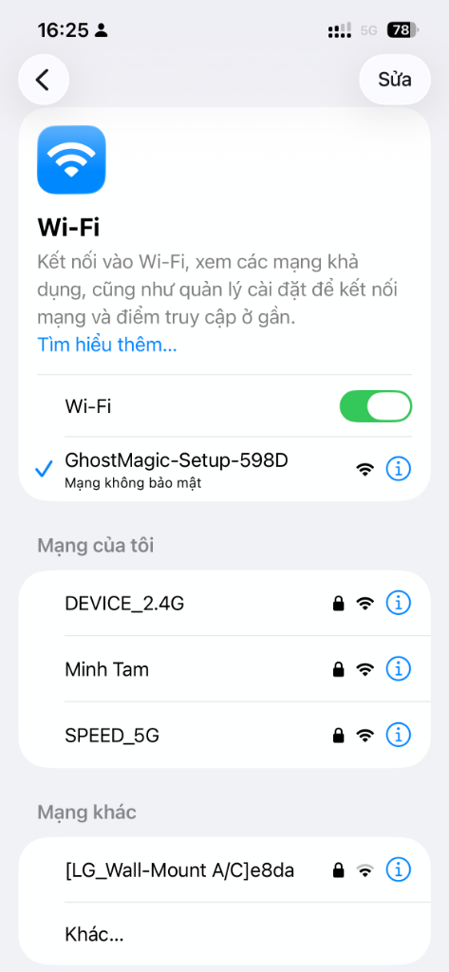
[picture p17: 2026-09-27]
docs/images/step2_raw.png

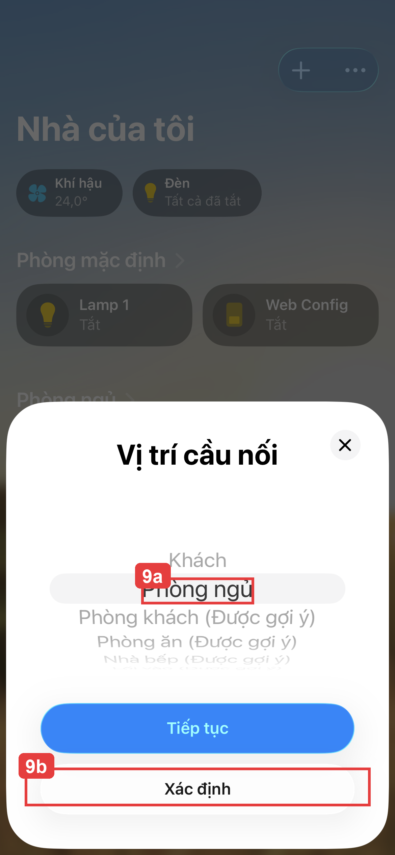
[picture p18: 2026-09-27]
docs/images/step9_annotated.png

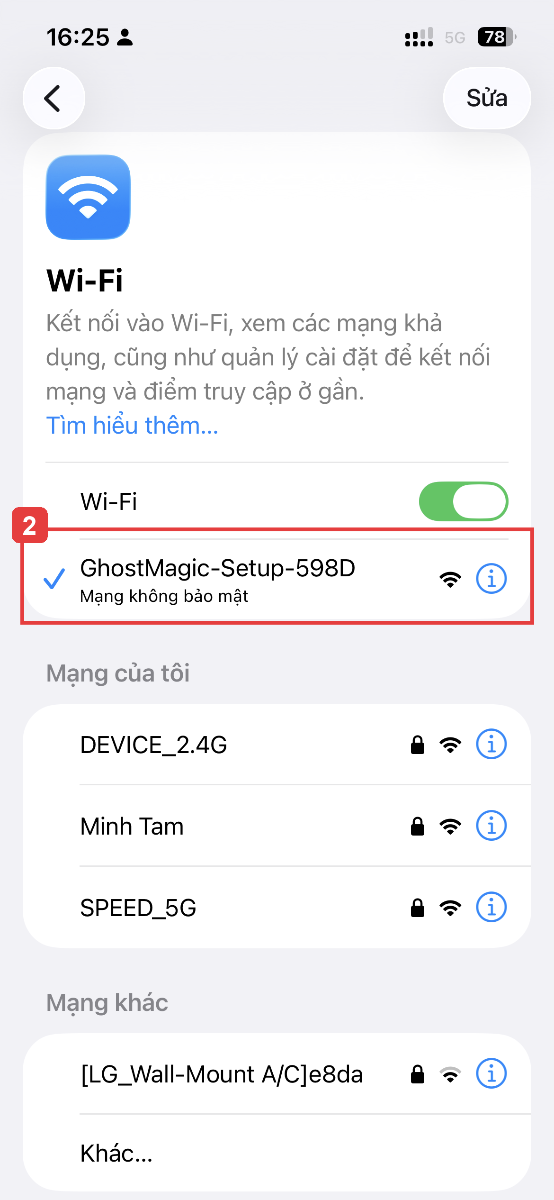
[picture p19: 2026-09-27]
docs/images/step2_annotated.png

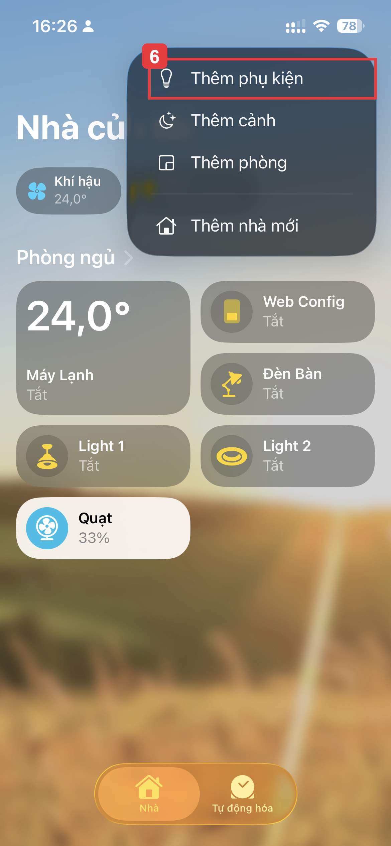
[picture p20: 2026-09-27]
docs/images/step6_annotated.png

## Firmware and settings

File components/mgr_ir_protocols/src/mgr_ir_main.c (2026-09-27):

/**
 * @file mgr_ir_main.c
 * @brief High-level IR Application Layer & Protocol Manager (Phase 3 - Migration & Export/Import)
 */

#include "driver/gpio.h"
#include "driver/rmt_rx.h"
#include "driver/rmt_tx.h"
#include "drv_led.h"
#include "esp_log.h"
#include "esp_timer.h"
#include "esp_heap_caps.h"
#include "freertos/FreeRTOS.h"
#include "freertos/task.h"
#include "freertos/queue.h"
#include "freertos/semphr.h"
#include "mgr_ir_protocols.h"
#include "mgr_ir_waveform.h"
#include "sdkconfig.h"
#include "svc_nvs.h"
#include "drv_ir_rmt.h"
#include "ir_engine.h"
#include "nvs.h"
#include "nvs_flash.h"
#include "cJSON.h"
#include <esp_rom_sys.h>
#include <esp_rom_crc.h>
#include <inttypes.h>
#include <string.h>
#include <ctype.h>

#define TAG "mgr_ir"

#ifndef CONFIG_APP_IR_RX_GPIO
#define IR_RX_GPIO -1
#else
#define IR_RX_GPIO CONFIG_APP_IR_RX_GPIO
#endif

#ifndef CONFIG_APP_IR_TX_GPIO
#define IR_TX_GPIO -1
#else
#define IR_TX_GPIO CONFIG_APP_IR_TX_GPIO
#endif

#define RMT_RESOLUTION_HZ 1000000 // 1MHz, 1 tick = 1us
#define APP_IR_MIN_SYMBOLS 20     // Minimum symbols to be considered valid IR
#define MAX_IR_SYMBOLS 600        // Maximum RMT symbol words (~1200 edges)
#define IR_QUEUE_DEPTH 10
#define DEFAULT_LEARN_TIMEOUT_MS 15000

typedef enum {
  IR_EVT_RX_DONE,
  IR_EVT_TIMEOUT
} ir_event_type_t;

typedef struct {
  ir_event_type_t type;
  uint32_t session_id;
  uint32_t num_symbols;
} ir_event_t;

static esp_timer_handle_t s_timeout_timer = NULL;
static QueueHandle_t s_ir_evt_queue = NULL;
static TaskHandle_t s_ir_task_handle = NULL;
static SemaphoreHandle_t s_ir_mutex = NULL;

// Session and state management
static uint32_t s_current_session_id = 0;
static ir_session_state_t s_session_state = IR_STATE_IDLE;
static bool s_is_slave_mode = false;
static mgr_ir_rx_cb_t s_rx_callback = NULL;

// DMA Learning Buffer
static rmt_symbol_word_t *s_learning_symbols = NULL;
static uint32_t s_learning_num_symbols = 0;
static bool s_learning_is_truncated = false;

static void *mgr_ir_malloc(size_t size) {
  void *ptr = heap_caps_malloc(size, MALLOC_CAP_SPIRAM | MALLOC_CAP_8BIT);
  if (ptr == NULL) {
    ptr = malloc(size);
  }
  return ptr;
}

static void normalize_key(char *dst, const char *src, size_t max_len) {
  size_t i = 0;
  for (; i < max_len - 1 && src[i]; i++) {
    dst[i] = toupper((unsigned char)src[i]);
  }
  dst[i] = '\0';
}

void mgr_ir_set_rx_callback(mgr_ir_rx_cb_t cb) {
  s_rx_callback = cb;
}

// Ultra-thin, 100% ISR-safe RMT RX Done Callback (HAL-driven)
static bool app_ir_rx_done_callback(size_t num_symbols, void *user_ctx) {
  BaseType_t high_task_wakeup = pdFALSE;
  if (s_ir_evt_queue) {
    ir_event_t evt = {
      .type = IR_EVT_RX_DONE,
      .session_id = s_current_session_id,
      .num_symbols = (uint32_t)num_symbols,
    };
    xQueueSendFromISR(s_ir_evt_queue, &evt, &high_task_wakeup);
  }
  return (high_task_wakeup == pdTRUE);
}

// Timeout timer callback — dispatches timeout event to queue
static void session_timeout_cb(void *arg) {
  if (s_ir_evt_queue) {
    ir_event_t evt = {
      .type = IR_EVT_TIMEOUT,
      .session_id = s_current_session_id,
      .num_symbols = 0,
    };
    xQueueSend(s_ir_evt_queue, &evt, 0);
  }
}

// Background Worker Task: handles migration on boot, all state transitions, and callbacks
static void mgr_ir_worker_task(void *pvParameters) {
  ESP_LOGI(TAG, "IR Worker Task started");

  // Run startup migration check in background without blocking boot
  size_t mig = 0, skp = 0, errs = 0;
  mgr_ir_migrate_all(&mig, &skp, &errs);

  ir_event_t evt;
  while (1) {
    if (xQueueReceive(s_ir_evt_queue, &evt, portMAX_DELAY) != pdTRUE) {
      continue;
    }

    // Drop stale events from outdated sessions (except slave mode)
    if (evt.session_id != s_current_session_id && !s_is_slave_mode) {
      ESP_LOGD(TAG, "Ignoring stale event (evt_sid=%" PRIu32 ", cur_sid=%" PRIu32 ")",
               evt.session_id, s_current_session_id);
      continue;
    }

    switch (evt.type) {
      case IR_EVT_RX_DONE: {
        if (s_is_slave_mode && s_rx_callback) {
          // Slave background listening
          if (evt.num_symbols >= APP_IR_MIN_SYMBOLS) {
            uint32_t logical_count = evt.num_symbols * 2;
            uint16_t *durations = (uint16_t *)malloc(logical_count * sizeof(uint16_t));
            if (durations) {
              const uint16_t *raw_symbols = (const uint16_t *)s_learning_symbols;
              for (uint32_t i = 0; i < logical_count; i++) {
                durations[i] = raw_symbols[i] & 0x7FFF;
              }
              s_rx_callback(durations, logical_count);
              free(durations);
            }
          }
          // Re-arm RX for next frame via HAL
          ir_engine_rx_start(s_learning_symbols,
                             MAX_IR_SYMBOLS * sizeof(rmt_symbol_word_t));
          break;
        }

        // Learning Mode processing
        if (s_session_state == IR_STATE_ARMED) {
          if (evt.num_symbols < APP_IR_MIN_SYMBOLS) {
            ESP_LOGW(TAG, "Session %" PRIu32 ": IR Noise (%" PRIu32 " symbols < %d). Re-arming...",
                     evt.session_id, evt.num_symbols, APP_IR_MIN_SYMBOLS);
            drv_led_set_state(DRV_LED_IR_FAIL);

            // Debounce delay to let optical noise settle
            vTaskDelay(pdMS_TO_TICKS(300));
            if (s_session_state == IR_STATE_ARMED && evt.session_id == s_current_session_id) {
              drv_led_set_state(DRV_LED_IR_LEARN);
              ir_engine_rx_start(s_learning_symbols,
                                 MAX_IR_SYMBOLS * sizeof(rmt_symbol_word_t));
            }
          } else {
            // Valid signal captured!
            esp_timer_stop(s_timeout_timer);
            ir_engine_rx_stop();

            xSemaphoreTake(s_ir_mutex, portMAX_DELAY);
            s_learning_num_symbols = (evt.num_symbols > MAX_IR_SYMBOLS)
                                         ? MAX_IR_SYMBOLS
                                         : evt.num_symbols;
            s_learning_is_truncated = (evt.num_symbols >= MAX_IR_SYMBOLS);
            s_session_state = IR_STATE_CAPTURED;
            xSemaphoreGive(s_ir_mutex);

            drv_led_set_state(DRV_LED_IR_SUCCESS);
            ESP_LOGI(TAG, "Session %" PRIu32 " CAPTURED: %" PRIu32 " symbols%s",
                     evt.session_id, s_learning_num_symbols,
                     s_learning_is_truncated ? " (TRUNCATED)" : "");

            // Flash SUCCESS for 1 second, then revert to IDLE
            vTaskDelay(pdMS_TO_TICKS(1000));
            if (s_session_state == IR_STATE_CAPTURED) {
              drv_led_set_state(DRV_LED_IDLE);
            }
          }
        }
        break;
      }

      case IR_EVT_TIMEOUT: {
        if (s_session_state == IR_STATE_ARMED) {
          ESP_LOGW(TAG, "Learn Session %" PRIu32 " TIMED OUT after 15s without valid IR signal",
                   evt.session_id);
          ir_engine_rx_stop();

          xSemaphoreTake(s_ir_mutex, portMAX_DELAY);
          s_session_state = IR_STATE_TIMEOUT;
          xSemaphoreGive(s_ir_mutex);

          drv_led_set_state(DRV_LED_IDLE);
        }
        break;
      }

      default:
        break;
    }
  }
}

esp_err_t mgr_ir_init(void) {
  if (IR_RX_GPIO == -1 || IR_TX_GPIO == -1) {
    ESP_LOGI(TAG, "IR GPIOs not configured, skipping IR init");
    return ESP_OK;
  }

  ESP_LOGI(TAG, "Initializing IR RX on GPIO %d, TX on GPIO %d", IR_RX_GPIO, IR_TX_GPIO);

  if (s_ir_mutex == NULL) {
    s_ir_mutex = xSemaphoreCreateMutex();
    if (!s_ir_mutex) {
      ESP_LOGE(TAG, "Failed to create IR mutex");
      return ESP_ERR_NO_MEM;
    }
  }

  if (s_ir_evt_queue == NULL) {
    s_ir_evt_queue = xQueueCreate(IR_QUEUE_DEPTH, sizeof(ir_event_t));
    if (!s_ir_evt_queue) {
      ESP_LOGE(TAG, "Failed to create IR event queue");
      return ESP_ERR_NO_MEM;
    }
  }

  s_learning_symbols = (rmt_symbol_word_t *)heap_caps_malloc(
      MAX_IR_SYMBOLS * sizeof(rmt_symbol_word_t),
      MALLOC_CAP_INTERNAL | MALLOC_CAP_DMA);
  if (!s_learning_symbols) {
    ESP_LOGE(TAG, "Failed to allocate learning DMA buffer");
    return ESP_ERR_NO_MEM;
  }

  ir_rx_engine_config_t rx_cfg = {
      .gpio_num = IR_RX_GPIO,
      .resolution_hz = RMT_RESOLUTION_HZ,
      .mem_block_symbols = 64,
      .rx_done_cb = app_ir_rx_done_callback,
      .user_ctx = NULL,
  };
  esp_err_t rx_init_err = ir_engine_rx_init(&rx_cfg);
  if (rx_init_err != ESP_OK) {
    ESP_LOGE(TAG, "Failed to initialize IR RX Engine: %s", esp_err_to_name(rx_init_err));
    return rx_init_err;
  }

  // Initialize TX Engine
  ir_engine_config_t engine_cfg = {
      .gpio_num = IR_TX_GPIO,
      .resolution_hz = RMT_RESOLUTION_HZ,
  };
  ESP_ERROR_CHECK(ir_engine_init(&engine_cfg));

  // Session Timeout Timer (15s)
  esp_timer_create_args_t timer_args = {
      .callback = session_timeout_cb,
      .name = "ir_timeout",
  };
  ESP_ERROR_CHECK(esp_timer_create(&timer_args, &s_timeout_timer));

  // Launch Worker Task
  if (s_ir_task_handle == NULL) {
    BaseType_t ret = xTaskCreate(mgr_ir_worker_task, "ir_worker", 4096, NULL, 5, &s_ir_task_handle);
    if (ret != pdPASS) {
      ESP_LOGE(TAG, "Failed to spawn IR worker task");
      return ESP_FAIL;
    }
  }

  ESP_LOGI(TAG, "IR Core V3 (Event-Driven + Migration Engine) Initialized");
  return ESP_OK;
}

esp_err_t mgr_ir_start_slave(void) {
  ESP_LOGI(TAG, "Starting IR Slave Mode...");
  s_is_slave_mode = true;
  return ir_engine_rx_start(s_learning_symbols,
                            MAX_IR_SYMBOLS * sizeof(rmt_symbol_word_t));
}

esp_err_t mgr_ir_start_learn_with_timeout(uint32_t timeout_ms, uint32_t *out_session_id) {
  if (!s_ir_mutex)
    return ESP_ERR_INVALID_STATE;

  xSemaphoreTake(s_ir_mutex, portMAX_DELAY);
  s_current_session_id++;
  uint32_t session_id = s_current_session_id;
  s_session_state = IR_STATE_ARMED;
  s_learning_num_symbols = 0;
  s_learning_is_truncated = false;
  xSemaphoreGive(s_ir_mutex);

  esp_timer_stop(s_timeout_timer);

  ir_engine_rx_stop();

  esp_err_t err = ir_engine_rx_start(s_learning_symbols,
                                    MAX_IR_SYMBOLS * sizeof(rmt_symbol_word_t));
  if (err != ESP_OK) {
    ESP_LOGE(TAG, "ir_engine_rx_start failed: %s", esp_err_to_name(err));
    xSemaphoreTake(s_ir_mutex, portMAX_DELAY);
    s_session_state = IR_STATE_ERROR;
    xSemaphoreGive(s_ir_mutex);
    return err;
  }

  drv_led_set_state(DRV_LED_IR_LEARN);

  uint64_t timeout_us = (uint64_t)timeout_ms * 1000ULL;
  esp_timer_start_once(s_timeout_timer, timeout_us);

  ESP_LOGI(TAG, "Started Learn Session %" PRIu32 " (Timeout: %" PRIu32 " ms)", session_id, timeout_ms);
  if (out_session_id) *out_session_id = session_id;
  return ESP_OK;
}

esp_err_t mgr_ir_start_learn(void) {
  return mgr_ir_start_learn_with_timeout(DEFAULT_LEARN_TIMEOUT_MS, NULL);
}

esp_err_t mgr_ir_stop_learn(void) {
  if (!s_ir_mutex)
    return ESP_ERR_INVALID_STATE;

  xSemaphoreTake(s_ir_mutex, portMAX_DELAY);
  s_current_session_id++; // Invalidate any pending events for the current session
  s_session_state = IR_STATE_CANCELLED;
  xSemaphoreGive(s_ir_mutex);

  esp_timer_stop(s_timeout_timer);
  ir_engine_rx_stop();
  drv_led_set_state(DRV_LED_IDLE);

  ESP_LOGI(TAG, "Learn session cancelled by user");
  return ESP_OK;
}

esp_err_t mgr_ir_cancel_learn(void) {
  return mgr_ir_stop_learn();
}

bool mgr_ir_is_data_ready(void) {
  return (s_session_state == IR_STATE_CAPTURED && s_learning_num_symbols >= APP_IR_MIN_SYMBOLS);
}

bool mgr_ir_get_learn_status(uint32_t *count) {
  if (count)
    *count = s_learning_num_symbols;
  return (s_session_state == IR_STATE_ARMED);
}

esp_err_t mgr_ir_get_session_info(mgr_ir_session_info_t *out_info) {
  if (!out_info || !s_ir_mutex)
    return ESP_ERR_INVALID_ARG;

  if (xSemaphoreTake(s_ir_mutex, pdMS_TO_TICKS(100)) != pdTRUE) {
    return ESP_ERR_TIMEOUT;
  }
  out_info->session_id = s_current_session_id;
  out_info->state = s_session_state;
  out_info->symbol_count = s_learning_num_symbols;
  out_info->is_truncated = s_learning_is_truncated;
  xSemaphoreGive(s_ir_mutex);
  return ESP_OK;
}

esp_err_t mgr_ir_copy_learning_buffer(rmt_symbol_word_t *dst, size_t max_words,
                                      size_t *out_words, bool *out_is_truncated) {
  if (!dst || max_words == 0 || !s_learning_symbols) return ESP_ERR_INVALID_ARG;
  if (!s_ir_mutex) return ESP_ERR_INVALID_STATE;

  if (xSemaphoreTake(s_ir_mutex, pdMS_TO_TICKS(2000)) != pdTRUE) {
    return ESP_ERR_TIMEOUT;
  }

  if (s_session_state != IR_STATE_CAPTURED && s_learning_num_symbols < APP_IR_MIN_SYMBOLS) {
    xSemaphoreGive(s_ir_mutex);
    return ESP_ERR_NOT_FOUND;
  }

  size_t copy_words = (s_learning_num_symbols > max_words) ? max_words : s_learning_num_symbols;
  memcpy(dst, s_learning_symbols, copy_words * sizeof(rmt_symbol_word_t));

  if (out_words) *out_words = copy_words;
  if (out_is_truncated) *out_is_truncated = s_learning_is_truncated;

  xSemaphoreGive(s_ir_mutex);
  return ESP_OK;
}

esp_err_t mgr_ir_save_learned_with_params(const char *key, uint8_t repeat_count, uint16_t repeat_gap_ms) {
  char upper_key[32] = {0};
  normalize_key(upper_key, key, sizeof(upper_key));

  rmt_symbol_word_t *raw_buf = (rmt_symbol_word_t *)mgr_ir_malloc(MAX_IR_SYMBOLS * sizeof(rmt_symbol_word_t));
  if (!raw_buf) return ESP_ERR_NO_MEM;

  size_t captured_words = 0;
  bool is_truncated = false;
  esp_err_t err = mgr_ir_copy_learning_buffer(raw_buf, MAX_IR_SYMBOLS, &captured_words, &is_truncated);
  if (err != ESP_OK) {
    ESP_LOGW(TAG, "Insufficient IR data symbols to save for %s", upper_key);
    free(raw_buf);
    return err;
  }

  rmt_symbol_word_t *clean_buf = (rmt_symbol_word_t *)mgr_ir_malloc(MAX_IR_SYMBOLS * sizeof(rmt_symbol_word_t));
  if (!clean_buf) {
    free(raw_buf);
    return ESP_ERR_NO_MEM;
  }

  size_t clean_words = 0;
  size_t clean_durations = 0;
  err = ir_waveform_normalize(raw_buf, captured_words, clean_buf, MAX_IR_SYMBOLS,
                              &clean_words, &clean_durations);
  free(raw_buf);

  if (err != ESP_OK) {
    ESP_LOGE(TAG, "Waveform normalization failed for %s: %s", upper_key, esp_err_to_name(err));
    free(clean_buf);
    return err;
  }

  uint8_t flags = is_truncated ? IR_FLAG_TRUNCATED : IR_FLAG_NONE;
  uint8_t *v1_record = NULL;
  size_t record_size = 0;

  err = ir_waveform_serialize_v1(clean_buf, clean_durations, repeat_count, repeat_gap_ms,
                                 flags, &v1_record, &record_size);
  free(clean_buf);

  if (err != ESP_OK) {
    return err;
  }

  ESP_LOGI(TAG, "Saving V1 IR [%s]: %d durations, %d bytes (Repeats: %d, Truncated: %s)",
           upper_key, (int)clean_durations, (int)record_size, repeat_count, is_truncated ? "YES" : "NO");

  err = svc_nvs_save_ir(upper_key, v1_record, record_size);
  free(v1_record);

  if (err == ESP_OK) {
    xSemaphoreTake(s_ir_mutex, portMAX_DELAY);
    s_session_state = IR_STATE_IDLE; // Reset to IDLE upon successful save
    xSemaphoreGive(s_ir_mutex);
  }
  return err;
}

esp_err_t mgr_ir_save_learned_result(const char *key) {
  uint8_t repeat_count = (strncmp(key, "F_", 2) == 0 || strncmp(key, "f_", 2) == 0) ? 1 : 0;
  return mgr_ir_save_learned_with_params(key, repeat_count, IR_DEFAULT_REPEAT_GAP);
}

esp_err_t mgr_ir_send_key(const char *key) {
  if (s_session_state == IR_STATE_ARMED) {
    ESP_LOGW(TAG, "Cannot send IR while learning session is ARMED");
    return ESP_ERR_INVALID_STATE;
  }

  char upper_key[32] = {0};
  normalize_key(upper_key, key, sizeof(upper_key));

  size_t loaded_size = 0;
  if (svc_nvs_load_ir(upper_key, NULL, &loaded_size) != ESP_OK || loaded_size < 5) {
    ESP_LOGW(TAG, "Key %s not found in NVS", upper_key);
    return ESP_ERR_NOT_FOUND;
  }

  uint8_t *buffer = (uint8_t *)mgr_ir_malloc(loaded_size);
  if (!buffer)
    return ESP_ERR_NO_MEM;

  esp_err_t err = svc_nvs_load_ir(upper_key, buffer, &loaded_size);
  if (err != ESP_OK) {
    free(buffer);
    return err;
  }

  // Automatic On-Access Migration: If legacy format detected, upgrade to V1 with CRC32
  bool is_v1 = (loaded_size >= sizeof(ir_record_header_t) &&
                ((ir_record_header_t *)buffer)->magic == IR_RECORD_MAGIC);
  if (!is_v1) {
    uint8_t def_repeat = (strncmp(upper_key, "F_", 2) == 0) ? 1 : 0;
    uint8_t *v1_buf = NULL;
    size_t v1_size = 0;
    if (ir_waveform_upgrade_legacy(buffer, loaded_size, def_repeat, &v1_buf, &v1_size) == ESP_OK) {
      svc_nvs_save_ir(upper_key, v1_buf, v1_size);
      ESP_LOGI(TAG, "On-Access Migration: Key [%s] upgraded to V1 with CRC32", upper_key);
      free(buffer);
      buffer = v1_buf;
      loaded_size = v1_size;
    }
  }

  // Dynamic Carrier configuration (IR-17)
  if (loaded_size >= sizeof(ir_record_header_t)) {
    const ir_record_header_t *hdr = (const ir_record_header_t *)buffer;
    if (hdr->magic == IR_RECORD_MAGIC) {
      uint32_t freq = (hdr->carrier_freq_hz >= 10000 && hdr->carrier_freq_hz <= 60000)
                          ? hdr->carrier_freq_hz
                          : IR_DEFAULT_CARRIER_HZ;
      float duty = (hdr->duty_cycle >= 10 && hdr->duty_cycle <= 90)
                       ? ((float)hdr->duty_cycle / 100.0f)
                       : 0.33f;
      ir_engine_set_carrier(freq, duty);
    }
  }

  rmt_symbol_word_t *tx_symbols = NULL;
  size_t word_count = 0;
  uint8_t repeat_count = 0;
  uint16_t repeat_gap_ms = IR_DEFAULT_REPEAT_GAP;

  err = ir_waveform_deserialize(buffer, loaded_size, &tx_symbols, &word_count,
                                &repeat_count, &repeat_gap_ms);
  free(buffer);

  if (err != ESP_OK || !tx_symbols || word_count == 0) {
    ESP_LOGE(TAG, "Failed to deserialize IR key %s: %s", upper_key, esp_err_to_name(err));
    if (tx_symbols) free(tx_symbols);
    return (err != ESP_OK) ? err : ESP_FAIL;
  }

  ESP_LOGI(TAG, "Transmitting IR [%s]: %d words, repeats: %d (gap: %d ms)",
           upper_key, (int)word_count, (int)repeat_count, (int)repeat_gap_ms);

  drv_led_set_state(DRV_LED_IR_TX);

  err = ir_engine_send_raw(tx_symbols, word_count);

  for (uint8_t rep = 0; rep < repeat_count && err == ESP_OK; rep++) {
    vTaskDelay(pdMS_TO_TICKS(repeat_gap_ms));
    err = ir_engine_send_raw(tx_symbols, word_count);
  }

  drv_led_set_state(DRV_LED_IDLE);
  free(tx_symbols);
  return err;
}

esp_err_t mgr_ir_send_raw(const uint16_t *durations, size_t count) {
  if (count == 0 || durations == NULL)
    return ESP_ERR_INVALID_ARG;

  size_t alloc_size = count * sizeof(uint16_t);
  if (alloc_size % 4 != 0)
    alloc_size += 2;

  rmt_symbol_word_t *tx_symbols = (rmt_symbol_word_t *)mgr_ir_malloc(alloc_size);
  if (!tx_symbols) {
    ESP_LOGE(TAG, "Failed to allocate memory for %d raw symbols", (int)count);
    return ESP_ERR_NO_MEM;
  }

  uint16_t *tx_raw = (uint16_t *)tx_symbols;
  for (size_t i = 0; i < count; i++) {
    uint16_t level = (i % 2 == 0) ? 1 : 0;
    uint16_t duration = durations[i];
    tx_raw[i] = duration | (level << 15);
  }

  ESP_LOGI(TAG, "Sending Raw IR Signal (%d pulses/spaces)...", (int)count);
  drv_led_set_state(DRV_LED_IR_TX);

  size_t word_count = (alloc_size / sizeof(rmt_symbol_word_t));
  esp_err_t err = ir_engine_send_raw(tx_symbols, word_count);
  if (err != ESP_OK) {
    ESP_LOGE(TAG, "IR Send Raw Failed: %s", esp_err_to_name(err));
  }

  drv_led_set_state(DRV_LED_IDLE);
  free(tx_symbols);
  return err;
}

esp_err_t mgr_ir_send_cmd(mgr_ir_cmd_t cmd) {
  return mgr_ir_send_key((cmd == APP_IR_CMD_AC_ON) ? "ac_on" : "ac_off");
}

bool mgr_ir_send_key_exists(const char *prefix, const char *brand,
                            const char *suffix) {
  char short_brand[16] = {0};
  int idx = 0;
  for (int i = 0; brand[i] && idx < 15; i++) {
    char c = brand[i];
    if ((c >= 'a' && c <= 'z') || (c >= 'A' && c <= 'Z') ||
        (c >= '0' && c <= '9')) {
      short_brand[idx++] = c;
    }
  }

  char key[32];
  snprintf(key, sizeof(key), "%s%s_%s", prefix, short_brand, suffix);

  char upper_key[32] = {0};
  normalize_key(upper_key, key, sizeof(upper_key));

  size_t loaded_size = 0;
  if (svc_nvs_load_ir(upper_key, NULL, &loaded_size) == ESP_OK && loaded_size > 0) {
    return true;
  }
  return false;
}
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

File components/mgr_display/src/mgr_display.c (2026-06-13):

#include "mgr_display.h"

#if CONFIG_APP_LCD_ENABLE

#include "driver/gpio.h"
#include "driver/spi_master.h"
#include "esp_lcd_gc9a01.h"
#include "esp_lcd_panel_io.h"
#include "esp_lcd_panel_ops.h"
#include "esp_lcd_panel_vendor.h"
#include "esp_log.h"
#include "freertos/FreeRTOS.h"
#include "freertos/semphr.h"
#include "freertos/task.h"
#include "freertos/timers.h"
#include "driver/ledc.h"
#include "lvgl.h"

static SemaphoreHandle_t lv_mux = NULL;

static const char *TAG = "MGR_DISPLAY";

// Pin definitions from Kconfig
#define LCD_GPIO_LED CONFIG_APP_LCD_BACKLIGHT_GPIO
#define LCD_GPIO_CS CONFIG_APP_LCD_CS_GPIO
#define LCD_GPIO_DC CONFIG_APP_LCD_DC_GPIO
#define LCD_GPIO_RST CONFIG_APP_LCD_RST_GPIO
#define LCD_GPIO_SCLK CONFIG_APP_LCD_SCLK_GPIO
#define LCD_GPIO_MOSI CONFIG_APP_LCD_MOSI_GPIO

#define LCD_H_RES CONFIG_APP_LCD_H_RES
#define LCD_V_RES CONFIG_APP_LCD_V_RES

#define LCD_SPI_HOST (CONFIG_APP_LCD_SPI_HOST == 0 ? SPI2_HOST : SPI3_HOST)

static esp_lcd_panel_handle_t panel_handle = NULL;
static lv_disp_drv_t disp_drv; // Static to be used in callback context

static TimerHandle_t wake_timer = NULL;
static bool s_is_dimmed = false;

#define BRIGHTNESS_ACTIVE 255 // 100%
#define BRIGHTNESS_IDLE   25  // ~10% (out of 255)

static void mgr_display_set_brightness(uint8_t value) {
  esp_err_t err = ledc_set_duty(LEDC_LOW_SPEED_MODE, LEDC_CHANNEL_5, value);
  if (err == ESP_OK) {
      ledc_update_duty(LEDC_LOW_SPEED_MODE, LEDC_CHANNEL_5);
  } else {
      ESP_LOGE(TAG, "Failed to set LEDC duty: %s", esp_err_to_name(err));
  }
  s_is_dimmed = (value < BRIGHTNESS_ACTIVE);
}

static void wake_timer_cb(TimerHandle_t xTimer) {
  ESP_LOGI(TAG, "Display timeout, dimming to idle level");
  mgr_display_set_brightness(BRIGHTNESS_IDLE);
}

// Function declarations from mgr_display_ui.c
void mgr_display_ui_init(void);
void mgr_display_update_ui_time(void);
void mgr_display_update_ui_sensor(float temp, float hum);
void mgr_display_show_ui_notification(const char *device_name,
                                      const char *status);

void mgr_display_activity_tick(void) {
  mgr_display_wake();
}

static void lvgl_flush_cb(lv_disp_drv_t *drv, const lv_area_t *area,
                          lv_color_t *color_map) {
  esp_lcd_panel_draw_bitmap(panel_handle, area->x1, area->y1, area->x2 + 1,
                            area->y2 + 1, color_map);
  lv_disp_flush_ready(drv);
}

static void lv_tick_task(void *arg) {
  while (1) {
    lv_tick_inc(10);
    vTaskDelay(pdMS_TO_TICKS(10));
  }
}

static void display_task(void *arg) {
  ESP_LOGI(TAG, "Starting LVGL task loop...");
  while (1) {
    uint32_t task_delay_ms = 10;
    if (xSemaphoreTakeRecursive(lv_mux, pdMS_TO_TICKS(1000)) == pdTRUE) {
      task_delay_ms = lv_timer_handler();
      xSemaphoreGiveRecursive(lv_mux);
    } else {
      ESP_LOGE(TAG, "CRITICAL: Display task blocked for 1000ms!");
    }

    // Cap delay to prevent display_task sleeping forever, but allow enough for
    // power saving
    if (task_delay_ms < 10)
      task_delay_ms = 10;
    if (task_delay_ms > 500)
      task_delay_ms = 500;
    vTaskDelay(pdMS_TO_TICKS(task_delay_ms));
  }
}

esp_err_t mgr_display_init(void) {
  ESP_LOGI(TAG, "Initializing LCD GC9A01...");

  lv_mux = xSemaphoreCreateRecursiveMutex();
  if (lv_mux == NULL) {
    return ESP_ERR_NO_MEM;
  }

  // 1. Initialize Backlight with LEDC PWM
  ESP_LOGI(TAG, "Initializing Backlight PWM on GPIO %d (Channel 5, Timer 1)", LCD_GPIO_LED);
  ledc_timer_config_t ledc_timer = {
      .speed_mode = LEDC_LOW_SPEED_MODE,
      .duty_resolution = LEDC_TIMER_8_BIT,
      .timer_num = LEDC_TIMER_1,
      .freq_hz = 1000, // Reduced to 1kHz
      .clk_cfg = LEDC_AUTO_CLK};
  ESP_ERROR_CHECK(ledc_timer_config(&ledc_timer));

  ledc_channel_config_t ledc_channel = {.speed_mode = LEDC_LOW_SPEED_MODE,
                                        .channel = LEDC_CHANNEL_5,
                                        .timer_sel = LEDC_TIMER_1,
                                        .intr_type = LEDC_INTR_DISABLE,
                                        .gpio_num = LCD_GPIO_LED,
                                        .duty = BRIGHTNESS_ACTIVE, // Start at 100%
                                        .hpoint = 0};
  ESP_ERROR_CHECK(ledc_channel_config(&ledc_channel));

  // 1.1 Initialize Wake Timer
  wake_timer = xTimerCreate("display_wake", pdMS_TO_TICKS(30000), pdFALSE, NULL,
                            wake_timer_cb);
  if (wake_timer == NULL) {
    ESP_LOGE(TAG, "Failed to create wake timer");
    return ESP_ERR_NO_MEM;
  }
  xTimerStart(wake_timer, 0);

  // 2. Initialize SPI Bus
  spi_bus_config_t buscfg = {
      .sclk_io_num = LCD_GPIO_SCLK,
      .mosi_io_num = LCD_GPIO_MOSI,
      .miso_io_num = -1,
      .quadwp_io_num = -1,
      .quadhd_io_num = -1,
      .max_transfer_sz = LCD_H_RES * 80 * sizeof(uint16_t),
  };
  ESP_LOGI(TAG, "Initializing SPI Bus...");
  ESP_ERROR_CHECK(spi_bus_initialize(LCD_SPI_HOST, &buscfg, SPI_DMA_CH_AUTO));

  // 3. Initialize Panel IO
  ESP_LOGI(TAG, "Configuring LCD IO...");
  esp_lcd_panel_io_handle_t io_handle = NULL;
  esp_lcd_panel_io_spi_config_t io_config = {
      .dc_gpio_num = LCD_GPIO_DC,
      .cs_gpio_num = LCD_GPIO_CS,
      .pclk_hz = 40 * 1000 * 1000, // Reduced to 40MHz for debug stability
      .lcd_cmd_bits = 8,
      .lcd_param_bits = 8,
      .spi_mode = 0,
      .trans_queue_depth = 10,
      .on_color_trans_done =
          NULL, // flush_ready is called directly in lvgl_flush_cb
      .user_ctx = NULL,
  };
  ESP_ERROR_CHECK(esp_lcd_new_panel_io_spi((esp_lcd_spi_bus_handle_t)LCD_SPI_HOST,
                                           &io_config, &io_handle));

  // 4. Initialize Panel Driver
  esp_lcd_panel_dev_config_t panel_config = {
      .reset_gpio_num = LCD_GPIO_RST,
      .rgb_ele_order = LCD_RGB_ELEMENT_ORDER_BGR,
      .bits_per_pixel = 16,
  };
  ESP_LOGI(TAG, "Creating LCD Panel...");
  ESP_ERROR_CHECK(
      esp_lcd_new_panel_gc9a01(io_handle, &panel_config, &panel_handle));
  ESP_LOGI(TAG, "Resetting and Initializing Panel...");
  ESP_ERROR_CHECK(esp_lcd_panel_reset(panel_handle));
  ESP_ERROR_CHECK(esp_lcd_panel_init(panel_handle));
  ESP_LOGI(TAG, "Setting Inversion, Mirror, and Rotation...");
  ESP_ERROR_CHECK(esp_lcd_panel_invert_color(panel_handle, true));
  ESP_ERROR_CHECK(esp_lcd_panel_mirror(panel_handle, true, true));
  ESP_ERROR_CHECK(esp_lcd_panel_swap_xy(panel_handle, true));
  ESP_ERROR_CHECK(esp_lcd_panel_disp_on_off(panel_handle, true));
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

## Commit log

2026-04-19 chore: Rename project to NexusIR
    [partitions.csv]
2026-04-25 feat: implement robust ESP-NOW synchronization and HomeKit stability improvements
    - Added mgr_relay component for relay device management
    - Implemented symmetric bridge callbacks and recursion guard in svc_espnow
    - Enhanced HomeKit stability and mDNS registration
    - Updated IR protocol main logic and device state synchronization for Fan and AC
    - Improved Wi-Fi provisioning and button driver integration
    - Updated .gitignore to exclude .cache/
    [drv_button.c, mgr_ir_main.c]
2026-04-27 feat: implement weather station UI and improve system stability
    - Added mgr_display and svc_weather components for circular LCD weather station
    - Implemented real-time weather icons (Open-Meteo API) and day/night themes
    - Fixed critical boot loop caused by flash size mismatch (forced 4MB)
    - Resolved WiFi scan issues during provisioning by managing STA connection state
    - Fixed stack overflow in ui_time task and increased UI lock timeouts for stability
    - Added hardware-level screen rotation (180 deg)
    - Implemented conditional compilation to allow building without LCD support
    - Updated GPIO mappings for ESP32-S3 hardware revision
    [partitions.csv]
2026-04-27 Refactor: Sync project branding to NexusIR
    - Renamed OTA endpoints and firmware binary to nexus-ir.bin
    - Updated Web UI titles, headers, and SSID placeholders
    - Cleaned up legacy/duplicate source files in component roots
    - Updated TAGs and internal namespaces from Goku to Nexus
    - Fixed includes in int_rainmaker module
    - Integrated ota_server (excluding DB and cache)
    [drv_button.c, mgr_display.c]
2026-05-10 release: v1.3.0 – RainMaker-only provisioning, WebUI toggle, OTA hardening
    [partitions.csv]
2026-05-10 v1.4.1: RainMaker improvements, log suppression, ESP32-S3 PSRAM fix
    Changes:
    - Auto-restore AC state in RainMaker on boot (like HomeKit)
    - Round sensor values to 1 decimal for cleaner display
    - Suppress esp_rmaker_param INFO logs to reduce spam
    - Fix ESP32-S3 build: restore free_psram variable for PSRAM checks
    - Fix goku_rainmaker build dependencies and unused function
    - Add goku_homekit, goku_sensor, goku_wifi_portal, app_hap_setup_payload components
    - Update mDNS hostname to gokuac with service refresh
    - Add DHCP Option 114 for captive portal trigger
2026-05-10 docs: Update README.md for v1.4.1 with dual platform and sensor support
2026-06-13 feat(hardware): add 3D print assets, images, and document enclosure design in README
    [Body.3mf, Button.3mf, Holder.3mf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]
2026-06-13 feat(firmware): add pre-compiled sample binaries for esp32 and esp32c3 (android/ios) and fix freertos include in espnow service
2026-07-17 refactor(main): add #ifdef guards for unused components
    - Guard RainMaker includes/constructor with CONFIG_LAMP_PLATFORM_ANDROID
    - Guard ESP-NOW bridge adaptors with CONFIG_APP_ESPNOW_BRIDGE_ENABLE
    - Guard ESP-NOW slave adaptors with BRIDGE_ENABLE || SLAVE_ENABLE
    - Guard mgr_ir_init() for AC/Fan Slave/Standalone only
    - Guard mgr_relay_init() with !CONFIG_APP_ESPNOW_RELAY_DISABLED
    - Guard svc_espnow_init() and handler registration with ESP-NOW flags
    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
2026-07-18 docs: rewrite README.md concise + add README_VI.md (Vietnamese)
    - Restructured README to be scannable with tables and clear sections
    - Covers: features, architecture, hardware, quick start, menuconfig, firmware, web UI, 3D case
    - Added Vietnamese translation with cross-links between both versions
2026-07-18 feat: updates core components, web assets, and configurations
    - Update Kconfig and sdkconfig.defaults
    - Implement LED strip driver improvements and HomeKit integration fixes
    - Update OTA service and wifi handling
    - Optimize local OTA server Web UI assets (HTML, JS, CSS)
    - Add ota_server startup script and static files
    [drv_led.c]
2026-09-27 feat: complete IR Core V3, host unit tests, local OTA flasher, and Web Flasher for GitHub Pages
    [Body.3mf, Button.3mf, Holder.3mf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]
2026-10-12 fix: Increase MAX_IR_SYMBOLS and RMT idle timeout for long AC commands
    - Increased `MAX_IR_SYMBOLS` from 600 to 1200 words (2400 edges) to support long and complex AC protocols like Panasonic and Daikin.
    - Increased RMT RX `signal_range_max_ns` from 30ms to 60ms to correctly capture repeating frames separated by long gaps.
    - Ensured AC Matrix saves entire RAW sequences including repeats without truncating.
